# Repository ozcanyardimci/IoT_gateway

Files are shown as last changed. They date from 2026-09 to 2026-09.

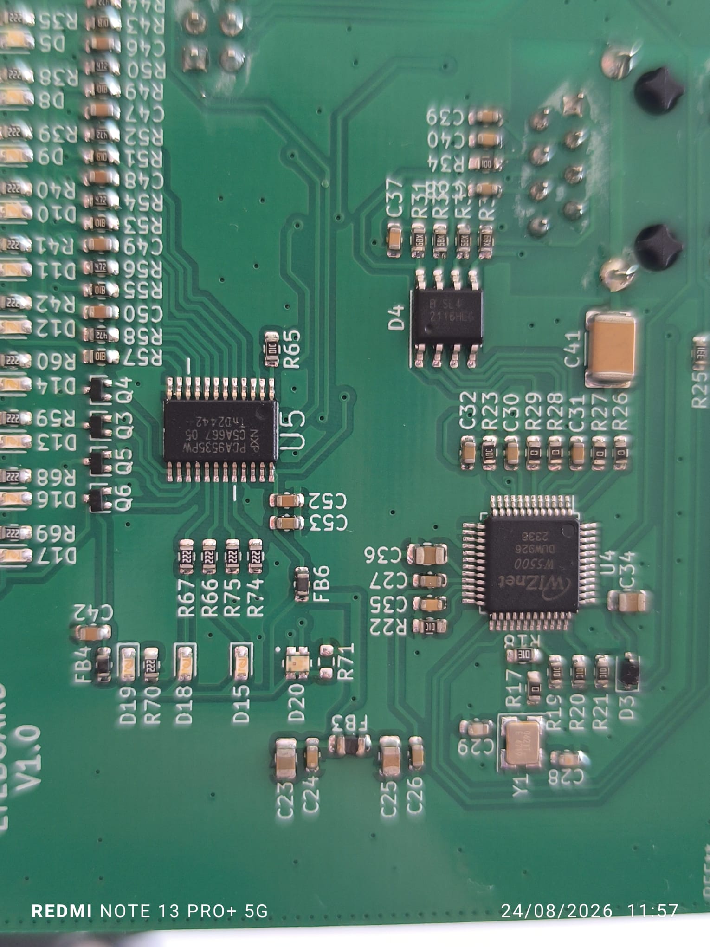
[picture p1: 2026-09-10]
reference-photos/2026-09-08-hardware-assembly-photos/photo_18_0372ed8b.jpg

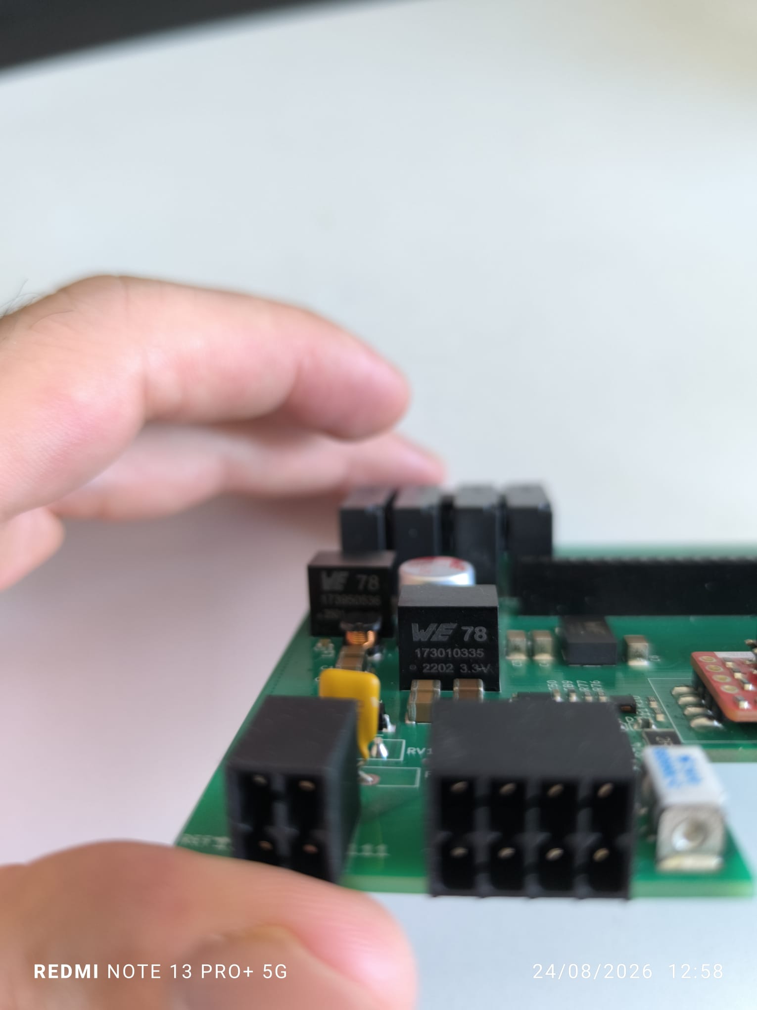
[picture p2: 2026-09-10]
reference-photos/2026-09-08-hardware-assembly-photos/photo_09_d7df375a.jpg

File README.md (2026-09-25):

# IoT_gateway

A 4G/LTE industrial IoT gateway, designed and built from the ground up as a hands-on
learning project spanning electronics, PCB design (KiCad), and embedded firmware
(ESP32-S3, PlatformIO/Arduino).

## What it does

- LTE Cat-1 cellular connectivity (with 2G fallback), WiFi, and 10/100 Ethernet
- 8x optically isolated digital inputs, 4x relay outputs
- Analog I/O (0-10V / 4-20mA input, 0-10V output)
- RS485 (galvanically isolated) and RS232 (not isolated — see `docs/subsystems/power.md`'s
  isolation table) serial interfaces
- 10-30 VDC field power input, DIN-rail enclosure target
- Firmware: web UI (commissioning portal), Modbus TCP/RTU master, MQTT (with TLS + resilience), OTA updates with rollback and signature verification, and a WireGuard VPN tunnel

## Architecture

Two physically separate PCBs connected by a board-to-board header, split for noise
isolation — RF/clock-sensitive circuitry stays off the same board as switching-noisy
circuitry:

- **Communications board** — ESP32-S3 (main MCU + WiFi), LTE modem, Ethernet controller,
  I2C GPIO expander for status indication.
- **I/O board** — power regulation, relay outputs, RS485/RS232 transceivers, analog
  input/output signal conditioning.

## Repository structure

```
hardware/
  kicad/              KiCad schematic + PCB projects (one per board)
  datasheets/          Component datasheets
  bom/                 Bill of materials
  reference-designs/   Vendor reference designs used during design
firmware/
  platformio.ini       PlatformIO project config (ESP32-S3, pioarduino platform)
  src/                 Firmware source
  include/, lib/       Headers / project-local libraries
docs/
  architecture.md       Block diagram and subsystem breakdown
  roadmap.md            Top-level 10-step plan and subsystem order/status
  build-log.md          Incremental build/bring-up log
  subsystems/           Per-subsystem build plans (requirements through sign-off)
```

## Build methodology

Built subsystem-first: each subsystem (power, core compute, WiFi, LTE, Ethernet, digital
I/O, relay outputs, analog I/O, RS485, RS232, status indication) is validated in isolation
before being consolidated into the final two-board design — simulation-first (KiCad/ngspice
for power and analog circuits), then a Rev-A prototype PCB as the first real hardware
checkpoint, ahead of committing to the full two-board fabrication run.

See `docs/architecture.md` and `docs/build-log.md` for details as the project progresses.

## Status

**Hardware:** all 11 subsystems complete on paper (power, core compute, digital inputs,
relay outputs, status indication, analog I/O, RS485, RS232, Ethernet, WiFi, LTE) —
protection, regulation, part selection, and schematic capture done for each, verified
pin-by-pin against manufacturer documentation. Both boards' schematics are merged into
one KiCad project (`hardware/kicad/ioboard+lteboard/`, see `docs/board-merge.md`),
fine-grained MCU pin assignment and the board-to-board connector are both wired, and a
full project-wide Electrical Rules Check passes clean (2026-09-23). Not yet built as
real hardware — Rev-A prototype PCB is the next physical milestone (`docs/roadmap.md`
step 8).

**Firmware:** the full protocol/driver/industrial/system-integration stack (Modbus,
MQTT+TLS, OTA with rollback and signature verification, WireGuard, rule engine, task
scheduler/watchdog, LTE-PPP backhaul, and more) is written and build-verified — a real
`pio run` links and flashes a complete image, and all 132 native unit tests pass
(2026-09-25). What's left needs the Rev-A hardware above: nothing in the firmware has
been exercised against real peripherals yet (`docs/roadmap.md`'s F5). See
`docs/build-log.md` and `docs/roadmap.md` for the full detail.

## License

TBD.

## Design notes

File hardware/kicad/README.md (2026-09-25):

# KiCad projects

Two physically separate PCBs (noise isolation between the communications board and the
I/O board), captured as one merged KiCad schematic project.

- **ioboard+lteboard/** — the active project. Both boards' subsystem sheets in one
  hierarchy:
  - IOBOARD side: `power`, `analog_io`, `digital_inputs`, `relay_outputs`, `rs232`,
    `rs485`
  - LTEBOARD side: `core-compute` (also carries WiFi — the ESP32-S3-WROOM-1U's radio is
    fixed at the module, WiFi only added an external antenna path here), `ethernet`,
    `lte`, `status_indication`

  The two boards are marked on the root sheet with a graphic border and label around each
  cluster of subsystem sheets — visual grouping only, no electrical meaning. This is
  where all schematic work happens going forward. Fine-grained pin assignment
  and the board-to-board interconnect wiring (the reason for the merge) are both done as
  of 2026-09-22/23, ERC-clean — see `docs/board-merge.md` for what the merge covered and
  what's verified connected, and a known open question about producing two separate
  physical-board PCB files from this one project at layout time.

- **ioboard/**, **lteboard/** — the original per-board projects, frozen as of the
  2026-09-19 merge. Kept as the historical record of each board's schematic capture up to
  that point; not edited further.

Each project uses hierarchical sub-sheets, one per subsystem (e.g. `power.kicad_sch`,
`relay_outputs.kicad_sch`).

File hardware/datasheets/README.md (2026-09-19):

# Datasheets, sources & application notes

Links only — no PDF binaries in this repo. Keeps repo size manageable, avoids stale local
copies of documents the manufacturer updates over time, and avoids redistributing
copyrighted PDFs. Updated as each subsystem is worked through.

## Power subsystem

| Part | Role | Datasheet / source |
|---|---|---|
| ESP32-S3-WROOM-1U | Main MCU module | [Espressif datasheet](https://documentation.espressif.com/api/resource/doc/file/3yD6w5Y5/FILE/esp32-s3-wroom-1_wroom-1u_datasheet_en.pdf) |
| Quectel EG915U-EU | LTE Cat-1 modem | [Quectel EG915U Series Hardware Design v1.1](https://quectel.com/content/uploads/2024/02/Quectel_EG915U_Series_Hardware_Design_V1.1.pdf) |
| WIZnet W5500 | SPI Ethernet controller | [WIZnet datasheet v1.1.0](https://docs.wiznet.io/img/products/w5500/W5500_ds_v110e.pdf) |
| NXP PCA9535PW | I2C GPIO expander | [NXP datasheet](https://www.nxp.com/docs/en/data-sheet/PCA9535_PCA9535C.pdf) · [TI second source](https://www.ti.com/lit/ds/symlink/pca9535.pdf) |
| MAX3232E | RS232 transceiver | [ADI/Maxim MAX3222E-MAX3246E family datasheet](https://www.analog.com/media/en/technical-documentation/data-sheets/max3222e-max3246e.pdf) |
| Mornsun TD321S485H-A | Isolated RS485 module | [Mornsun datasheet](https://www.mornsun-power.com/public/uploads/pdf/TD5(3)21S485H-A.pdf) |
| Panasonic ALDP105 | Relay (x4) | [Panasonic product page](https://na.industrial.panasonic.com/products/relays-contactors/mechanical-power-relays/lineup/general/series/1988/model/136824) · [Future Electronics PDF](https://www1.futureelectronics.com/doc/Panasonic/ALDP105.pdf) |
| Lite-On LTV-247 | Digital-input optocoupler | [Datasheet via LCSC](https://datasheet.lcsc.com/datasheet/pdf/6ec3b014c2c1b1e2589a5b88a431fe52.pdf?productCode=C115451) |
| AME8808 | Analog LDO | AME8808's own sheet isn't available in extractable form — using the AME8805/8813 same-family sheet as reference: [AME datasheet](https://www.ame.com.tw/datasheet/11-AME8805%208813_061313_R.13.pdf) |
| LM2904 | Analog stage op-amp | [Diodes Inc. LM2902/LM2904 datasheet](https://www.diodes.com/assets/Datasheets/LM2902-04.pdf) |

## Power modules & protection components

| Part | Role | Datasheet / source |
|---|---|---|
| Würth MagI3C-VDLM 171013801 | 3.3V-LOGIC and 5V rail buck module (two instances) | [Datasheet](https://www.we-online.com/en/components/products/datasheet/171013801.pdf) |
| Würth MagI3C-VDLM 171033801 | `VBAT_LTE` rail buck module (renamed from `3V3_LTE` 2026-09-13 — output retapped to ~3.82V, matching Quectel's typical VBAT, see `power.md` revision history), 3A | [Datasheet](https://www.we-online.com/components/products/datasheet/171033801.pdf) |
| Recom R1SX-3.33.3-R | Isolated supply, analog input field side, 3.3V-in/3.3V-out | [Recom datasheet](https://recom-power.com/pdf/Econoline/R1SX.pdf) · [DigiKey](https://www.digikey.com/en/products/detail/recom-power/R1SX-3.33.3-R/6708875) |
| Littelfuse RXEF135 | Input PTC resettable fuse | [Datasheet](https://www.littelfuse.com/assetdocs/resettable-ptc-rxef-datasheet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) |
| TI LM74610-Q1 | Ideal diode controller, reverse-polarity protection | [Datasheet](https://www.ti.com/lit/ds/symlink/lm74610-q1.pdf) |
| TI CSD18531Q5A | 60V N-channel MOSFET, driven by LM74610-Q1 | [Product page](https://www.ti.com/product/CSD18531Q5A) |
| TI TVS3300 | Input surge TVS, Flat-Clamp technology, 33V standoff, 40V max clamp at 35A | [Datasheet](https://www.ti.com/lit/ds/symlink/tvs3300.pdf) · [Product page](https://www.ti.com/product/TVS3300) |
| Würth WCAP-CSSA 8853522140011 | Input EMI/safety Y-cap | [Datasheet](https://www.we-online.com/components/products/datasheet/8853522140011.pdf) |
| Recom RK-0515S | Isolated 15V DC-DC module, analog output gain-stage supply (U7) | [Recom Econoline family PDF](https://recom-power.com/pdf/Econoline/RK_RH.pdf) — added 2026-09-08 for analog-io's "15V problem"; 3kVDC isolation stated directly, no re-verification gap |

Superseded parts (kept for traceability — see `docs/subsystems/power.md` revision history
for why): Toshiba SSM3J351R,LF (replaced by LM74610-Q1 + CSD18531Q5A), Littelfuse SMBJ36A
(replaced by TVS3300), Recom R1SX-3305 (replaced by R1SX-3.33.3-R — wrong output voltage
for the rail), Recom R05P215S (replaced by RK-0515S for the 15V-ANALOG-ISO rail —
unresolved isolation-rating gap on the R05P215S datasheet pull, see
`docs/subsystems/analog-io.md`'s revision history).

## Core compute subsystem

| Part | Role | Datasheet / source |
|---|---|---|
| Espressif ESP32-S3-WROOM-1U-N16R8 | Main MCU module | [Datasheet](https://documentation.espressif.com/api/resource/doc/file/3yD6w5Y5/FILE/esp32-s3-wroom-1_wroom-1u_datasheet_en.pdf) |
| Molex 216989-0001 | USB-C receptacle, USB2.0-only, 14-pin | [DigiKey product page](https://www.digikey.com/en/products/detail/molex/2169890001/13913746) |
| E-Switch TL1150AF070Q | Manual reset/boot push buttons (SW1, SW2) | [DigiKey product page](https://www.digikey.com/en/products/detail/e-switch/TL1150AF070Q/1556582) |

| Document | Covers | Source |
|---|---|---|
| Espressif ESP32-S3 Hardware Design Guidelines — Schematic Checklist | EN RC delay (10k+1uF), GPIO0 pull-up guidance, decoupling values/placement, USB D+/D- series resistor guidance | [Page](https://docs.espressif.com/projects/esp-hardware-design-guidelines/en/latest/esp32s3/schematic-checklist.html) |
| esptool documentation — Boot Mode Selection (ESP32-S3) | GPIO0's internal 45k pull-up and the need for an external 10k pull-down (not pull-up) to reliably enter download mode | [Page](https://docs.espressif.com/projects/esptool/en/latest/esp32s3/advanced-topics/boot-mode-selection.html) |

## Digital inputs subsystem

| Part | Role | Datasheet / source |
|---|---|---|
| Lite-On LTV-247 | 4-channel opto-isolator, digital inputs (x2 for 8ch) | [DigiKey product page](https://www.digikey.com/en/products/detail/liteon/LTV-247/4307982) - [LCSC product page](https://www.lcsc.com/product-detail/SMD-Optocouplers_LTV-247_C115451.html) - [Lite-On LTV-2X7 family datasheet](https://datasheet.lcsc.com/datasheet/pdf/6ec3b014c2c1b1e2589a5b88a431fe52.pdf?productCode=C115451) |
| Phoenix Contact MC 1,5/9-ST-3,5 | 8-channel + common field connector (J2) | [Newark product page](https://www.newark.com/phoenix-contact/mc-1-5-9-st-3-5/plug-free-3-5mm-9way/dp/14J3299) |

## Relay outputs subsystem

| Part | Role | Datasheet / source |
|---|---|---|
| Panasonic ALDP105 | SPST-NO relay (x4) | [Panasonic product page](https://na.industrial.panasonic.com/products/relays-contactors/mechanical-power-relays/lineup/general/series/1988/model/136824) · [Future Electronics PDF](https://www1.futureelectronics.com/doc/Panasonic/ALDP105.pdf) |
| Nexperia MMBT3904 | NPN driver transistor (one per relay channel) | [Nexperia datasheet](https://assets.nexperia.com/documents/data-sheet/MMBT3904.pdf) |
| Phoenix Contact MC 1,5/8-ST-3,5 | 8-position (4x COM+NO independent) field connector | [Newark product page](https://www.newark.com/phoenix-contact/mc-1-5-8-st-3-5/pluggable-terminal-block-8-position/dp/14J3298) · [Farnell product page](https://ie.farnell.com/phoenix-contact/mc-1-5-8-st-3-5/terminal-block-pluggable-8pos/dp/5089013) |

## Status indication subsystem

PCA9535PW (I2C GPIO expander) is already listed under "Power subsystem" above — no separate
entry needed, same reuse pattern as LM2904 under "Analog I/O subsystem" below. The 6 status
LEDs are generic 3mm THT parts (red/green/yellow/orange family, chosen for their ~1.8-2.2V
forward voltage — see `docs/subsystems/status-indication.md` Step 4 for why), no specific
manufacturer/part-number match — same "generic, no sourcing risk" treatment as this
project's standard passives.

## Analog I/O subsystem

| Part | Role | Datasheet / source |
|---|---|---|
| TI ADS1115 | 16-bit I2C ADC, isolated side (analog inputs) | [TI datasheet](https://www.ti.com/lit/ds/symlink/ads1115.pdf) |
| TI ISO1540 | I2C digital isolator, both channels bidirectional | [TI datasheet](https://www.ti.com/lit/ds/symlink/iso1541.pdf) (covers both ISO1540/ISO1541 in one document) |
| Microchip MCP4725 | 12-bit I2C DAC, isolated side (analog output) | [Microchip datasheet](https://ww1.microchip.com/downloads/en/devicedoc/22039d.pdf) |
| Littelfuse SMBJ15CA | Bidirectional TVS, analog input overvoltage protection (x2) | [Littelfuse datasheet](https://www.littelfuse.com/assetdocs/tvs-diodes-smbj-series-datasheet) |
| Phoenix Contact MC 1,5/4-ST-3,5 | 4-position field connector (AI1/AI2/AO + shared return) | [Newark product page](https://www.newark.com/phoenix-contact/mc-1-5-4-st-3-5/pluggable-terminal-block-4-position/dp/14J3294) |

The 15V-ANALOG-ISO supply module belongs to `power.kicad_sch`, not this sheet — see Recom
RK-0515S under "Power modules & protection components" above. An earlier candidate for that
rail, Recom R05P215S, is listed there under superseded parts (unresolved isolation-rating
gap, never actually implemented).

LM2904 (input buffers + output gain stage, 2 physical instances) reuses the part already
listed under "Power subsystem" above — no separate entry needed.

## RS485 subsystem

Protection network (GDT/TVS/choke/bias resistors) is Mornsun's own "Fig. 2: Port
protection circuit for harsh environments" from the transceiver's datasheet, not a
generic cascade — see `docs/subsystems/rs485.md` Step 2 for the full reasoning.

| Part | Role | Datasheet / source |
|---|---|---|
| Mornsun TD321S485H-A (TD5(3)21S485H-A series) | Isolated RS485 transceiver module | [Mornsun datasheet](https://www.mornsun-power.com/public/uploads/pdf/TD5(3)21S485H-A.pdf) — full PDF obtained 2026-09-08 (user-supplied): 3kVDC isolation, 500kbps max, built-in 47kΩ A/B pull-down, confirmed 10-pin pinout, and the harsh-environment reference circuit (Fig. 2) this section's other parts come from |
| Bencent B3D090L-C (GD1) | Gas discharge tube (GDT), 3-electrode: line pins wired A-B, third (common) electrode bonds to `EARTH` | [LCSC product page](https://www.lcsc.com/product-detail/Gas-Discharge-Tube-GDT_Bencent-B3D090L-C_C511253.html) — 90V DC spark-over, 5kA @ 8/20µs, 3-pole, 1.5pF. Doubly confirmed: flagged from the original teardown, and Mornsun's own datasheet names the base part "B3D090L" directly |
| Littelfuse SMBJ6.5CA (x3, D15/D18/D19; Mornsun Fig. 2 D1/D2/D3) | Bidirectional TVS diodes — D15 A-B differential clamp, D18/D19 line-to-EARTH clamp | [Littelfuse SMBJ series datasheet](https://www.littelfuse.com/assetdocs/tvs-diodes-smbj-series-datasheet) · [DigiKey](https://www.digikey.com/en/products/detail/littelfuse-inc/SMBJ6-5CA/285958) — 600W, DO-214AA. Mornsun-specified exact part. Same SMBJ family already used for analog-input protection (SMBJ15CA) |
| TDK ACM2520-301-2P (U14) | Common-mode choke (Mornsun Fig. 2 T1) | [TDK product page](https://product.tdk.com/en/search/emc/emc/cmf_cmc/info?part_no=ACM2520-301-2P-T002) · [LCSC](https://www.lcsc.com/product-detail/Common-Mode-Filters_TDK-ACM2520-301-2P-T002_C76577.html) — Mornsun-specified exact part |
| Generic 2.7Ω/2W (R34, R35; Mornsun Fig. 2 R1/R2) | Series current-limiting resistors | Mornsun-specified value/power rating |
| Generic 1MΩ (R36; Mornsun Fig. 2 R3) + 1nF/2kV (C23; Mornsun Fig. 2 C1) | RC snubber to EARTH | Mornsun-specified |
| Generic 4.7kΩ (R_pullup1, R_pulldown1) | External bias — Rpullup: VO (pin 7) to A; Rpulldown: RGND (pin 10) to B | Mornsun specifies only a current ceiling (<25mA) on VO/RGND, not a resistance — 4.7kΩ gives ≈1.1mA worst case, well inside that ceiling; picked and locked on the schematic 2026-09-10 |
| Phoenix Contact MC 1,5/3-ST-3,5 (J5) | 3-position field connector (A, B, EARTH) | [Newark product page](https://www.newark.com/phoenix-contact/mc-1-5-3-st-3-5/pluggable-terminal-block-3-position/dp/14J3293) — MPN 1840379 |

Superseded (2026-09-08, same day — kept here for traceability, not because they were
wrong parts, just replaced by Mornsun's own tested circuit once its datasheet was fully
readable): Bourns CDSOT23-SM712 (TVS), Würth WE-SL2 744227 (common-mode choke), generic
27Ω series resistors.

## RS232 subsystem

No dedicated protection component — decided against an added TVS network; see
`docs/subsystems/rs232.md` decision 3 for the full reasoning (datasheet's own application
circuit has none, receiver is separately rated safe to ±25V unpowered, and reference-design
photo evidence shows no dedicated protection stage for this port, unlike RS485).

| Part | Role | Datasheet / source |
|---|---|---|
| TI MAX3232EIPWR | RS232 transceiver, TSSOP-16, one channel used (DIN1/DOUT1/RIN1/ROUT1); channel 2 left unconnected | [TI MAX3232E datasheet](https://www.ti.com/lit/ds/slls664c/slls664c.pdf) — corrected 2026-09-10 from an earlier placeholder ("MAX3232EI" alone isn't a real SKU); picked over the ADI/Maxim equivalent (MAX3232EEUE+) for SnapEDA symbol/footprint availability |
| Phoenix Contact MC 1,5/3-ST-3,5 | 3-position field connector (TXD, RXD, GND) | [Newark product page](https://www.newark.com/phoenix-contact/mc-1-5-3-st-3-5/pluggable-terminal-block-3-position/dp/14J3293) — MPN 1840379, same part reused from RS485's connector (J5) |

## Ethernet subsystem

Schematic capture done 2026-09-13, cross-checked against WIZnet's own reference schematic
and, for the magjack, against both the reference-hardware's own LTEBOARD photos and the
part's own datasheet (read directly, not summarized) — see `docs/subsystems/ethernet.md`
for the full component list and decision history.

| Part | Role | Datasheet / source |
|---|---|---|
| WIZnet W5500 | SPI-to-MAC+PHY, 10/100 Ethernet | [W5500 datasheet v1.1.0](https://docs.wiznet.io/img/products/w5500/W5500_ds_v110e.pdf) — re-confirmed 2026-09-10 (pinout, crystal spec, SPI timing, LED pin behavior); chip visually matched on the reference LTEBOARD too; AVDD pin count corrected 2026-09-13 against the real KiCad symbol (6 pins: 4, 8, 11, 15, 17, 21 — not 4) |
| Würth Elektronik 7499010441 (WE-RJ45LAN) | RJ45 jack with integrated 1:1 transformer, 2 bi-color LEDs | [Datasheet](https://www.we-online.com/components/products/datasheet/7499010441.pdf) — full PDF read directly 2026-09-13 (user-supplied, not a summary): confirms isolation ≥1500V RMS, turns ratio, LED specs, AND the termination network — CTD/CRD terminated internally (75Ω/75Ω + 0.001µF/2kV + GDTs) into a combined "GND Shield" node (pin 8 + both shield pins are one net). Termination is now CONFIRMED integrated, no external Bob-Smith network needed — upgraded from the earlier "high confidence, not pin-level-guaranteed" call; see `docs/subsystems/ethernet.md` decision 4. Cross-checked against two related datasheets (Würth 7499011441A, Cetus J1B1211CCD) showing the same internal topology |
| Generic 0603 ferrite bead (FB1) | AVDD filtering, `3V3_LOGIC` → `3V3A` | WIZnet forum support guidance (named `HH-1M1608-121JT`, but any bead meeting spec works): 120Ω @ 100MHz (90Ω min), DCR 200mΩ max, 1A max rated current — confirmed via a real datasheet on inductor.com. Sourcing equivalents: Murata BLM18PG121SN1D, TDK MPZ1608S121A |

## WiFi subsystem

Radio itself is the ESP32-S3-WROOM-1U module, already covered under "Core compute
subsystem" above — nothing new to add there. This section is just the external antenna
path (J2), confirmed 2026-09-13 against the reference-hardware LTEBOARD photos (module
U.FL -> coax pigtail -> PCB-mount SMA jack, no PCB RF trace) and against the module's own
datasheet for the antenna gain ceiling.

| Part | Role | Datasheet / source |
|---|---|---|
| Amphenol RF 132163 | J2 - board-side SMA female jack, 2-hole flange, PCB/panel mount | [Product page](https://www.amphenolrf.com/en-us/part/132163/1014/) - representative real part matching the reference-hardware connector style; exact sourced part may differ, footprint deferred to layout |
| Generic U.FL-to-SMA pigtail | Coax jumper, module's onboard U.FL jack to J2, RG178, ~10-15cm | Reference-hardware photos (topology); no PCB trace involved, generic assembly |
| Waveshare "SMA 2.4G 2DB Antenna" | External antenna, SMA-male, 2dBi | [Product page](https://www.waveshare.com/sma-2.4g-2db-antenna.htm) - chosen to stay under the module's 2.33dBi certified-antenna gain ceiling (see below) |

**Antenna gain ceiling — from the module's own datasheet, not a general guideline:**
Espressif's ESP32-S3-WROOM-1U datasheet states the module's FCC/CE certification used a
2.33dBi reference antenna, and a higher-gain or different-type antenna "may require
additional testing, such as EMC." A generic 3dBi rubber-duck antenna would exceed that;
picked a 2dBi part instead to stay inside the certified envelope with margin.

## LTE subsystem

Quectel EG915U-EU Cat-1 modem (+2G fallback), on its own `VBAT_LTE` rail and one of the
project's 3 hardware UARTs. Own antenna path (same coax-pigtail/SMA-jack pattern as WiFi
above), own power-control (PWRKEY/RESET_N) circuit, and a level-shifted UART to a
micro-SIM interface. See `docs/subsystems/lte.md` for the full build plan, and
`hardware/bom/lte_bom.csv` for the complete part list. Schematic capture (Step 4) is
largely complete, including the UART level shifter (U5) — checked and confirmed correctly
wired 2026-09-19; see `lte.md` Step 4 for details.

| Part | Role | Datasheet / source |
|---|---|---|
| Quectel EG915UEUAC-N05-SNNSA | LTE Cat-1 modem, EU band variant | [Quectel EG915U Series Hardware Design v1.1](https://quectel.com/content/uploads/2024/02/Quectel_EG915U_Series_Hardware_Design_V1.1.pdf) (also listed under "Power subsystem" above) |
| TI TXB0102DCUR | 2-channel level shifter, 1.8V<->3.3V UART | [Datasheet](https://www.ti.com/lit/gpn/txb0102) |
| JAE SF53S006VCBR2000 | Micro-SIM push-push holder (J4), 6-contact | Matches reference-hardware LTEBOARD's SIM holder (`reference-photos/2026-09-08-hardware-assembly-photos/photo_23`, `photo_29`, `photo_30`) |
| STMicroelectronics ESDA6V1BC6 | SIM interface ESD protection, quad TVS array (SOT23-6L) | Confirmed on SnapEDA and in stock via Mouser's Turkey storefront (2026-09-15) |
| Littelfuse/Bourns SMAJ5.0A (representative) | VBAT reverse-standoff TVS protection | Closest standard part to Quectel's guidance (4.7V isn't a catalog value; 5.0V is the nearest step at or above it) |
| TE Connectivity/Linx ANT-LTE-MON-SMA-L | Off-board wideband antenna (~617MHz-3.8GHz), SMA, tilt/swivel | DigiKey/Mouser listings (2026-09-14) — band figure from distributor text only, not an independently-pulled Linx PDF |
| Quectel EG915U Series Reference Design v1.1 | ANT_MAIN matching network topology, SIM interface reference figures, PWRKEY/RESET_N driving circuits | [PDF](https://images.quectel.com/python/sites/2/2023/05/Quectel_EG915U_Series_Reference_Design_V1.1.pdf) |

**Still open / not yet a real sourced part:** J3 (board-side SMA jack — placed as a generic
`Conn_Coaxial` symbol, no MPN picked yet, same style as WiFi's J2 above); D4 (antenna ESD
diode — Quectel's own spec, <=0.05pF/<=5V, doesn't match any real catalog part found so far;
closest candidate is Littelfuse PGB1010603, but its 24V standoff exceeds the 5V ceiling —
see `lte.md` decision 7 addendum); Q4/Q5 (PWRKEY/RESET_N driver transistors — any generic
small-signal NPN works, e.g. MMBT3904/BC847; Rohm DTC043ZEBTL is a pre-biased single-part
alternative if BOM count matters later).

## Connectors & wiring standards

| Item | Role | Source |
|---|---|---|
| Phoenix Contact MC 1,5/2-ST-3,5 | Power input terminal block | [Datasheet](https://www.mouser.com/datasheet/3/507/5/phoenix_contact_1840366_en.pdf) |
| NFPA 70 (NEC) Table 310.15(B)(16) | Wire ampacity reference | Standard reference, consult a current NEC copy |
| Engineering ToolBox AWG current-rating table | Wire ampacity cross-check | https://www.engineeringtoolbox.com/wire-gauges-d_419.html |

## Application notes & reference designs

| Document | Covers | Source |
|---|---|---|
| TI TIDUBP3A — Reverse Battery Protection LM74610-Q1 | Reference design for the reverse-polarity stage: schematic, part selection, rated for 12/24V systems with load-dump survival past 30V | [PDF](https://www.ti.com/lit/ug/tidubp3a/tidubp3a.pdf) |
| TI SLYY127 — Flat-Clamp surge protection technology | Active-feedback clamping mechanism behind TVS3300 | [PDF](https://www.ti.com/lit/slyy127) |
| TVS3300 datasheet, Section 9 | TVS3300's own typical application circuit and layout guidance | [PDF](https://www.ti.com/lit/ds/symlink/tvs3300.pdf) |
| TI SLVA862 — Basics of eFuses | Background on inrush/reverse-polarity/overvoltage protection concepts | ti.com application report SLVA862 |
| WIZnet hardware design guide | Generic decoupling (0.1uF bypass, 10uF/4.7uF bulk, 3.3V regulator >=300mA) | [WIZnet Design Guide](https://docs.wiznet.io/Design-Guide/hardware_design_guide) |
| WIZnet W5500 reference schematic | Transformer/RJ45 config, isolation capacitors | [WIZnet W5500 ref-schematic](https://docs.wiznet.io/Product/Chip/Ethernet/W5500/ref-schematic) — full PDF variant (bare-transformer magjack, external Bob-Smith termination): [w5500-ref-rj45with20150406.pdf](https://docs.wiznet.io/img/products/w5500/w5500-ref-rj45with20150406.pdf), pulled 2026-09-10 for crystal/EXRES1/TOCAP/LED-resistor cross-check |
| Bourns RS-485 Port Protection Evaluation Board design note | GDT + series-limiting + TVS cascade topology reference for RS485 lines (uses a TBU current limiter instead of plain resistors — informed this project's cascade order, not its exact parts) | [PDF](https://www.bourns.com/docs/technical-documents/technical-library/circuit-protection/design-notes/bourns_rs485_evalboard4_design_note.pdf) |
| Würth ANP083 — RS-485 EMI filtering app note | Common-mode choke placement on an RS-485 interface (WE-SL2 family) | Referenced via Würth's WE-SL2 product page; direct PDF link 404'd 2026-09-08, retry before finalizing layout |

No single vendor app note covers this exact combination (wide 10-30V input protection with
multiple MagI3C modules) — the protection sequencing (fuse -> reverse-polarity ->
surge/TVS -> regulation) follows standard practice but isn't cross-checked against one
authoritative reference document.

## Reference open-hardware projects (patterns only, not copied)

| Project | Use |
|---|---|
| [espressif/kicad-libraries](https://github.com/espressif/kicad-libraries) | Official KiCad symbols/footprints |
| [OLIMEX/ESP32-GATEWAY](https://github.com/OLIMEX/ESP32-GATEWAY) | General ESP32 + Ethernet KiCad project structure reference only — its power stage isn't reusable (USB-powered, no field-voltage input) and its license status is unresolved (LICENSE says Apache-2.0, manual says CERN-OHL) |
| [Walter (QuickSpot/DPTechnics)](https://github.com/QuickSpot/walter-documentation) / [walter-arduino](https://github.com/QuickSpot/walter-arduino) | ESP32-S3 <-> cellular modem UART/power-sequencing/antenna pattern, for the LTE subsystem |
| [ElectroSoul-Technologies/ESP32-RS485_Gateway](https://github.com/ElectroSoul-Technologies) | RS485 direction-control + TVS protection reference |

## Not yet re-verified this session

Identified during the original teardown; re-pull the current datasheet from the
manufacturer/distributor before relying on exact figures.

- Toshiba SSM3J307T family — P-channel MOSFET behind the "PJ307U" board marking

(Bencent B3D090L-C — moved to "RS485 subsystem" above, re-verified 2026-09-08. Würth
7499010441 — moved to "Ethernet subsystem" above, re-verified 2026-09-10 including a
direct visual match against the reference hardware's own jack marking, then fully read
directly from the datasheet PDF 2026-09-13 confirming the termination network.)

## Not added yet

- DC-DC module and protection component datasheets for subsystems other than power — added
  as each subsystem's own module selection / protection design step is reached.

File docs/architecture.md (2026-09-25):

# Architecture

## Status

One-page block diagram drafted below (bus *kind*, not exact pin). Fine-grained pin
assignment is now done — see "Core-compute pin assignment" below for the exact GPIO
table, verified 2026-09-23 against the live schematic. One open item remains: adding
`platformio.ini`'s N16R8 flash/PSRAM override. The digital-input pin assignment (5 of 8
signals on GPIO3/39/42/46/47) was reviewed 2026-09-23 against Espressif's official
ESP32-S3 datasheet — accepted as-is, safe for this use; see "Fixed MCU constraints" and
the pin table below for the per-pin reasoning.

## Block diagram

```mermaid
graph TB
    subgraph LTEBOARD["Communications board (LTEBOARD)"]
        MCU["ESP32-S3\ncore compute + WiFi"]
        LTE["LTE modem\nQuectel EG915U-EU"]
        ETH["Ethernet controller\nWIZnet W5500"]
        IOEXP["I2C GPIO expander\nstatus LEDs"]
        MCU -- "UART" --> LTE
        MCU -- "SPI" --> ETH
        MCU -- "I2C" --> IOEXP
    end

    subgraph IOBOARD["I/O board (IOBOARD)"]
        PWR["Power input + protection\n+ 3.3V / 5V regulation"]
        RELAY["4x relay outputs"]
        DIN["8x digital inputs\nopto-isolated"]
        AIN["Analog input\n0-10V / 4-20mA"]
        AOUT["Analog output\n0-10V"]
        RS485["RS485\nisolated"]
        RS232["RS232"]
    end

    PWR -- "3.3V / 5V / GND\n(board-to-board header)" --> MCU
    MCU -- "GPIO x4 (header)" --> RELAY
    DIN -- "GPIO x8 (header)" --> MCU
    AIN -- "ADC (header)" --> MCU
    MCU -- "I2C (shared bus)" --> AOUT
    MCU -- "UART (header)" --> RS485
    MCU -- "UART (header)" --> RS232

    WIFI_ANT["WiFi antenna"] --- MCU
    LTE_ANT["LTE antenna"] --- LTE
    ETH_PORT["RJ45 Ethernet port"] --- ETH
```

## Bus assignment (by kind, not exact pin yet)

| Subsystem | Bus/interface | Notes |
|---|---|---|
| LTE modem | UART | AT commands |
| RS485 | UART | Isolated module handles the transceiver side |
| RS232 | UART | TI MAX3232EIPWR |
| Ethernet (W5500) | SPI | + 1 interrupt/CS line |
| I2C GPIO expander | I2C | Shared bus, status LEDs only |
| WiFi | Native (no external pins) | Antenna only |
| Digital inputs (8x) | GPIO, input | After opto-isolation |
| Relay outputs (4x) | GPIO, output | Driver stage TBD — see relay-outputs subsystem |
| Analog input (0-10V / 4-20mA) | ADC | After LDO + op-amp signal conditioning |
| Analog output (0-10V) | I2C (MCP4725 DAC) | ESP32-S3 has no built-in DAC peripheral (removed vs. ESP32/S2) — decided against PWM+filter in favor of an external I2C DAC chip (MCP4725), riding the same shared I2C bus as the ADC/expander rather than a dedicated GPIO line |

This uses all 3 hardware UARTs (LTE, RS485, RS232) — debug/console uses native USB instead
of a 4th UART.

## Board-to-board header — DECIDED 2026-09-22, FINAL 2026-09-22

Four generic connector symbols on the root sheet (`ioboard+lteboard.kicad_sch`) — two
physical parts per header (one on each board), same pin-numbering and net names on both
halves so they mate correctly. Footprints assigned at PCB layout (step 8/9): Samtec TSW
(male, THT) on the IOBOARD-side symbols, Samtec SSW (female, stacking socket) on the
LTEBOARD-side symbols, 2.54mm pitch throughout.

| Symbol | KiCad symbol | Gender | Board |
|---|---|---|---|
| J_PWR_IO | `Connector_Generic:Conn_02x05_Odd_Even` | Male (TSW) | IOBOARD |
| J_PWR_LTE | `Connector_Generic:Conn_02x05_Odd_Even` | Female (SSW) | LTEBOARD |
| J_SIG_IO | `Connector_Generic:Conn_02x12_Odd_Even` | Male (TSW) | IOBOARD |
| J_SIG_LTE | `Connector_Generic:Conn_02x12_Odd_Even` | Female (SSW) | LTEBOARD |

Pin map applies identically to both halves of each header (IO and LTE symbol get the
same net on the same pin number):

**J_PWR — 2x5, 10 pins:**

| Pin | Net |
|---|---|
| 1 | 3V3_LOGIC |
| 2 | VBAT_LTE |
| 3 | VBAT_LTE |
| 4 | GND_LOGIC |
| 5 | GND_LOGIC |
| 6 | GND_LOGIC |
| 7 | EARTH |
| 8 | spare |
| 9 | spare |
| 10 | spare |

Net names corrected 2026-09-22: the project's actual ground net is `GND_LOGIC`, not
plain `GND` (verified against every subsystem sheet). `EARTH` exists today as a
`global_label` in `core-compute`/`ethernet`/`lte` (LTEBOARD-side) but only a local
`label` in `rs485` (IOBOARD-side) — inconsistent; `rs485.kicad_sch`'s `EARTH` label
should be promoted to `global_label` for consistency, and is carried on this connector
regardless so board-to-board earth continuity actually exists physically.

**Caution:** `GND_LOGIC` and `EARTH` are KiCad `global_label`s, which connect by name
across the *entire* project regardless of physical board — ERC will show them as
connected even if pins 4-7 are never actually wired to this connector. ERC cannot be
trusted to catch a missing ground/earth pin here; wire it manually and double check.

**J_SIG — 2x12, 24 pins:**

| Pin | Net | Notes |
|---|---|---|
| 1 | RELAY1_CTRL | LTEBOARD (core-compute) → IOBOARD (relay_outputs) |
| 2 | RELAY2_CTRL | |
| 3 | RELAY3_CTRL | |
| 4 | RELAY4_CTRL | |
| 5 | DI1_MCU | IOBOARD (digital_inputs) → LTEBOARD (core-compute) |
| 6 | DI2_MCU | |
| 7 | DI3_MCU | |
| 8 | DI4_MCU | |
| 9 | DI5_MCU | |
| 10 | DI6_MCU | |
| 11 | DI7_MCU | |
| 12 | DI8_MCU | |
| 13 | RS485_TXD | rs485 (IOBOARD) <-> core-compute (LTEBOARD) |
| 14 | RS485_RXD | |
| 15 | RS232_TXD | rs232 (IOBOARD) <-> core-compute (LTEBOARD) |
| 16 | RS232_RXD | |
| 17 | I2C_SCL | shared bus: analog_io (IOBOARD) <-> core-compute/status_indication (LTEBOARD) |
| 18 | I2C_SDA | |
| 19 | spare | reserved — future differential analog upgrade |
| 20 | spare | reserved — future differential analog upgrade |
| 21 | spare | reserved — future differential analog upgrade |
| 22 | spare | reserved — general |
| 23 | spare | reserved — general |
| 24 | spare | reserved — general |

18 signals used, 6 spare. `ETH_*` (SPI) and `LTE_PWRKEY`/`LTE_RESET`/`LTE_TXD`/`LTE_RXD`
do NOT cross — `ethernet`, `lte`, and `core-compute` are all LTEBOARD-side already.
`analog_io` only exposes I2C pins today (no ADC/PWM GPIO lines drawn), so analog I/O
already rides the shared I2C bus above.

## Core-compute pin assignment (exact GPIO, verified 2026-09-23)

All 28 cross-subsystem signals now have a real GPIO on `core-compute.kicad_sch`,
confirmed by direct coordinate-level trace against the live schematic (each
hierarchical label's position matched to its nearest ESP32-S3-WROOM-1U symbol pin, not
assumed from the pin-planning notes). Board-to-board signals (crossing IOBOARD <->
LTEBOARD via `J_SIG`) marked accordingly; same-board signals (LTE/Ethernet, both
LTEBOARD-side) wire directly to `core-compute` without crossing the header.

| Signal | GPIO | Crosses header? | Notes |
|---|---|---|---|
| `I2C_SDA` | GPIO8 | No | Shared bus: analog_io DAC/ADC + status_indication expander |
| `I2C_SCL` | GPIO9 | No | |
| `ETH_SCSN` | GPIO10 | No | W5500 SPI chip-select |
| `ETH_MOSI` | GPIO11 | No | W5500 SPI |
| `ETH_SCLK` | GPIO12 | No | W5500 SPI |
| `ETH_MISO` | GPIO13 | No | W5500 SPI |
| `ETH_INTN` | GPIO14 | No | W5500 interrupt |
| `ETH_RESET` | (GPIO9/38?) | No | CONFLICT: architecture.md originally planned GPIO38, but firmware (ethernet_link.cpp) uses GPIO9. GPIO9 is the BOOT button on standard S3 modules. Requires hardware-revision confirmation before changing code. |
| `LTE_TXD` | GPIO17 | No | MCU -> modem |
| `LTE_RXD` | GPIO18 | No | modem -> MCU |
| `RELAY1_CTRL` | GPIO7 | Yes | |
| `RELAY2_CTRL` | GPIO38 | Yes | |
| `RELAY3_CTRL` | GPIO43 (TXD0) | Yes | Shares the module's default UART0 TX pin — fine since UART0/console isn't used for anything else here, but worth remembering if debug UART is ever needed |
| `RELAY4_CTRL` | GPIO44 (RXD0) | Yes | Same caveat as RELAY3_CTRL, RXD0 side |
| `RS232_TXD` | GPIO5 | Yes | |
| `RS232_RXD` | GPIO6 | Yes | |
| `RS485_TXD` | GPIO1 | Yes | |
| `RS485_RXD` | GPIO2 | Yes | |
| `LTE_PWRKEY` | GPIO15 | No | |
| `LTE_RESET` | GPIO16 | No | |
| `DI1_MCU` | GPIO40 | Yes | |
| `DI2_MCU` | GPIO41 | Yes | |
| `DI3_MCU` | GPIO48 | Yes | |
| `DI4_MCU` | GPIO3 | Yes | Strapping pin (JTAG source select), but only strapped if an eFuse this project never burns is set — verified safe 2026-09-23, see "Fixed MCU constraints." Optional weak pull-up removes the caveat entirely if wanted. |
| `DI5_MCU` | GPIO39 | Yes | Not a strapping pin (verified 2026-09-23, corrects an earlier note) — default JTAG (MTCK), safe as plain GPIO |
| `DI6_MCU` | GPIO42 | Yes | Not a strapping pin (verified 2026-09-23) — default JTAG (MTMS), safe as plain GPIO |
| `DI7_MCU` | GPIO46 | Yes | Strapping pin (boot-mode, paired with GPIO0), irrelevant unless GPIO0 is also forced low — safe for normal operation, see "Fixed MCU constraints" |
| `DI8_MCU` | GPIO47 | Yes | Not a strapping pin (verified 2026-09-23) — safe as plain GPIO |

Free/unassigned: GPIO0 (strapping, not yet given an explicit No-Connect or strapping
resistor treatment — separate open item), GPIO21/35/36/37/45 (No-Connect flagged,
matches the documented exclusions below).

## Known gaps — deferred to next generation (flagged 2026-09-22)

Reviewed against a comparable commercial reference design. Not blocking this build, but
should not be forgotten:

- **No surge/ESD/transient protection on field terminals** (DI, relay outputs, RS485,
  power input) — industrial field wiring needs TVS diodes or equivalent on every
  externally-exposed pin. Not designed yet.
- **No reverse-polarity / overcurrent protection on the power input.**
- **No confirmed galvanic isolation between field-side and logic-side power domains**
  beyond the DI opto-couplers and relay contacts already in place (e.g. an isolated
  DC-DC for the field rail).
- **Analog I/O is single-ended (1-2 ADC lines + PWM/RC output), not differential /
  4-20mA current-loop** like the reference design's AIN+/AIN-, AOUT+/AOUT-. This was
  already an intended subsystem (see subsystem list) — the gap is the signal topology,
  not the existence of the subsystem. 3 spare pins reserved on J_SIG (above) to allow
  adding differential inputs later without a new connector.
- **`core-compute.kicad_sch`'s DI/RELAY pin assignments verified 2026-09-23** (direct
  coordinate-level check against the live schematic — see the pin table below). Not a
  gap; kept here as the record of when it was last confirmed.

None of these are needed for a first prototype/bring-up run; they matter before calling
this an "industrial" product.

## Fixed MCU constraints (ESP32-S3)

- GPIO26-32: reserved, in-package SPI flash — never reuse
- GPIO33-37: reserved, in-package octal PSRAM — never reuse
- **Strapping pins (verified 2026-09-23 against Espressif's official ESP32-S3 datasheet +
  WROOM-1/1U module datasheet — only these four, nothing else, is a strapping pin):**
  - GPIO0 — boot-mode select (SPI boot vs download boot). Avoid driving externally during
    reset unless deliberately entering download mode.
  - GPIO3 — JTAG signal source select. Datasheet: "does not have any internal pull
    resistors and the strapping value must be controlled by the external circuit that
    cannot be in a high impedance state" — but this value is only read at all if the
    `EFUSE_STRAP_JTAG_SEL` eFuse has been burned (not the factory default, and not
    something this project's flow does). Effectively safe as-is; a cheap weak external
    pull-up costs nothing and removes the caveat entirely regardless of eFuse state.
  - GPIO45 — VDD_SPI voltage select. Not used by any subsystem on this project.
  - GPIO46 — paired with GPIO0 for chip boot-mode selection (SPI boot vs download boot).
    Irrelevant to normal runtime boot whenever GPIO0 reads high, which is GPIO0's own
    power-on default — only matters if GPIO0 is *also* forced low at the same moment
    (e.g. an in-field reflash procedure that drives GPIO0), in which case GPIO46's level
    picks the download sub-mode. Not a risk for a signal that's only ever read as a DI
    input under normal operation.
- **GPIO39/40/41/42, 47, 48 are NOT strapping pins** (correction 2026-09-23 — an earlier
  note here called 39/42/47 "nonstandard reset behavior," not substantiated against the
  official datasheet on recheck; superseded). GPIO39-42 are the chip's *default* JTAG
  pins (MTCK/MTDO/MTDI/MTMS) but only active as JTAG if that signal source is selected
  (see GPIO3 above) — otherwise ordinary GPIOs, safe to reuse, at the cost of losing
  on-pin JTAG debug if it's ever needed. GPIO47/48's only alternate function is an
  optional differential SPI clock pair, active only if firmware explicitly selects it.
  GPIO21 has no documented special function either — the toolchain sanity-check sketch
  used it for a throwaway simulated LED, which is why it was flagged as "already spoken
  for" here, not because of any reset-time risk; free to reuse for a real subsystem
  signal like any other plain GPIO.
- Verified via two official Espressif sources (chip datasheet + WROOM-1/1U module
  datasheet); the full Technical Reference Manual wasn't reachable to cross-check in this
  pass — treat the GPIO46 "boot log" behavior specifically as unconfirmed if it ever
  becomes load-bearing.
- 3 hardware UART controllers available (LTE + RS485 + RS232 fits with debug/console on
  native USB)

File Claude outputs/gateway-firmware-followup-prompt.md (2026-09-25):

# Follow-up on the Priority 4/5 fixes — please clarify before I sign off

Thanks for the P4/P5 pass. Before I mark these done, I need answers on a few specific points — some are just documentation accuracy, one might be a real bug you found but didn't fully flag.

## 1. P4.1 — Ethernet reset pin: is GPIO9 actually referenced in code, or is this a docs-only note?

Your summary says "the code (GPIO9) and docs (GPIO38) mismatch has been documented." GPIO9 is `PIN_I2C_SCL` in `pin_map.h` — the shared I2C bus clock line. If `ethernet_link.cpp` (or anywhere else) actually passes or references GPIO9 for the Ethernet reset pin, that is not a documentation mismatch — that's a live pin collision between Ethernet reset and the I2C bus, and it needs to be treated as a real, higher-priority hardware conflict, not a docs note awaiting a hardware revision.

Please tell me exactly:
- The file and line where GPIO9 shows up in connection with Ethernet reset (if it does at all).
- Whether this GPIO9 reference is in actual firmware code, or only in a comment/doc you were reconciling.

If it turns out to be a real code-level reference to GPIO9 for Ethernet reset, do not change anything yet — just report back with the exact location so we can figure out how that got there before deciding what to do about it.

## 2. P4.5 — does the OTA rollback checkpoint still work for a freshly-commissioned device?

You moved `g_ota.confirmValid()` to run after a successful network connection, which is correct for the main case (a broken OTA image that can't reach the network now correctly stays unconfirmed and rolls back). But the case I need confirmed: what happens on a boot where the device has no configuration yet and goes straight into the commissioning portal instead of attempting a normal network connect? Does `confirmValid()` ever get called on that path, or does a freshly-commissioned device now never confirm?

Please check this specific path and either confirm it's already handled correctly, or fix it so entering the commissioning portal (a legitimate operational state on its own) also reaches the confirm checkpoint.

## 3. P5.2 — event log escaping: does it actually neutralize the field delimiter?

The original bug was about a **comma-separated** log format where an unescaped comma in a logged value could inject extra fields. Your summary title calls this "Event Log JSON Escaping" and describes escaping quotes and control characters (`\n`, `\r`, `\t`) — it doesn't mention commas.

Please confirm:
- Is the actual on-disk log format CSV (comma-separated) or JSON? (The original finding assumed CSV — if that's changed, say so.)
- If it's still CSV: does the escaping you added specifically handle a comma appearing inside a logged field, or only quotes/control characters? If commas aren't handled, that's the original vulnerability still open — please fix it to escape (or otherwise safely neutralize) the actual field delimiter, not just quote/control characters.

## 4. P4.7 — did you check the board manifest, or apply the flag defensively without checking?

The instruction was to check the `esp32-s3-devkitc-1` board manifest's actual default for USB-CDC-on-boot before making a change, and report which case it was (manifest already defaulted to CDC → no real conflict existed; manifest defaulted to physical UART0 → a real conflict existed and RELAY3/RELAY4 were actually colliding with the console). The fix you applied (`-D ARDUINO_USB_CDC_ON_BOOT=1`) is fine either way, but I want the documentation to reflect what was actually true, not an assumption.

Please tell me which case it was, and where in the manifest you confirmed it (or say plainly if you applied the flag without checking, so I know to verify it myself).

## 5. P4.3 (OTA anti-downgrade) — here's how to proceed

First, check whether this codebase already has a firmware-version identifier somewhere — a `FIRMWARE_VERSION` define, a build-time-injected string/number, anything currently used for logging or telemetry that identifies which build is running. Search before assuming there's nothing.

- If something like that already exists: use it as the basis for comparison against the OTA trigger's `version` field.
- If nothing exists: implement the simplest safe scheme — a monotonic `uint32_t` build number, stored in NVS alongside the rest of `device_config` (add a new field following the existing `device_config` getter/setter pattern), compared against the trigger's declared version with plain integer greater-than. Any trigger payload whose `version` field doesn't parse as a valid non-negative integer should be rejected outright — fail closed, consistent with how the rest of `ota_trigger` already handles malformed fields. Don't implement semver parsing or anything more elaborate than that; it's not needed here.

Add a test covering: reject equal version, reject lower version, accept strictly higher version, reject unparseable version field.

## 6. T1/T3 (Modbus and OTA native tests) — please don't add ArduinoFake, use the existing stub pattern instead

This codebase already has an established, working pattern for exactly this problem — hand-written stub headers matching the real third-party API surface, paired with an instrumented fake implementation, compiled and run as a native behavior test (this is how the LTE/PPP work and the commissioning-portal/device_config work were verified earlier in the project — see any existing `stub/`-style headers already in the test tree for the shape to follow). Bringing in a third-party mocking framework now would introduce a second, inconsistent testing style alongside the one already in use for no real benefit.

Please write minimal hand-rolled fake headers for the specific pieces `modbus_master` and `ota_update` actually call (a fake `HardwareSerial` covering just the read/write/available surface `modbus_master` uses, and a fake `Update` covering just `begin`/`write`/`end`/rollback-related calls `ota_update` uses) — matching the same style already used elsewhere in this project's test tree, not a general-purpose mock of the whole Arduino API surface. Scope each fake to only what's actually called; don't build out unused API surface.

---

Reply with the answers to 1–4 first (these are quick confirmations, no code needed for most of them except wherever you find an actual gap), then proceed with 5 and 6 as new implementation work. As before: if anything turns out not to apply once you look, say so rather than forcing a change.

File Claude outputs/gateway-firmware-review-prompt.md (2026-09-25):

# Review request: DIY ESP32-S3 IoT gateway firmware (F1–F4)

## Who you are talking to and what this document is

You are being asked to perform an independent, detailed, **read-only** review of a firmware codebase. This document gives you the full context you need: what the project is, why it exists, how it's built, what's been verified so far, and a specific list of findings from a prior review pass that need independent verification.

**Do not modify, fix, refactor, or "clean up" any code or documentation in this repository.** Your job is to review, verify, and report — point out anything wrong, missing, inconsistent, or worth flagging, in as much detail as you can, but leave every file exactly as you found it. The person running this review will decide what to fix and do it themselves (or ask for that separately). If you believe something needs a code change, describe the change in your report; do not make it.

---

## 1. Project purpose

This is a from-scratch DIY IoT gateway project — both PCB hardware design (KiCad) and firmware (PlatformIO/ESP32-S3) — built by an electrical & electronics engineering (EEE) student as a hands-on learning project covering hardware and firmware development end to end. The student has prior hands-on experience with STM32/PIC microcontrollers, KiCad PCB design, industrial protocols (Modbus, MQTT-based IoT gateways), and completed a gateway-focused internship at an industrial-IoT company before starting this project.

The functional target is to replicate the capabilities of a real commercial industrial IoT gateway product (multi-backhaul connectivity — Ethernet/WiFi/cellular — with Modbus RTU polling, MQTT telemetry, remote configuration, and OTA updates). The specific commercial product being used as a functional reference is intentionally not named in this document or anywhere in the repository — treat the "reference device" mentions below as "a comparable commercial industrial gateway product," not a specific brand to look up or reproduce trademarked material from. Where a design decision below says "matches the reference device's pattern," that's describing an architecture pattern (e.g. "wired-primary with cellular failover"), not copying any proprietary implementation detail.

## 2. Hardware overview

Target MCU module: **ESP32-S3-WROOM-1U-N16R8** — 16MB Quad SPI flash, 8MB octal-mode PSRAM. Board profile in the build system is a generic "esp32-s3-devkitc-1" (N8) profile with flash/PSRAM explicitly overridden to match the real N16R8 module (see platformio.ini below).

Subsystems, with their real GPIO assignments (`firmware/include/pin_map.h`):

- **Shared I2C bus** (GPIO8 SDA / GPIO9 SCL) — carries three devices:
  - ADS1115 4-channel ADC (I2C addr 0x48) — analog input
  - MCP4725 12-bit DAC (I2C addr 0x60) — analog output
  - PCA9535PW 16-bit I2C GPIO expander (I2C addr 0x20) — drives the status LEDs
- **Ethernet**: WIZnet W5500 over SPI (CS=GPIO10, MOSI=GPIO11, SCLK=GPIO12, MISO=GPIO13, INT=GPIO14). No hardware reset pin currently wired to the MCU (flagged as a gap below — a subsystem doc says this was meant to have one).
- **LTE modem**: Quectel EG915U-EU, UART + control lines (TXD=GPIO17, RXD=GPIO18, PWRKEY=GPIO15, RESET=GPIO16, both power/reset lines via NPN low-side driver transistors, active-high at the MCU GPIO / active-low at the modem pin — this polarity was independently confirmed against the modem's hardware design doc, the real KiCad schematic, and circuit theory).
- **4x relay outputs** (GPIO7, GPIO38, GPIO43, GPIO44 — the last two share the module's default UART0 TX/RX pins, which is stated as safe because UART0 is otherwise unused; see gap list item about this).
- **RS232** (MAX3232EIPWR level shifter, TXD=GPIO5, RXD=GPIO6).
- **RS485** (isolated transceiver, TXD=GPIO1, RXD=GPIO2) — used for Modbus RTU master polling of downstream field devices.
- **8x digital inputs**, opto-isolated, active-low (GPIO40, 41, 48, 3, 39, 42, 46, 47 — two of these, GPIO3 and GPIO46, are ESP32-S3 strapping pins; this was reviewed and accepted as safe for this design, not overlooked).

Hardware development status: schematic-level design is done for the subsystems above (Rev-A). No PCB has been fabricated yet — there is no physical board to test firmware against. All firmware verification so far has been software-only (see Section 5).

## 3. Firmware architecture

- **Build system**: PlatformIO with the pioarduino fork of the ESP32 platform, `framework = arduino` (i.e. running on top of the arduino-esp32 3.x core, which itself wraps ESP-IDF — the exact ESP-IDF version this core pins is v5.3.1, confirmed by inspecting arduino-esp32's own version-lock files during development).
- **Partition table**: custom `partitions_16mb_ota.csv` — dual OTA app slots (`app0`/`app1`, 4MB each) + otadata + nvs + spiffs + coredump, sized for the real 16MB flash (the stock 8MB-board default partition table was wrong for this module and was overridden).
- **Two build environments** in `platformio.ini`:
  - `[env:esp32-s3-devkitc-1]` — the real target build.
  - `[env:native]` — host-native g++ build (`-std=gnu++17 -Wall -Wextra`) for hardware-independent pure-logic modules, run via `pio test`.
- **Library dependencies** (`lib_deps`, pinned to GitHub URLs rather than the PlatformIO registry, because the development environment could not reach the PlatformIO registry but could reach github.com directly):
  - `knolleary/pubsubclient` (MQTT client)
  - `esphome-libs/wireguard` v0.4.6 (WireGuard tunnel — this is the modern name for the library formerly published as `droscy/esp_wireguard`)
  - `esphome-libs/libsodium` v1.10021.11 (WireGuard's own crypto dependency)
- **LTE/cellular backhaul** uses arduino-esp32's own **built-in `PPP` library** (`PPP.h`, wrapping ESP-IDF's `esp_modem` component) — no separate `lib_deps` entry needed, it ships inside the arduino-esp32 3.x core itself, gated behind the `CONFIG_LWIP_PPP_SUPPORT` ESP-IDF Kconfig option. Because this project's `framework = arduino` build uses a **precompiled** Arduino core (Kconfig options normally have no effect against a precompiled core), `platformio.ini` adds an explicit `custom_sdkconfig = CONFIG_LWIP_PPP_SUPPORT=y` override — pioarduino's fork is confirmed (via its own issue tracker) to support this override mechanism for precisely this situation.
- **No real `pio run` build has been performed yet.** This is explicitly called out below (Section 5) — it is the single biggest unverified assumption across the whole codebase.

### Project phase structure (as tracked in the repo's own `docs/roadmap.md`)

- **F1 — Protocol/logic layer**: pure, hardware-independent protocol code (Modbus PDU encoding/decoding, Modbus RTU/TCP framing, Modbus CRC16, MQTT JSON payload construction, shared I/O state struct). Unit-tested via the `[env:native]` build.
- **F2 — Drivers**: thin hardware wrapper classes for every subsystem in Section 2 (I2C devices, SPI Ethernet, UART LTE/RS485/RS232, digital I/O).
- **F3 — Industrial-grade layer**: NVS-backed device configuration storage, a WiFi-AP + web-form commissioning portal, MQTT-over-TLS client config, a simple condition→relay rule engine, a rotating diagnostic event log, NTP time sync, OTA firmware update with bootloader rollback support, a startup brownout/power-safety delay, boot reset-cause classification, and an outbound-host allowlist (a defense-in-depth boundary meant to stop firmware from connecting to arbitrary hosts).
- **F4 — System integration**: ties everything together in `main.cpp`. Adds a real-time task watchdog, a dedicated FreeRTOS task for Modbus RTU polling (separated from the main loop because Modbus's inter-byte frame-gap timing can't tolerate being stalled by a slow TLS handshake or flash write elsewhere), a WireGuard tunnel, an MQTT-triggered OTA update flow with cryptographic signature verification (ECDSA-P256 via mbedtls) on top of the OTA/rollback mechanism from F3, and cellular (LTE/PPP) backhaul as a third connectivity tier alongside Ethernet and WiFi.
- **F5 — Rev-A hardware bring-up**: not started. This is where F2–F4 get verified against real hardware for the first time, once a PCB exists.

### Networking / backhaul priority

`main.cpp`'s `connectNetwork()` tries, in order: **Ethernet → LTE → WiFi**, each with a bounded wait (not indefinite). This ordering — LTE ahead of WiFi — was a deliberate choice: it mirrors the "wired-primary with cellular failover" pattern of the commercial reference device, while keeping WiFi as a last-resort tier (rather than removing it) because it's genuinely useful for bench/development testing without an Ethernet cable or an active SIM. **This is boot-time-only** — `connectNetwork()` runs once in `setup()`; there is no live "backhaul dropped mid-operation, switch automatically" monitoring in the main loop for any of the three tiers. This is a known, explicitly-scoped limitation, not an oversight — see the gap list.

## 4. Repository layout

```
firmware/
  platformio.ini              # build config (see Section 3)
  partitions_16mb_ota.csv     # custom OTA-capable partition table
  include/pin_map.h           # single source of truth for every GPIO assignment
  src/main.cpp                # F4 integration — the ~650-line file wiring everything together
  lib/                        # one directory per module (see inventory below)
  test/                       # Unity test directories, one per pure-logic module that has tests
docs/
  roadmap.md                  # dated, detailed project log — what was built, decided, and why
  architecture.md             # hardware pin-assignment table and cross-subsystem wiring decisions
  subsystems/*.md             # per-subsystem hardware design notes
CLAUDE.md                     # a parallel, more decision-log-flavored project history file
```

`docs/roadmap.md` and `CLAUDE.md` between them contain a detailed, dated history of what was built, what was researched (with sources), what was decided and why, and what's still open. They are useful background but **were themselves found to contain some now-stale claims** during the review that produced the gap list below — see the "Documentation debt" section of the gap list. Don't take either doc's claims about current code state at face value; verify against the actual files.

### Full module inventory (`firmware/lib/`)

**F1 — protocol/logic (pure, no hardware dependency):**
| Module | Purpose |
|---|---|
| `modbus_pdu` | Modbus PDU (function-code payload) encode/decode — read coils, read discrete inputs, read holding/input registers, write single/multiple registers |
| `modbus_crc` | Modbus RTU CRC16 checksum |
| `modbus_rtu` | RTU frame wrapping (address + PDU + CRC) |
| `modbus_tcp` | Modbus TCP / MBAP header framing |
| `mqtt_payload` | Builds the JSON telemetry payload published over MQTT |
| `io_state` | Shared struct holding current DI/AI/relay/AO state, with bounds-checked accessors |

**F2 — drivers (hardware wrappers):**
| Module | Purpose |
|---|---|
| `di_driver` | Reads the 8 digital inputs |
| `relay_driver` | Drives the 4 relay outputs |
| `ads1115_adc` | ADS1115 I2C ADC driver |
| `mcp4725_dac` | MCP4725 I2C DAC driver |
| `status_leds` | Status LED control via the PCA9535 I2C expander |
| `pca9535` | Generic PCA9535 16-bit I2C GPIO expander driver (used by `status_leds`) |
| `wifi_link` | WiFi station-mode connect/status wrapper |
| `ethernet_link` | W5500 Ethernet connect/status wrapper |
| `lte_modem` | LTE modem power-on/power-off/hard-reset GPIO sequencing (PWRKEY/RESET only — **no longer** owns the modem's UART, see F4's `lte_ppp`) |
| `rs485_serial` | RS485 UART wrapper |
| `rs232_serial` | RS232 UART wrapper |

**F3 — industrial-grade layer:**
| Module | Purpose |
|---|---|
| `device_config` | NVS (`Preferences`)-backed persistent config: WiFi creds, MQTT broker, TLS material, WireGuard config, OTA host/CA cert, LTE APN/SIM PIN |
| `commissioning_portal` | WiFi-AP + web form for first-time device setup, writes into `device_config` |
| `mqtt_tls_config` | TLS client setup for the MQTT connection (`NetworkClientSecure`) |
| `mqtt_client_wrapper` | Wraps `PubSubClient` — connect/reconnect, subscribe, publish, an outbox queue for offline buffering |
| `rule_engine` | Simple condition (DI/AI state) → action (relay output) rule evaluation, bounds-checked against `io_state`'s real channel counts |
| `event_log` | Rotating diagnostic log (timestamp, level, tag, message), persisted to flash |
| `ntp_time` | NTP time sync wrapper |
| `ota_update` | OTA firmware update writer + bootloader rollback confirmation (`Update` library + `esp_ota_ops.h`) |
| `power_safety` | Startup brownout-detection backoff delay |
| `reset_reason` | Classifies the boot reset cause |
| `net_allowlist` | Outbound-host allowlist — fails closed by design; every outbound connection (MQTT broker, NTP, WireGuard peer, OTA download host) is meant to be checked against it before dialing out |

**F4 — system integration:**
| Module | Purpose |
|---|---|
| `system_watchdog` | Wraps ESP-IDF's Task Watchdog Timer; both the main loop task and the Modbus task register and feed it |
| `modbus_master` | RS485 Modbus RTU master polling engine, runs on its own dedicated FreeRTOS task, mutex-protects the shared readings cache |
| `wireguard_link` | Wraps the `esphome-libs/wireguard` library for a WireGuard tunnel |
| `ota_trigger` | Hand-rolled parser for an MQTT-delivered OTA command payload (`url`/`sha256`/`sig`/`size`/`version` fields) — untrusted network input, meant to fail closed on anything malformed |
| `ota_session` | Orchestrates one OTA attempt end-to-end: allowlist-gates the download host, downloads over HTTPS, streams into both the OTA writer and a SHA-256 hasher, only finalizes if hash + signature both check out |
| `image_verify` | SHA-256 streaming hash + ECDSA-P256 signature verification via mbedtls — the actual cryptographic gate for OTA image authenticity |
| `url_host` | Extracts a hostname from a `https://`-prefixed URL string, for allowlist checking |
| `lte_ppp` | Wraps arduino-esp32's built-in `PPP`/`PPPClass` for cellular data backhaul — owns the LTE modem's UART (which `lte_modem` no longer does) |

`firmware/src/main.cpp` is the integration point: it constructs one global instance of nearly every module above, does the full boot sequence (local I/O init, commissioning-portal fallback if unconfigured, config load, allowlist population, network connect, NTP sync, WireGuard start, MQTT connect + OTA-topic subscribe, Modbus task start), and runs the cooperative main loop (`loop()`) that polls/services everything except Modbus (which runs on its own task).

## 5. Verification status — what has and hasn't been checked

**No physical hardware exists yet**, and **no real `pio run` build/link pass has been performed**. Given that, verification so far has consisted of:

1. Careful, source-checked research before writing anything non-trivial — API signatures, register maps, and protocol details were checked against real datasheets/library source/RFC text (via web fetches during development), not written from memory/assumption. Several of these citations are recorded in the header comments of the files themselves and in `docs/roadmap.md`/`CLAUDE.md`.
2. Compiling every individual module against **hand-written stub headers** that reproduce the real third-party API signatures (Arduino core functions, `Preferences`, `PubSubClient`, `Update`, mbedtls, `PPPClass`, etc.), using a real host `g++` with `-Wall -Wextra`, to at least confirm each module type-checks cleanly against the real API shape.
3. For some of the more logic-heavy or security-critical modules, **behavior tests** beyond pure compilation — fake/mock implementations of the external dependency functions, driving the module's real code through specific scenarios and asserting on the outcome (e.g., confirming a malformed input is rejected, confirming a specific GPIO/UART number is passed through correctly).
4. `firmware/test/` contains Unity test suites for most (not all) of the F1–F3 pure-logic modules, runnable via the `[env:native]` PlatformIO environment.

**What this does NOT cover, and should be treated as unverified:**
- Whether the whole integrated firmware actually compiles and links as one program (`main.cpp` alone pulls in nearly every module at once; no one has attempted to stub that entire dependency graph — it was judged not worth building a stub set that large when a real `pio run` will be done anyway).
- Any real-hardware behavior at all — timing, electrical characteristics, actual I2C/SPI/UART bus behavior, actual RF/cellular behavior.
- Some of the F4-era behavior tests (see the "Documentation debt" section of the gap list below) were run in a temporary scratch environment and their results are **not preserved as committed, reproducible test files** in `firmware/test/` — meaning their "N checks passing" claims in the docs cannot currently be re-run or independently confirmed by inspecting the repo alone.

## 6. What you're being asked to do

A prior review pass (by another AI reviewer, working directly against this same repository) already went through F1–F4 module by module and produced the finding list in Section 7 below. **Your job is to independently verify each of these findings against the actual current repository**, and additionally look for anything the prior pass may have missed. Concretely:

1. For each finding below, open the actual file(s) referenced and confirm (or refute) the claim. State clearly whether you agree it's a real issue, and if you disagree, explain exactly why with reference to the actual code.
2. Assess severity/impact in your own words — don't just repeat the label given below.
3. Actively look for anything NOT on this list: this list should not be treated as exhaustive. Pay particular attention to: thread-safety between the Modbus FreeRTOS task and the main loop, any other place besides the ones listed where untrusted network input (MQTT payloads, OTA trigger fields, HTTP responses) flows into a fixed-size buffer or a security decision, and any other place besides `readString()`/I2C-init where a failure return value is silently discarded.
4. Report back in detail, findings-first. **Do not edit, patch, or "helpfully fix" anything** — this is an analysis pass only; the person you're reporting to will decide what to do with your findings and asked specifically that you not make changes.

---

## 7. Findings from the prior review pass (to independently verify)

### Critical

**C1. I2C bus is never initialized — `Wire.begin()` does not appear anywhere in the firmware tree.**
`main.cpp` calls `g_leds.begin()`, `g_ai.begin()`, `g_ao.begin()` (the PCA9535-backed status LEDs, the ADS1115 ADC, and the MCP4725 DAC — all three ride the shared I2C bus on GPIO8/GPIO9). None of those three drivers' `.cpp` files, and nothing in `main.cpp`, ever calls `Wire.begin(PIN_I2C_SDA, PIN_I2C_SCL)` to actually attach the `TwoWire` driver to those pins and bring the I2C peripheral up. On ESP32 Arduino, `Wire.beginTransmission()` does not implicitly initialize the bus. As written, every I2C transaction on real hardware should fail: all 6 status LEDs, both analog channels, non-functional at boot. Compounding this: `main.cpp` never checks the return values of `g_leds.begin()`/`g_ai.begin()`/`g_ao.begin()` (unlike `g_modbus.begin()`, which is checked and logged), so this failure would be completely silent on a real device — no error, no log line, just non-functional LEDs and analog I/O.

### High

**H1. `url_host`'s hostname extraction can diverge from the host actually connected to (allowlist-bypass risk).**
`extractHttpsUrlHost()` scans left-to-right from just after `"https://"` and stops at the first of `/`, `:`, `?`, or end-of-string — it never special-cases `@` (URL userinfo delimiter). `HTTPClient`'s real URL parsing (used by `ota_session` to actually open the download connection) follows RFC 3986 order: split off the authority up to the first `/`, then split THAT on `@` (keeping only what's after the last `@` as host:port), then split on `:` for the port. For a URL like `https://trusted-host.example:@evil.com/malicious.bin`, `extractHttpsUrlHost()` returns `"trusted-host.example"` (stops at the `:` before ever considering `@`) — which would pass the allowlist check if that host is allowlisted — while `HTTPClient` actually connects to `evil.com`. This means the OTA download host allowlist (the layer specifically built to stop an attacker who can publish to the MQTT command topic from pointing the device at an arbitrary download server) can potentially be bypassed via a crafted trigger URL. Whether this is fully exploitable end-to-end also depends on the configured OTA CA certificate's trust scope.

**H2. `device_config.cpp`'s `readString()` silently reports success with an emptied value when a stored field doesn't fit the caller's buffer.**
It calls `Preferences::getString(key, out, out_size)` but discards the return value, then returns `true` (its "success" signal) based only on whether the key exists in NVS — not on whether the read actually fit. Arduino's real `Preferences::getString()` does not truncate on overflow; it returns 0 and leaves the destination buffer untouched, which here has already been pre-cleared to `""`. Net effect: if a stored value (WiFi password, WireGuard private/public/preshared key, LTE APN, etc.) is longer than the fixed-size stack buffer a caller reads it into, the caller gets back `true` with an empty string, with no way to distinguish "genuinely stored empty" from "silently truncated to nothing." Nothing on the write path (neither `device_config`'s setters, nor the commissioning-portal web form) enforces any length limit matching the various fixed-size read-side buffers scattered through `main.cpp`, so an over-length value is trivially reachable through normal commissioning.

**H3. `OtaUpdate::end()` calls `Update.end(true)`, which skips the underlying library's own completeness check.**
Arduino's real `UpdateClass::end(bool evenIfRemaining)`: when `evenIfRemaining` is true, it skips the "was the declared size actually fully written" rejection and instead silently redefines the expected size to whatever was actually written so far, then proceeds to verify and commit that as if it were the whole image. This contradicts `ota_update.h`'s own documented contract ("Returns false if the image was incomplete... nothing gets scheduled to boot differently in that case"). Currently masked in practice because the one real caller (`ota_session`) independently tracks total bytes read and aborts (without calling `end()`) on a mismatch — but this is a latent defect in the reusable `OtaUpdate` class itself: any future or alternate caller relying on the class's own documented behavior, rather than re-implementing the same completeness check itself, would silently accept a truncated image.

**H4. `modbus_pdu_parse_write_response()` doesn't validate response length, only the function code.**
Real Modbus write-acknowledgment responses (write single coil / write single register / write multiple registers) are always 5 bytes (function code + 2-byte address + 2-byte value-or-quantity). This function only requires `pdu_len >= 2`. A truncated or corrupted 2–3 byte response whose first byte happens to match the expected function code is accepted as a successful write confirmation, with nothing about the echoed address/value actually checked. This code path has zero test coverage.

### Medium

**M1. W5500 Ethernet has no hardware reset GPIO wired, apparently contradicting the subsystem's own documented design intent.**
`ethernet_link.cpp` passes `-1` (unused) for the W5500's reset pin. A subsystem design doc states, as an explicit, deliberate, dated design decision, that the reset line was wired to a dedicated MCU GPIO specifically so firmware could recover a hung W5500 without a full power cycle. But `docs/architecture.md`'s actual pin-assignment table only lists 5 Ethernet signals (CS/MOSI/SCLK/MISO/INT) with no reset pin, and `pin_map.h` has no corresponding `#define`. There's also a total/count inconsistency: `architecture.md`'s own changelog claims "28 cross-subsystem signals" assigned, but the actual table sums to 27. This is either a hardware pin-planning gap that needs a real GPIO assigned, or a stale design-intent doc that needs to be walked back — worth resolving one way or the other before board fabrication.

**M2. `pca9535`'s internal output-state shadow isn't synced from the chip's real power-on-reset state before the first `writePin()` call.**
The driver's `output_shadow_` defaults to `0x0000`, but the PCA9535's real power-on-reset Output Port register value is `0xFF`/`0xFF` (all bits high). `begin()` only does an I2C address ACK probe — it never reads the chip's actual current output register state. `writePin()` does a read-modify-write against `output_shadow_`, so calling it before any `writeOutputs()` call would silently drive all other output-configured pins low, clobbering whatever the chip's actual state was. Currently only avoided by accident — the one real call site (`status_leds`) happens to call `writeOutputs(0xFFFF)` before ever calling `writePin()` — not something the driver itself guarantees, and the driver's own header explicitly advertises itself as a generic, reusable component.

**M3. No anti-rollback/downgrade protection on OTA updates.**
The OTA trigger payload's `version` field is explicitly documented and implemented as informational-only, never used in any security or control-flow decision. A validly-signed OLD firmware image (a legitimate hash+signature pair from a previous release, including one with a since-fixed vulnerability) can be replayed indefinitely — the hash/signature checks only prove "an image that was once signed," not "the newest image that was signed." Worth at minimum recording as an accepted risk, or adding a monotonic minimum-version check.

**M4. `modbus_master` has some shared state outside its mutex protection, and no defensive null-check on the mutex in the read path.**
The mutex is correctly applied to the shared readings cache on both the write path (inside the polling task) and the read path (`getReading()`). However, `targets_[]`, `target_count_`, and `last_polled_millis_[]` are read by the polling task with no locking at all, while being written by `addTarget()` (presumably called from the main/setup context) — if a target is ever added after the task has started (not the documented intended usage today, but nothing prevents it), this is an unprotected data race. Separately, `getReading()` calls `xSemaphoreTake()` on the mutex handle with no null-check; if it's ever called before `begin()` has run, the mutex handle is still null, which is undefined behavior on real FreeRTOS.

**M5. Boot-time OTA rollback confirmation happens unconditionally and very early, undercutting its practical value.**
`confirmValid()` (cancelling the bootloader's pending-rollback state) is called unconditionally near the very start of `setup()`, based only on "the firmware got this far without crashing." The underlying rollback *primitive* is correctly implemented — but this means the safety net only protects against a crash/hang before `setup()` even runs, not against a new firmware image that boots cleanly but then fails to actually connect to WiFi/MQTT, or has some other functional regression — arguably the more common real-world class of bad OTA update.

**M6. `mqtt_client_wrapper`'s offline outbox can deliver messages out of chronological order under a specific failure pattern.**
The outbox always places a newly-queued message into the first free slot, and flushes slots in order, stopping at the first failure to preserve order. If an interior (non-tail) queued message repeatedly fails to publish (e.g., a payload that's permanently too large) while slots ahead of it have already drained and been freed, subsequently-queued newer messages backfill those freed earlier slots and get sent before the still-stuck older message on the next flush — breaking the documented FIFO/ordering guarantee.

**M7. `Serial.begin()` / UART0-vs-USB-CDC console routing is unconfirmed, with a potential pin conflict.**
`pin_map.h` puts RELAY3/RELAY4 on GPIO43/44 (the module's default UART0 TX/RX), justified by the comment "UART0 unused" (i.e., the intent is that the Arduino `Serial` console goes over the ESP32-S3's native USB-CDC instead of physical UART0). But `platformio.ini` sets no explicit `ARDUINO_USB_CDC_ON_BOOT`/`ARDUINO_USB_MODE` build flag, so which one `Serial` actually resolves to depends on the board manifest's own default — unconfirmed. If it resolves to physical UART0, it would conflict with RELAY3/4.

### Low

**L1. `power_safety` defaults to "no extra startup delay" specifically when NVS fails to open**, which is arguably the wrong direction for a module whose purpose is protecting against marginal/brownout power conditions — a failing NVS open is itself a plausible symptom of exactly that condition.

**L2. `event_log` writes tag/message fields unescaped into a comma-separated log line.** A value containing a comma or embedded newline would inject extra fields or fabricate what looks like a separate log entry. Not currently reachable (all current call sites pass fixed string literals), but a latent risk if any future call site logs attacker-influenced content verbatim.

**L3. `mqtt_client_wrapper`'s `publish()`/`enqueue()` don't null-check `topic`/`payload`** (unlike `subscribe()`, which does check). No current call site passes null, so this is a defensive-coding gap rather than a live bug today.

**L4. `ota_trigger`'s numeric-field parser has an unstated dependency on `unsigned long` being 32 bits.** Safe on the real ESP32-S3 target (where `unsigned long` is 32-bit, so out-of-range values saturate and get caught by the subsequent bounds check), but on a 64-bit host build of the same parser, a sufficiently large crafted value could avoid saturation and then get silently truncated by the later narrowing cast to `uint32_t`, potentially slipping past the intended size bound. The existing test for "oversized size field" doesn't test anywhere near the actual 32-bit boundary.

**L5. `ota_session`'s download loop doesn't independently cap a single read to the remaining declared image size** (it's bounded by a fixed local buffer, just not by "how many bytes are left to reach the declared total"). Not currently exploitable — the underlying `Update` write function and a final total-bytes check both catch the mismatch — but a compliant server sending exactly the declared size immediately followed by more data (coalesced into one TCP read) would trigger an avoidable abort rather than a clean stop.

**L6. `image_verify`'s SHA-256 streaming calls (`mbedtls_sha256_starts`/`mbedtls_sha256_update`) don't check their return codes.** These can theoretically report a hardware-acceleration failure. In practice this just produces a wrong hash, which is then caught by the (checked) hash-comparison step afterward — fails safe, not a security issue, just a robustness gap.

**L7. Minor buffer-size mismatch between `ota_trigger`'s maximum accepted signature length and `ota_session`'s actual decode buffer size** — a syntactically-valid-per-the-parser signature near the parser's own upper bound would be rejected later by the decode step instead of by the parser itself. Not reachable by a real ECDSA-P256 signature (which is far shorter than either limit), just an inconsistency between the two modules' stated bounds.

**L8. `StatusLed::HEARTBEAT` is defined in the status-LED enum but never actually driven anywhere in `main.cpp`.**

**L9. `McpAnalogOutput` (the DAC driver) is initialized in `setup()` but has no consumer anywhere** — nothing in `loop()`, and no rule-engine action type targets it. Currently dead code (not itself harmful, since the DAC's own power-on state is a safe 0V, but worth knowing).

### Test coverage gaps

**T1.** `modbus_pdu`: several of the read-request builder functions, and both response-parsing functions (bit-response and write-response), have zero test coverage.
**T2.** `modbus_rtu`/`modbus_tcp`/`io_state`: a handful of edge cases (too-short frame, buffer-too-small, out-of-range channel index, null-pointer args) are implemented correctly but have no test exercising them.
**T3.** `ota_update.cpp`'s actual logic (rollback state query/confirm/reject, `begin`/`write`/`end`) has zero test coverage — only a pure, hardware-independent progress-percentage helper function is tested.
**T4.** `power_safety::begin()`, including its NVS-failure fallback path (see L1), has zero test coverage.
**T5.** `url_host` has no test covering the `@`-userinfo URL shape that exposes H1.
**T6.** No test exercises `ota_trigger`'s numeric-field parser anywhere near the actual 32-bit boundary described in L4.

### Documentation debt (docs vs. actual repo state — not code bugs)

**D1.** `docs/roadmap.md` and `CLAUDE.md` both still describe the `platformio.ini` flash-size/PSRAM board override as "still open" / not yet done. It's already present in the file (`board_build.flash_size = 16MB`, `board_build.arduino.memory_type = qio_opi`) — the docs were never updated after the fix landed.
**D2.** Both docs have sections (from an earlier project phase) still describing an older, since-superseded version of `lte_modem` that included AT-command/UART logic and a separate `lte_at_parse` parsing module with its own tests — that code was later deleted and `lte_modem` trimmed to power/reset-only, which a *later* section of the same two docs correctly describes. The two sections of each doc now contradict each other.
**D3.** Several "N checks, all passing" test-count claims in the docs don't match the actual number of test cases in the corresponding `firmware/test/` file (specific modules affected: `ota_trigger`, `url_host`, `net_allowlist`, `rule_engine` — each off by a few from what's actually in the file).
**D4.** Three specific verification claims in the docs (for `image_verify`, for the LTE/PPP module pairing, and for the network-priority fallback logic in `main.cpp`) describe passing behavior tests with a specific check count, but there is no corresponding test file anywhere in the repository for any of the three — meaning those verification passes, even if they genuinely happened, are not currently reproducible from the repo alone.
**D5.** `docs/roadmap.md` still lists a digital-input strapping-pin question (GPIO3/GPIO46 usage) as an open decision in one section, while `CLAUDE.md` records it as already resolved (reviewed and accepted) in another — the two docs disagree with each other on the current status of the same decision.

---

*End of review request. Reminder: report findings only — do not modify any file in this repository.*

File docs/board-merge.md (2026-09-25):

# Board merge — `ioboard+lteboard`

## Status

Merge itself DONE (2026-09-19). `hardware/kicad/ioboard+lteboard/` is the single active
KiCad project for all schematic work. `ioboard/` and `lteboard/` are frozen as of that
date — not edited further, kept only as the historical record of each board's schematic
capture up to the point of merge. The board-to-board wiring and fine-grained pin
assignment this merge was done *for* (roadmap steps 6 and 7) are also now DONE, as of
2026-09-22/23 — see "Verified" below, updated to match; this doc's original
"Not yet connected" section is now historical, kept for the reasoning trail.

## Why

Steps 6 (fine-grained pin/resource planning) and 7 (board-to-board wiring) both require
working across both boards at once — assigning MCU pins that serve subsystems living on
the other physical board, and wiring the rails/signals that cross the board-to-board
connector. Doing that from two separate, closed KiCad projects meant reasoning about
cross-board connectivity from memory/documentation rather than seeing it directly. One
merged schematic project makes the cross-board picture direct and checkable.

## What was done

All 10 real subsystem sheets were imported as hierarchical sheet symbols into a new root
sheet, `ioboard+lteboard.kicad_sch` (WiFi has no sheet of its own — it lives inside
`core-compute.kicad_sch`, unchanged by the merge):

- IOBOARD side: `power`, `analog_io`, `digital_inputs`, `relay_outputs`, `rs232`, `rs485`
- LTEBOARD side: `core-compute`, `ethernet`, `lte`, `status_indication`

Each subsystem's sheet-symbol pins were wired directly on the root canvas wherever the
corresponding original board's own root sheet already tied them together (see "Verified"
below). Two graphic borders + text labels ("IOBOARD" / "LTEBOARD") mark which sheet
symbols belong to which physical board — visual grouping only, no electrical meaning.

KiCad physically copied each subsystem `.kicad_sch` file into the new project folder
rather than referencing the originals in place. Content was verified identical to the
originals at merge time — component count, wire count, hierarchical/global label count,
junction count, and no-connect count all match exactly between each original file and its
copy. The only difference is reference designators, which KiCad auto-renumbered on import
to avoid collisions across the new shared hierarchy; this doesn't matter since a final
Annotate Schematic pass resets numbering anyway once wiring/placement is finished (see
"Reference designators" below). From 2026-09-19 onward, only the copies under
`ioboard+lteboard/` get edited — the ones under `ioboard/` and `lteboard/` will not
receive further changes and should not be treated as current.

## Verified (full netlist reconstruction, 2026-09-19)

Connected, confirmed correct:

- `power` ↔ `relay_outputs`: `5V_RELAY`
- `power` ↔ `analog_io`: `3V3_ANALOG_ISO`, `GND_ANALOG_ISO`, `15V_ANALOG_ISO`
- `core-compute` ↔ `status_indication`: `I2C_SCL`, `I2C_SDA`
- IOBOARD-side `3V3_LOGIC` common across `analog_io`/`digital_inputs`/`power`/`rs232`/
  `rs485`
- LTEBOARD-side `3V3_LOGIC` common across `core-compute`/`ethernet`/`lte`/
  `status_indication`
- `GND_LOGIC` and `EARTH` are Global Labels in the original files — these merge
  project-wide automatically regardless of sheet hierarchy, so no sheet-pin wiring was
  needed for them; confirmed present in every file that should have them

Not yet connected as of 2026-09-19 — expected at the time, waiting on later roadmap
steps, not new defects found by this merge. **Update 2026-09-23: both steps below are now
done, this section is historical.**

- IOBOARD-side `3V3_LOGIC` and LTEBOARD-side `3V3_LOGIC` were two separate islands —
  ~~needs the physical board-to-board connector (step 7, not started)~~ **DONE.** Tied via
  the `J_PWR_IO`/`J_PWR_LTE` connector pair, full pinout in `docs/architecture.md`'s
  "Board-to-board header" section.
- `VBAT_LTE`: was isolated on both `power`'s output pin and `lte`'s input pin —
  ~~same reason, step 7~~ **DONE**, same connector pair as above.
- `LTE_PWRKEY`/`LTE_RESET`/`LTE_RXD`/`LTE_TXD`, `RS485_TXD`/`RS485_RXD`,
  `RS232_TXD`/`RS232_RXD`, and all 6 `ETH_*` SPI pins — ~~isolated because
  `core-compute.kicad_sch` doesn't expose matching GPIO/UART/SPI pins yet (step 6, not
  started)~~ **DONE.** All 28 cross-subsystem signals now have real GPIOs on
  `core-compute.kicad_sch` — full table in `docs/architecture.md`'s "Core-compute pin
  assignment." (LTE/Ethernet's signals turned out not to need the board-to-board
  connector at all — `lte`, `ethernet`, and `core-compute` are all LTEBOARD-side, so
  those wire directly; only RS485/RS232/digital-inputs/relay-outputs/I2C actually cross
  `J_SIG`.)

Project-wide ERC confirmed clean 2026-09-23 (see `CLAUDE.md`'s open items for the
error-by-error history of what that took).

## Known open question for later — PCB layout (steps 8-9)

`ioboard+lteboard` being the sole active schematic project means both physical boards'
component data lives in one project's netlist. KiCad's "Update PCB from Schematic"
imports a project's entire hierarchy with no per-sheet filter, so producing two clean
physical-board PCB files from this one project will need a deliberate approach at that
stage — most likely two `.kicad_pcb` files that each import the full netlist and then
have the other board's footprints removed, repeated after every schematic sync. Not a
blocker now; flagged here so it isn't a surprise at step 8.

An alternative was considered and rejected: keep `ioboard`/`lteboard` as thin per-board
projects whose sheet symbols point at the same underlying subsystem files used by
`ioboard+lteboard` (rather than separate copies), so each board's PCB import would stay
clean automatically with no manual footprint filtering. Ozcan's explicit call
(2026-09-19) was to freeze `ioboard`/`lteboard` as they are and work only from the merged
project going forward — this doc exists so that decision and its known PCB-layout
consequence are both on record, not just the decision.

## Reference designators

Not yet reconciled — expected. Each subsystem was originally annotated independently
(`R1`, `U1`, etc. in each), so the merged hierarchy currently has many duplicate/
placeholder references. Resolved by running Tools → Annotate Schematic across the whole
merged sheet once wiring/placement is finalized — deliberately not run before that, to
avoid re-running it repeatedly mid-work.

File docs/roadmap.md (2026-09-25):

# Build roadmap

10-step plan, in order. Status updated as we go.

## 1. Repo + tooling setup — DONE

GitHub repo created and pushed (`IoT_gateway`). VS Code + PlatformIO + pioarduino + KiCad +
Wokwi extension installed. PlatformIO build confirmed working end to end.

## 2. Fixed chip-level constraints check — DONE

Locked in before any design work — these can't change later without a different MCU module:

- Module: ESP32-S3-WROOM-1U-N16R8 — 16MB Quad SPI flash, 8MB octal-mode PSRAM.
- GPIO26-32 permanently reserved (flash). GPIO33-37 permanently reserved (octal PSRAM).
- GPIO0/45/46/3 are strapping pins. GPIO39/42/47/21 have nonstandard reset behavior.
- Exactly 3 hardware UART controllers available.
- No built-in DAC peripheral — analog output needs PWM+filter or an external DAC chip,
  decided at step 6.

Full detail in `architecture.md` under "Fixed MCU constraints."

## 3. One-page block diagram — DONE

Mermaid diagram + bus assignment table + board-to-board header signal count, in
`architecture.md`.

## 4. Isolated subsystem prototyping — DONE

Simulation only (KiCad/ngspice for power and analog circuits). Wokwi isn't used going
forward — most real subsystems here (LTE, Ethernet, RS485, RS232) can't be simulated in it;
that firmware is written against datasheets and validated at Rev-A instead.

Each subsystem gets its own build plan under `docs/subsystems/` before work starts on it.
Order:

1. Power — `docs/subsystems/power.md` — **DONE**
2. Core compute (ESP32-S3 bring-up) — `docs/subsystems/core-compute.md` — **DONE**
3. Digital inputs (8x, opto-isolated) — `docs/subsystems/digital-inputs.md` — **DONE**
4. Relay outputs (4x) — `docs/subsystems/relay-outputs.md` — **DONE**
5. Status indication (I2C GPIO expander + LEDs) — `docs/subsystems/status-indication.md` —
   **DONE**
6. Analog I/O (input + output) — `docs/subsystems/analog-io.md` — **DONE**
7. RS485 (isolated) — `docs/subsystems/rs485.md` — **DONE**
8. RS232 — `docs/subsystems/rs232.md` — **DONE**
9. Ethernet (W5500) — `docs/subsystems/ethernet.md` — **DONE** through schematic capture
   (2026-09-13); ERC and BOM still pending, same as every other subsystem's open items
10. WiFi — `docs/subsystems/wifi.md` — **DONE** 2026-09-13. Small scope: the
    ESP32-S3-WROOM-1U's radio is already fixed (core-compute); this was just the external
    antenna path (J2 SMA jack -> EARTH, coax pigtail, gain-limited antenna) added to
    `core-compute.kicad_sch`. ERC and BOM's off-board items pending, same as everywhere.
11. LTE (Quectel EG915U-EU) — `docs/subsystems/lte.md` — **DONE** through schematic capture
    and BOM (2026-09-19). Most complex subsystem: own rail, own UART (via a level shifter),
    SIM interface, power-control circuit, own antenna path. Two findings from drafting it
    were resolved early: the rail (renamed `VBAT_LTE`) was retapped from ~3.3V to ~3.82V for
    real margin against Quectel's 3.3-4.3V spec (see `power.md`'s revision history), and
    `architecture.md`'s header line now lists `VBAT_LTE` separately from `3V3_LOGIC` — see
    `lte.md` decisions 2 and 8. The sheet symbol + 6 hierarchical pins were added to the
    `lteboard.kicad_sch` master sheet 2026-09-19 and checked pin-by-pin against
    `lte.kicad_sch`'s own labels (full netlist reconstruction, not hand-traced coordinates)
    — exact match, no defect. Two real ERC-style gaps found in that same pass (D1's 4th ESD
    channel unwired, two U4 no-connect flags missing) have since been fixed and re-verified.
    ERC and BOM's off-board items pending, same as every other subsystem's open items. The
    master sheet's 6 new pins aren't wired to anything yet: `3V3_LOGIC`/`VBAT_LTE` need the
    board-to-board connector (step 7, not started — every subsystem's cross-board rails are
    in the same state, not LTE-specific), and `LTE_PWRKEY`/`LTE_RESET`/`LTE_TXD`/`LTE_RXD`
    need real MCU GPIO/UART pins that don't exist yet on `core-compute.kicad_sch` (step 6,
    not started).

ERC is deferred to a single end-of-project pass across all subsystems, not a per-subsystem
pre-merge gate (Ozcan's explicit decision, confirmed 2026-09-10 — status-indication had
already opted into the same project-wide-pass approach independently); tracked per-subsystem
in `CLAUDE.md`'s open items, not blocking this roadmap's forward progress.

All 11 subsystems above are now schematic-complete, which closes this step. Immediately
after, both boards were brought into a single schematic project (`ioboard+lteboard`) to
make cross-board wiring for steps 6 and 7 directly checkable instead of reasoned about
from two closed projects — full detail in `docs/board-merge.md`. That project is now the
sole active one; `ioboard/` and `lteboard/` are frozen as of 2026-09-19.

## 5. Per-subsystem acceptance criteria — DONE FOR POWER, PER-SUBSYSTEM GOING FORWARD

Each subsystem's own plan now defines its pass/fail acceptance criteria as part of that
subsystem's build (see `docs/subsystems/power.md`, step 11).

## 6. Fine-grained resource planning — SUBSTANTIALLY DONE, 2 ITEMS OPEN

Exact pin/bus assignment across the full design, done in `ioboard+lteboard` (see step 4
and `docs/board-merge.md`), since the pins being assigned on `core-compute.kicad_sch`
serve subsystems on both physical boards. All 28 cross-subsystem signals (LTE x4, RS485
x2, RS232 x2, Ethernet x6, I2C x2, digital inputs x8, relay outputs x4) now have real
GPIOs assigned and wired on `core-compute.kicad_sch` — full table in
`docs/architecture.md`. The analog-output DAC-vs-PWM question is also decided: an
MCP4725 I2C DAC (see `docs/subsystems/analog-io.md`), riding the existing shared I2C bus
— no separate PWM/GPIO line needed, `architecture.md` updated to match.

Two items still open before this step is fully closed:

1. `firmware/platformio.ini` still declares `board = esp32-s3-devkitc-1` with no
   flash/PSRAM override — a generic N8 profile, not the real N16R8 module (16MB flash /
   8MB octal PSRAM). Needs a `board_build.flash_size`/`board_build.psram_type` override
   (or an N16R8-specific board definition).
2. Five of the eight digital-input pin assignments landed on pins this project's own
   `architecture.md` flags under "Fixed MCU constraints" as sensitive: `DI4_MCU` →
   GPIO3 and `DI7_MCU` → GPIO46 (both strapping pins), `DI5_MCU`/`DI6_MCU`/`DI8_MCU` →
   GPIO39/42/47 (nonstandard reset behavior). This wasn't re-checked against that
   constraints list when the assignment was made — worth a deliberate accept-or-reroute
   decision before calling pin planning final, not a silent pass.

## 7. Incremental consolidation — DONE

Firmware: git branches per subsystem, merged incrementally. Hardware: KiCad hierarchical
sub-schematics per subsystem — done per-board already, and both boards' hierarchies were
brought into one schematic project 2026-09-19 (`docs/board-merge.md`).

Board-to-board connector decision made 2026-09-22 — see `docs/architecture.md`'s
"Board-to-board header" section for the full two-connector pinout (J_PWR 2x5, J_SIG
2x12, Samtec TSW/SSW 2.54mm). Reference-design photos were reviewed first to check for a
precedent part; the reference doesn't stack its two boards the same way (likely
cable/harness-linked), so its headers didn't dictate a specific part, only confirmed
2.54mm THT pin headers are a reasonable, unexotic choice.

Connector symbols placed and wired per that pinout (4 symbols: J_PWR_IO/J_PWR_LTE,
J_SIG_IO/J_SIG_LTE), no-connect flags added to spare pins, `rs485.kicad_sch`'s `EARTH`
label promoted to `global_label` for consistency with the other three sheets that use
it, and a defect on `PS1`/`U13` (RK-0515S / R1SX-3.33.3-R isolated DC-DC modules) caught
and fixed during the ERC pass — not a label swap: both SnapEDA-imported symbols had
their return-side output pin (`-VOUT`) generically typed as plain `Output` instead of
the electrically-correct `Power output`/`Passive` split, which reads as two driven
outputs shorted together ("pins of type output and output are connected"). Fixed by
retyping each symbol's `+VOUT` to `Power output` (the genuinely driven pin) and `-VOUT`
to `Passive` (the return/reference side, not a second driven output).

ERC confirmed clean 2026-09-23 (Ozcan, full project pass). This closes step 7.

## 8. Rev-A prototype PCB spin — NOT STARTED

First point real physical hardware is needed. Since schematic capture now lives in one
merged project (`ioboard+lteboard`) instead of two, producing the two separate physical
boards' PCB files needs a deliberate approach at this step — see the open question at the
end of `docs/board-merge.md`.

## 9. Integration schematic + PCB layout — NOT STARTED

Schematic integration is effectively already done ahead of this step — see step 4 and
`docs/board-merge.md`. What remains here is the PCB layout half, and settling the
two-PCBs-from-one-project question noted at step 8.

## 10. Fabrication, bring-up, enclosure, iterate — NOT STARTED

## Firmware roadmap

Tracked separately from the 10 hardware steps above since much of it can be written and
unit-tested before Rev-A hardware exists. Scope modeled on a comparable commercial 4G IoT
gateway in this device class (MCU-based, not a Linux-SBC gateway).

### F1. Protocol/logic layer — DONE, 2026-09-23

Hardware-independent, real unit tests (host-native compile via `gcc`/`g++` directly, not
`pio test` - see `CLAUDE.md`'s Firmware F1 section for why). All 6 modules in
`firmware/lib/`: modbus_crc, modbus_pdu, modbus_rtu, modbus_tcp, mqtt_payload, io_state.

- Modbus RTU CRC16 — **DONE**, tested against independently-computed reference vectors.
- Modbus RTU frame builder/parser — **DONE**. Role: master (this gateway polls
  downstream field devices, it does not expose itself as a slave).
- Modbus TCP — **DONE** (needed alongside RTU; this gateway has Ethernet).
- MQTT payload construction — **DONE**.
- DI/AI/relay ↔ register mapping table — **DONE** (`io_state`).

### F2. Drivers — DONE, 2026-09-23

Write + compile-verify only — no physical hardware exists yet, so nothing here can be
functionally tested before Rev-A. All 10 compile-checked with `g++` (8 against a
hand-written Arduino/Wire/HardwareSerial stub; `ethernet_link`/`wifi_link` reasoned
against the real ESP32 core headers instead - see `CLAUDE.md`'s Firmware F2 section for
why those two weren't stubbed).

DI, relay outputs, analog input, analog output (DAC), I2C GPIO expander + status LEDs,
RS485 UART, RS232 UART, Ethernet (W5500), WiFi, LTE (Quectel AT commands).
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

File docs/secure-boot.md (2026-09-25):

# Secure boot / flash encryption

Guidance only - **nothing in this project's firmware enables either of these**, and
this doc isn't a plan to do so soon. Written up now (2026-09-23) because it's an F3
checklist item and the underlying facts (irreversible eFuse burns) matter enough that
"we'll figure it out later" isn't good enough once someone actually reaches for the
`idf.py` command that turns them on. Confirmed directly against Espressif's own
ESP32-S3 security docs (Secure Boot V2, Flash Encryption) - not from general ESP32
knowledge, since the exact mechanism differs across chip generations and getting it
wrong here isn't recoverable.

## What these two features actually are

They're related but separate, and get enabled independently:

- **Secure Boot V2** - the bootloader and app image are signed (RSA-3072 with PSS
  padding, SHA-256) and the ROM bootloader + second-stage bootloader refuse to run
  anything not signed by a key matching the digest burned into eFuse. Stops someone
  from replacing this device's firmware with their own.
- **Flash encryption** - the flash contents themselves are encrypted at rest (AES-XTS,
  256 or 512-bit key), with the key generated on-device by the hardware RNG and burned
  into an eFuse block that's read/write-protected from software. Stops someone from
  reading firmware/secrets off the flash chip directly (relevant here: `device_config`
  stores WiFi credentials and, if TLS is used, certificate/private-key PEM material in
  plain NVS - see that module's own header for the same caveat stated where it
  actually matters day to day).

Either can be enabled without the other, but for what this project would actually want
(stop both firmware tampering and secret extraction), both matter.

## Why irreversibility is the whole story here

Both features work by burning eFuses - one-time, physically permanent bits on the
chip. Specifically:

- Secure Boot: `SECURE_BOOT_EN`, the key-digest eFuses (`KEY_PURPOSE_X`/`BLOCK_KEYX`),
  and optionally `KEY_REVOKEX` to permanently disable unused key slots. Once burned,
  every future bootloader/app image needs a valid signature from a key matching what's
  in eFuse - no exceptions, no override.
- Flash encryption: there are two modes.
  - **Development Mode** - the device will transparently encrypt plaintext firmware
    you flash over UART, and (only in this mode) the `SPI_BOOT_CRYPT_CNT` eFuse bits
    stay unprotected, so encryption can in principle still be turned back off by
    burning that same eFuse counter to a disabling value. Meant for iterating during
    bring-up, not a real "reversible" mode.
  - **Release Mode** - burns `DIS_DOWNLOAD_MANUAL_ENCRYPT` and write-protects
    `SPI_BOOT_CRYPT_CNT`. From that point on, **plaintext UART reflashing is
    permanently impossible** - the only way to update firmware is a signed/encrypted
    OTA update. If OTA is ever broken, misconfigured, or the signing key is lost, the
    device cannot be recovered over USB/UART at all. This is the actual sharp edge:
    not "flash encryption" in the abstract, but "Release Mode with no working OTA
    path" - that combination can genuinely brick a device for good.
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

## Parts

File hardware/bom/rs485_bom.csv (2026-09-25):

Ref | Part | Role | MPN | Manufacturer | Distributor link
U15 | Mornsun TD321S485H-A | Isolated RS485 transceiver module | TD321S485H-A | Mornsun | https://www.mornsun-power.com/public/uploads/pdf/TD5(3)21S485H-A.pdf
GD1 | Bencent B3D090L-C | Gas discharge tube — line surge diversion to EARTH | B3D090L-C | Bencent | https://www.lcsc.com/product-detail/Gas-Discharge-Tube-GDT_Bencent-B3D090L-C_C511253.html
U14 | TDK ACM2520-301-2P | Common-mode choke | ACM2520-301-2P-T002 | TDK | https://www.lcsc.com/product-detail/Common-Mode-Filters_TDK-ACM2520-301-2P-T002_C76577.html
D15 | Littelfuse SMBJ6.5CA | Bidirectional TVS diode — A-B differential clamp | SMBJ6.5CA | Littelfuse | https://www.digikey.com/en/products/detail/littelfuse-inc/SMBJ6-5CA/285958
D18 | Littelfuse SMBJ6.5CA | Bidirectional TVS diode — line-to-EARTH clamp | SMBJ6.5CA | Littelfuse | https://www.digikey.com/en/products/detail/littelfuse-inc/SMBJ6-5CA/285958
D19 | Littelfuse SMBJ6.5CA | Bidirectional TVS diode — line-to-EARTH clamp | SMBJ6.5CA | Littelfuse | https://www.digikey.com/en/products/detail/littelfuse-inc/SMBJ6-5CA/285958
R35 | Generic 2.7 ohm 2W | Series current-limiting resistor (line side) | 2.7 | generic
R34 | Generic 2.7 ohm 2W | Series current-limiting resistor (line side) | 2.7 | generic
R36 | Generic 1M | Bleed resistor — RC snubber to EARTH (with C23) | 1M | generic
C23 | Generic ceramic, 1nF, 2kV | RC snubber capacitor to EARTH (with R36) | 1nF | generic
R_pullup1 | Generic 4.7k | External bias pull-up — VO (pin 7) to A | 4.7k | generic
R_pulldown1 | Generic 4.7k | External bias pull-down — RGND (pin 10) to B | 4.7k | generic
J5 | Phoenix Contact MC 1,5/3-ST-3,5 | 3-position field connector (A/B/EARTH) | 1840379 | Phoenix Contact | https://www.newark.com/phoenix-contact/mc-1-5-3-st-3-5/pluggable-terminal-block-3-position/dp/14J3293

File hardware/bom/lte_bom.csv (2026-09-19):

Ref | Part | Role | MPN | Manufacturer | Distributor link
U4 | Quectel EG915UEUAC-N05-SNNSA | LTE Cat-1 modem (+2G fallback), EU band variant | EG915UEUAC-N05-SNNSA | Quectel | https://quectel.com/content/uploads/2024/02/Quectel_EG915U_Series_Hardware_Design_V1.1.pdf
U5 | TI TXB0102DCUR | 2-channel level shifter, 1.8V (MAIN_TXD/MAIN_RXD) <-> 3.3V (LTE_TXD/LTE_RXD) - checked and confirmed correctly wired 2026-09-19, see lte.md Step 4 | TXB0102DCUR | Texas Instruments | https://www.ti.com/lit/gpn/txb0102
J3 | SMA jack, board/panel mount (Conn_Coaxial symbol placed - real MPN not yet selected) | ANT_MAIN board connector; shield to EARTH, RF pin No Connect (fed by coax pigtail, not a PCB net) - same pattern as wifi.md's J2 | TBD | TBD
J4 | JAE SF53S006VCBR2000 | Micro-SIM push-push holder, 6-contact (C1/C2/C3/C5/C6/C7; C4/C8 not present); C6 (VPP) No-Connect | SF53S006VCBR2000 | JAE
D1 | STMicroelectronics ESDA6V1BC6 | SIM interface ESD protection, quad TVS array (SOT23-6L), 3 of 4 channels used (RST/CLK/DATA) | ESDA6V1BC6 | STMicroelectronics | https://www.mouser.com.tr/
D3 | Littelfuse/Bourns SMAJ5.0A (representative) | VBAT reverse-standoff TVS protection | SMAJ5.0A | Littelfuse / Bourns
D4 | Generic bidirectional TVS placed (D_TVS symbol) - real part not finalized | ANT_MAIN ESD protection at J3; spec is <=0.05pF / <=5V per Quectel's reference note - no real part found that meets both; closest candidate Littelfuse PGB1010603 (0.06pF, but 24V standoff - exceeds the 5V spec) | TBD | TBD | https://www.littelfuse.com/assetdocs/pulseguard-esd-suppressors-pgb1-datasheet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
Q4 | Generic small-signal NPN (Q_NPN symbol placed) | RESET_N driver transistor, pre-biased-transistor topology (base 4.7k + base-emitter 47k) | MMBT3904 or BC847 (suggested - not finalized) | generic
Q5 | Generic small-signal NPN (Q_NPN symbol placed) | PWRKEY driver transistor, same topology as Q4 | MMBT3904 or BC847 (suggested - not finalized) | generic
R22 | Generic E24 10k | Level shifter OE divider, high side: VDD_EXT to OE (with R31 forming the divider to GND_LOGIC) | generic | generic
R28 | Generic E24 15k | SIM DATA pull-up, to USIM1_VDD | generic | generic
R33 | Generic E24 4.7k | RESET_N (Q4) base series resistor | generic | generic
R34 | Generic E24 47k | RESET_N (Q4) base-emitter resistor | generic | generic
R35 | Generic E24 4.7k | PWRKEY (Q5) base series resistor | generic | generic
R36 | Generic E24 47k | PWRKEY (Q5) base-emitter resistor | generic | generic
R25 | Generic E24 0R | SIM RST line link, between J4 and D1's ESD/filter node - role confirmed 2026-09-19 | generic | generic
R29 | Generic E24 0R | SIM DATA line link, between J4 and D1's ESD/filter node - role confirmed 2026-09-19 | generic | generic
R30 | Generic E24 0R | SIM CLK line link, between J4 and D1's ESD/filter node - role confirmed 2026-09-19 | generic | generic
R31 | Generic E24 120k | Level shifter OE divider, low side: OE to GND_LOGIC (with R22 forming the divider from VDD_EXT) - role confirmed 2026-09-19 | generic | generic
R32 | Generic E24 0R | ANT_MAIN matching network series link (populated position, per Quectel reference design) | generic | generic
C0603 | Ceramic, NM (not mounted - reserved footprint only) | ANT_MAIN matching network shunt cap position, left unpopulated per Quectel's own reference design - reference designator non-standard, recommend re-annotating | generic | generic
CO604 | Ceramic, NM (not mounted - reserved footprint only) | ANT_MAIN matching network shunt cap position, left unpopulated per Quectel's own reference design - reference designator has a typo (letter O, not digit 0) and is non-standard, recommend re-annotating | generic | generic
C11 | Generic ceramic, 100nF | Role not independently confirmed this pass | generic | generic
C13 | Generic ceramic, 100nF | SIM VDD (USIM1_VDD) bypass cap, to GND_LOGIC | generic | generic
C16 | Generic ceramic, 33pF | SIM RST line filter cap | generic | generic
C17 | Generic ceramic, 33pF | SIM CLK line filter cap | generic | generic
C18 | Generic ceramic, 33pF | SIM DATA line filter cap | generic | generic
C19 | Generic ceramic X7R, 100nF | VBAT_BB decoupling array (with C_bulk3/C20/C21) | generic | generic
C20 | Generic ceramic C0G/NP0, 33pF | VBAT_BB decoupling array | generic | generic
C21 | Generic ceramic C0G/NP0, 10pF | VBAT_BB decoupling array | generic | generic
C22 | Generic ceramic X7R, 100nF | VBAT_RF decoupling array (with C_bulk4/C23/C24) | generic | generic
C23 | Generic ceramic C0G/NP0, 33pF | VBAT_RF decoupling array | generic | generic
C24 | Generic ceramic C0G/NP0, 10pF | VBAT_RF decoupling array | generic | generic
C26 | Generic ceramic, 10nF | PWRKEY (Q5 branch) debounce cap - Figure 10 shows this on PWRKEY only, not RESET_N (no C25 by design) | generic | generic
C_BYPASS1 | Generic ceramic, 2.2uF | U5's VCCA bypass cap, VDD_EXT to GND_LOGIC - per decision 4, confirmed correctly wired 2026-09-19 | generic | generic
C_bulk3 | Generic ceramic/polymer, 100uF low-ESR (<=0.7 Ohm) | VBAT_BB bulk decoupling cap | generic | generic
C_bulk4 | Generic ceramic/polymer, 100uF low-ESR (<=0.7 Ohm) | VBAT_RF bulk decoupling cap | generic | generic
(off-board) | Wideband SMA antenna, ~617MHz-3.8GHz, tilt/swivel | Screws onto J3 | ANT-LTE-MON-SMA-L | TE Connectivity / Linx

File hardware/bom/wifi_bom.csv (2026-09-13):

Ref | Part | Role | MPN | Manufacturer | Distributor link
J2 | SMA female jack, 2-hole flange, PCB/panel mount | Board-side antenna connector; shield to EARTH, center pin No Connect (fed by pigtail, not a PCB net) | 132163 | Amphenol RF | https://www.amphenolrf.com/en-us/part/132163/1014/
(off-board) | U.FL-to-SMA female bulkhead pigtail cable, RG178, ~10-15cm | Carries the RF signal from U1's onboard U.FL jack to J2 - not a schematic net; connectorized assembly, no MPN required | generic | generic
(off-board) | 2.4-2.5GHz antenna, SMA-male, <=2.33dBi gain (certification limit - see wifi.md decision 3) | External antenna, screws onto J2 | SMA 2.4G 2DB Antenna (2dBi) | Waveshare | https://www.waveshare.com/sma-2.4g-2db-antenna.htm

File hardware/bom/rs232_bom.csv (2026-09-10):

Ref | Part | Role | MPN | Manufacturer | Distributor link
U16 | TI MAX3232EIPWR | RS232 transceiver (TSSOP-16) — one channel used (DIN1/DOUT1/RIN1/ROUT1); channel 2 left unconnected | MAX3232EIPWR | Texas Instruments | https://www.ti.com/product/MAX3232E/part-details/MAX3232EIPWR
C24 | Generic ceramic, 0.1uF | Charge-pump flying capacitor (C1+ to C1-) | 0.1uF | generic
C25 | Generic ceramic, 0.1uF | Charge-pump reservoir capacitor (C2+ to C2-) | 0.1uF | generic
C26 | Generic ceramic, 0.1uF | VCC bypass capacitor (VCC to GND_LOGIC) | 0.1uF | generic
C27 | Generic ceramic, 0.1uF | Charge-pump reservoir capacitor (V- to GND_LOGIC) | 0.1uF | generic
C29 | Generic ceramic, 0.1uF | Charge-pump reservoir capacitor (V+ to GND_LOGIC) | 0.1uF | generic
J6 | Phoenix Contact MC 1,5/3-ST-3,5 | 3-position field connector (TXD/RXD/GND) — reused from RS485's J5 | 1840379 | Phoenix Contact | https://www.newark.com/phoenix-contact/mc-1-5-3-st-3-5/pluggable-terminal-block-3-position/dp/14J3293

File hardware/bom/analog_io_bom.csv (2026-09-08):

Ref | Part | Role | MPN | Manufacturer | Distributor link
U9 | TI ADS1115 | 16-bit isolated-side ADC (2 of 4 channels used) | ADS1115IDGSR | Texas Instruments | https://www.ti.com/product/ADS1115
U10 | TI ISO1540 | Bidirectional I2C isolator (SDA+SCL) | ISO1540DR | Texas Instruments | https://www.ti.com/product/ISO1540
U11 | Microchip MCP4725 | 12-bit isolated-side DAC | MCP4725A0T-E/CH | Microchip | https://www.microchip.com/en-us/product/mcp4725
U12 | TI LM2904 | Dual op-amp — input-channel unity-gain buffers (both units used) | LM2904DR | Texas Instruments | https://www.ti.com/product/LM2904
U13 | TI LM2904 | Dual op-amp — output gain stage (1 of 2 units used; unit B spare headroom) | LM2904DR | Texas Instruments | https://www.ti.com/product/LM2904
D13 | Littelfuse SMBJ15CA | Bidirectional TVS — AI1 overvoltage protection | SMBJ15CA | Littelfuse | https://www.littelfuse.com/products/tvs-diodes/automotive-and-commercial-grade/smbj/smbj15ca
D14 | Littelfuse SMBJ15CA | Bidirectional TVS — AI2 overvoltage protection | SMBJ15CA | Littelfuse | https://www.littelfuse.com/products/tvs-diodes/automotive-and-commercial-grade/smbj/smbj15ca
R_top1 | Generic E96 resistor | AI1 0-10V divider top (0-10V stuffing option) | 100k | generic
R_bottom1 | Generic E96 resistor | AI1 0-10V divider bottom (0-10V stuffing option) | 11.0k | generic
R_top2 | Generic E96 resistor | AI2 0-10V divider top (0-10V stuffing option) | 100k | generic
R_bottom2 | Generic E96 resistor | AI2 0-10V divider bottom (0-10V stuffing option) | 11.0k | generic
R_in1 | Generic E96 resistor | Output gain-stage input resistor | 49.9k | generic
R_f1 | Generic E96 resistor | Output gain-stage feedback resistor | 100k | generic
J4 | Phoenix Contact MC 1,5/4-ST-3,5 | 4-position field connector (AI1/AI2/AO + shared GND_ANALOG_ISO return) | 1840382 | Phoenix Contact | https://www.mouser.com/datasheet/3/507/5/phoenix_contact_1840382_en.pdf

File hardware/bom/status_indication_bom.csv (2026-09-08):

Ref | Part | Role | MPN | Manufacturer | Distributor link
U2 | NXP PCA9535PW | 16-bit I2C GPIO expander (6 of 16 GPIO used; 10 spare/documented) | PCA9535PW | NXP | https://www.nxp.com/docs/en/data-sheet/PCA9535_PCA9535C.pdf
D_PWR | Generic 3mm THT LED (green) | PWR-OK indicator - 3.3V-LOGIC rail present | generic red/green/yellow/orange family | generic
D_HB | Generic 3mm THT LED (yellow) | HEARTBEAT indicator - MCU running | generic red/green/yellow/orange family | generic
D_LTE | Generic 3mm THT LED (yellow) | LTE modem status indicator | generic red/green/yellow/orange family | generic
D_WIFI | Generic 3mm THT LED (yellow) | WiFi status indicator | generic red/green/yellow/orange family | generic
D_ETH | Generic 3mm THT LED (yellow) | Ethernet link status indicator | generic red/green/yellow/orange family | generic
D_FLT | Generic 3mm THT LED (red) | FAULT indicator - any subsystem error | generic red/green/yellow/orange family | generic
R7 | Generic E24 resistor | LED current-limit (D_ETH channel) | 680 | generic
R8 | Generic E24 resistor | LED current-limit (D_FLT channel) | 680 | generic
R9 | Generic E24 resistor | LED current-limit (D_LTE channel) | 680 | generic
R10 | Generic E24 resistor | LED current-limit (D_WIFI channel) | 680 | generic
R11 | Generic E24 resistor | LED current-limit (D_HB channel) | 680 | generic
R13 | Generic E24 resistor | LED current-limit (D_PWR channel) | 680 | generic
R12 | Generic E24 resistor | I2C SCL pull-up to 3V3_LOGIC | 4.7k | generic
R14 | Generic E24 resistor | I2C SDA pull-up to 3V3_LOGIC | 4.7k | generic
R15 | Generic E24 resistor | INT pull-up to 3V3_LOGIC (documented spare - INT unused) | 10k | generic
C4 | Generic ceramic capacitor | U2 VDD-VSS decoupling | 100nF | generic

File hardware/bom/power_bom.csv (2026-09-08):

Ref | Part | Role | MPN | Manufacturer | Distributor link
J1 | Phoenix Contact MC 1,5/2-ST-3,5 | Field power input terminal block | 1840366 | Phoenix Contact | https://www.mouser.com/datasheet/3/507/5/phoenix_contact_1840366_en.pdf
F1 | Littelfuse RXEF135 | PTC resettable fuse | RXEF135 | Littelfuse | https://www.littelfuse.com/assetdocs/resettable-ptc-rxef-datasheet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
Q5 | TI CSD18531Q5A | N-MOSFET reverse-polarity switch | CSD18531Q5A | Texas Instruments | https://www.ti.com/product/CSD18531Q5A
U1 | TI LM74610-Q1 | Ideal diode controller | LM74610QDGKRQ1 | Texas Instruments | https://www.ti.com/lit/ds/symlink/lm74610-q1.pdf
U2 | TI TVS3300 | Flat-Clamp surge protection | TVS3300DRVR | Texas Instruments | https://www.ti.com/product/TVS3300
U3 | Wurth MagI3C-VDLM | 3.3V-LOGIC DC-DC module | 171013801 | Wurth Elektronik | https://www.we-online.com/en/components/products/datasheet/171013801.pdf
U4 | Wurth MagI3C-VDLM | 3.3V-LTE DC-DC module (3A) | 171033801 | Wurth Elektronik | https://www.we-online.com/components/products/datasheet/171033801.pdf
U5 | Wurth MagI3C-VDLM | 5V-RELAY DC-DC module | 171013801 | Wurth Elektronik | https://www.we-online.com/en/components/products/datasheet/171013801.pdf
U6 | Recom R1SX-3.33.3-R | Isolated 3.3V analog supply | R1SX-3.33.3-R | Recom Power | https://www.digikey.com/en/products/detail/recom-power/R1SX-3.33.3-R/6708875
U7 | Recom RK-0515S | Isolated 15V DC-DC module for analog output gain-stage supply | RK-0515S | Recom Power | https://recom-power.com/pdf/Econoline/RK_RH.pdf
CY1 | Wurth WCAP-CSSA | Input Y-cap EMI/safety | 8853522140011 | Wurth Elektronik | https://www.we-online.com/components/products/datasheet/8853522140011.pdf
C1 | Generic ceramic X7R 16V, 2.2uF | LM74610-Q1 charge-pump cap | generic | generic
R2/R5/R8 | Generic E96 402k | FB top resistor (3.3V rails) | generic | generic
R3/R6 | Generic E96 137k | FB bottom resistor (3.3V rails) | generic | generic
R9 | Generic E96 80.6k | FB bottom resistor (5V rail) | generic | generic
R1/R4/R7 | Generic 5.6k | FSW frequency-set resistor | generic | generic

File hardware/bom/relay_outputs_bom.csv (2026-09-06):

Ref | Part | Role | MPN | Manufacturer | Distributor link
K1 | Panasonic ALDP105 | Relay channel 1 | ALDP105 | Panasonic | https://na.industrial.panasonic.com/products/relays-contactors/mechanical-power-relays/lineup/general/series/1988/model/136824
K2 | Panasonic ALDP105 | Relay channel 2 | ALDP105 | Panasonic | https://na.industrial.panasonic.com/products/relays-contactors/mechanical-power-relays/lineup/general/series/1988/model/136824
K3 | Panasonic ALDP105 | Relay channel 3 | ALDP105 | Panasonic | https://na.industrial.panasonic.com/products/relays-contactors/mechanical-power-relays/lineup/general/series/1988/model/136824
K4 | Panasonic ALDP105 | Relay channel 4 | ALDP105 | Panasonic | https://na.industrial.panasonic.com/products/relays-contactors/mechanical-power-relays/lineup/general/series/1988/model/136824
Q1 | Nexperia MMBT3904 | NPN driver transistor channel 1 | MMBT3904 | Nexperia | https://assets.nexperia.com/documents/data-sheet/MMBT3904.pdf
Q2 | Nexperia MMBT3904 | NPN driver transistor channel 2 | MMBT3904 | Nexperia | https://assets.nexperia.com/documents/data-sheet/MMBT3904.pdf
Q3 | Nexperia MMBT3904 | NPN driver transistor channel 3 | MMBT3904 | Nexperia | https://assets.nexperia.com/documents/data-sheet/MMBT3904.pdf
Q4 | Nexperia MMBT3904 | NPN driver transistor channel 4 | MMBT3904 | Nexperia | https://assets.nexperia.com/documents/data-sheet/MMBT3904.pdf
R26 | Generic E24 resistor | Base resistor ch1 | 510 | generic
R27 | Generic E24 resistor | Base pull-down ch1 | 10k | generic
R28 | Generic E24 resistor | Base resistor ch2 | 510 | generic
R29 | Generic E24 resistor | Base pull-down ch2 | 10k | generic
R30 | Generic E24 resistor | Base resistor ch3 | 510 | generic
R31 | Generic E24 resistor | Base pull-down ch3 | 10k | generic
R32 | Generic E24 resistor | Base resistor ch4 | 510 | generic
R33 | Generic E24 resistor | Base pull-down ch4 | 10k | generic
D9 | Generic small-signal diode | Flyback diode ch1 | 1N4148 | generic
D10 | Generic small-signal diode | Flyback diode ch2 | 1N4148 | generic
D11 | Generic small-signal diode | Flyback diode ch3 | 1N4148 | generic
D12 | Generic small-signal diode | Flyback diode ch4 | 1N4148 | generic
J3 | Phoenix Contact MC 1,5/8-ST-3,5 | 8-position field connector (4x COM+NO independent) | 1840421 | Phoenix Contact | https://www.newark.com/phoenix-contact/mc-1-5-8-st-3-5/pluggable-terminal-block-8-position/dp/14J3298
C21 | Generic ceramic X7R, 10uF | Bulk cap at 5V_RELAY entry | generic | generic
C22 | Generic ceramic X7R, 100nF | Bypass cap at 5V_RELAY entry | generic | generic

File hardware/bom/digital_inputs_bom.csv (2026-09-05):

Ref | Part | Role | MPN | Manufacturer | Distributor link
U7 | Lite-On LTV-247 | 4-channel opto-isolator (channels 1-4) | LTV-247 | Lite-On | https://www.digikey.com/en/products/detail/liteon/LTV-247/4307982
U8 | Lite-On LTV-247 | 4-channel opto-isolator (channels 5-8) | LTV-247 | Lite-On | https://www.digikey.com/en/products/detail/liteon/LTV-247/4307982
J2 | Phoenix Contact MC 1,5/9-ST-3,5 | 8-channel + common field connector | 1840434 | Phoenix Contact | https://www.newark.com/phoenix-contact/mc-1-5-9-st-3-5/plug-free-3-5mm-9way/dp/14J3299
D1 | Generic small-signal diode | Reverse-protection ch1 | 1N4148 | generic
D2 | Generic small-signal diode | Reverse-protection ch2 | 1N4148 | generic
D3 | Generic small-signal diode | Reverse-protection ch3 | 1N4148 | generic
D4 | Generic small-signal diode | Reverse-protection ch4 | 1N4148 | generic
D5 | Generic small-signal diode | Reverse-protection ch5 | 1N4148 | generic
D6 | Generic small-signal diode | Reverse-protection ch6 | 1N4148 | generic
D7 | Generic small-signal diode | Reverse-protection ch7 | 1N4148 | generic
D8 | Generic small-signal diode | Reverse-protection ch8 | 1N4148 | generic
R10 | Generic E24 2.4k 1W | Current-limiting ch1 | generic | generic
R11 | Generic E24 10k | Pull-up ch1 | generic | generic
R12 | Generic E24 2.4k 1W | Current-limiting ch2 | generic | generic
R13 | Generic E24 10k | Pull-up ch2 | generic | generic
R15 | Generic E24 2.4k 1W | Current-limiting ch3 | generic | generic
R17 | Generic E24 10k | Pull-up ch3 | generic | generic
R14 | Generic E24 2.4k 1W | Current-limiting ch4 | generic | generic
R16 | Generic E24 10k | Pull-up ch4 | generic | generic
R19 | Generic E24 2.4k 1W | Current-limiting ch5 | generic | generic
R21 | Generic E24 10k | Pull-up ch5 | generic | generic
R18 | Generic E24 2.4k 1W | Current-limiting ch6 | generic | generic
R20 | Generic E24 10k | Pull-up ch6 | generic | generic
R23 | Generic E24 2.4k 1W | Current-limiting ch7 | generic | generic
R25 | Generic E24 10k | Pull-up ch7 | generic | generic
R22 | Generic E24 2.4k 1W | Current-limiting ch8 | generic | generic
R24 | Generic E24 10k | Pull-up ch8 | generic | generic
C13 | Generic ceramic X7R, 100nF | Filter cap ch1 | generic | generic
C14 | Generic ceramic X7R, 100nF | Filter cap ch2 | generic | generic
C16 | Generic ceramic X7R, 100nF | Filter cap ch3 | generic | generic
C15 | Generic ceramic X7R, 100nF | Filter cap ch4 | generic | generic
C18 | Generic ceramic X7R, 100nF | Filter cap ch5 | generic | generic
C17 | Generic ceramic X7R, 100nF | Filter cap ch6 | generic | generic
C20 | Generic ceramic X7R, 100nF | Filter cap ch7 | generic | generic
C19 | Generic ceramic X7R, 100nF | Filter cap ch8 | generic | generic

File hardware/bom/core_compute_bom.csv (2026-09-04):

Ref | Part | Role | MPN | Manufacturer | Distributor link
U1 | Espressif ESP32-S3-WROOM-1U-N16R8 | Main MCU module | ESP32-S3-WROOM-1U-N16R8 | Espressif Systems | https://documentation.espressif.com/api/resource/doc/file/3yD6w5Y5/FILE/esp32-s3-wroom-1_wroom-1u_datasheet_en.pdf
J1 | Molex 216989-0001 | USB-C receptacle, USB2.0-only, 14-pin | 216989-0001 | Molex | https://www.digikey.com/en/products/detail/molex/2169890001/13913746
C1 | Generic ceramic X7R, 10uF | 3V3 bulk reservoir cap | generic | generic
C2 | Generic ceramic X7R, 0.1uF | 3V3 bypass cap | generic | generic
C3 | Generic ceramic X7R, 1uF | EN RC delay cap | generic | generic
R1 | Generic E24 10k | EN pull-up | generic | generic
R2 | Generic E24 10k | GPIO0 pull-down | generic | generic
R3 | Generic E24 22 | USB D+ series resistor | generic | generic
R4 | Generic E24 22 | USB D- series resistor | generic | generic
R5 | Generic E24 5.1k | USB-C CC1 pull-down | generic | generic
R6 | Generic E24 5.1k | USB-C CC2 pull-down | generic | generic
SW1 | E-Switch TL1150AF070Q | Manual reset (EN) | TL1150AF070Q | E-Switch | https://www.digikey.com/en/products/detail/e-switch/TL1150AF070Q/1556582
SW2 | E-Switch TL1150AF070Q | Manual boot-mode entry (GPIO0) | TL1150AF070Q | E-Switch | https://www.digikey.com/en/products/detail/e-switch/TL1150AF070Q/1556582

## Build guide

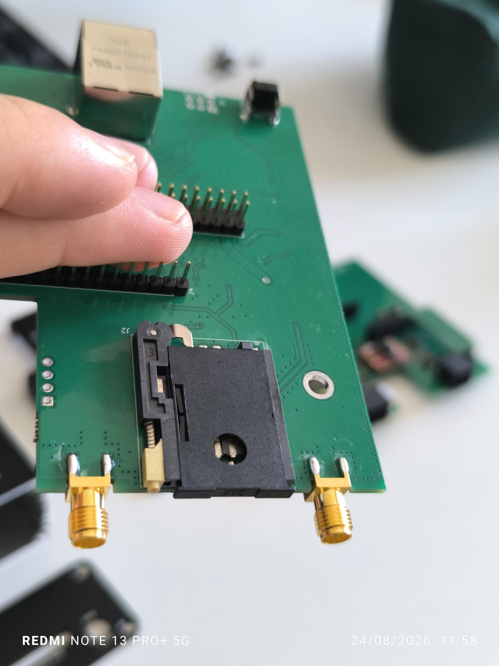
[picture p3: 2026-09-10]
reference-photos/2026-09-08-hardware-assembly-photos/photo_29_fba0c3c6.jpg

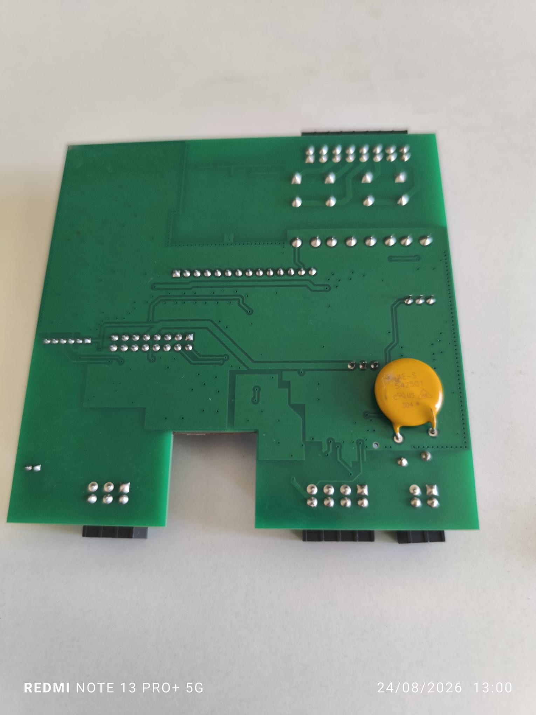
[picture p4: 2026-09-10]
reference-photos/2026-09-08-hardware-assembly-photos/photo_04_050dcd50.jpg

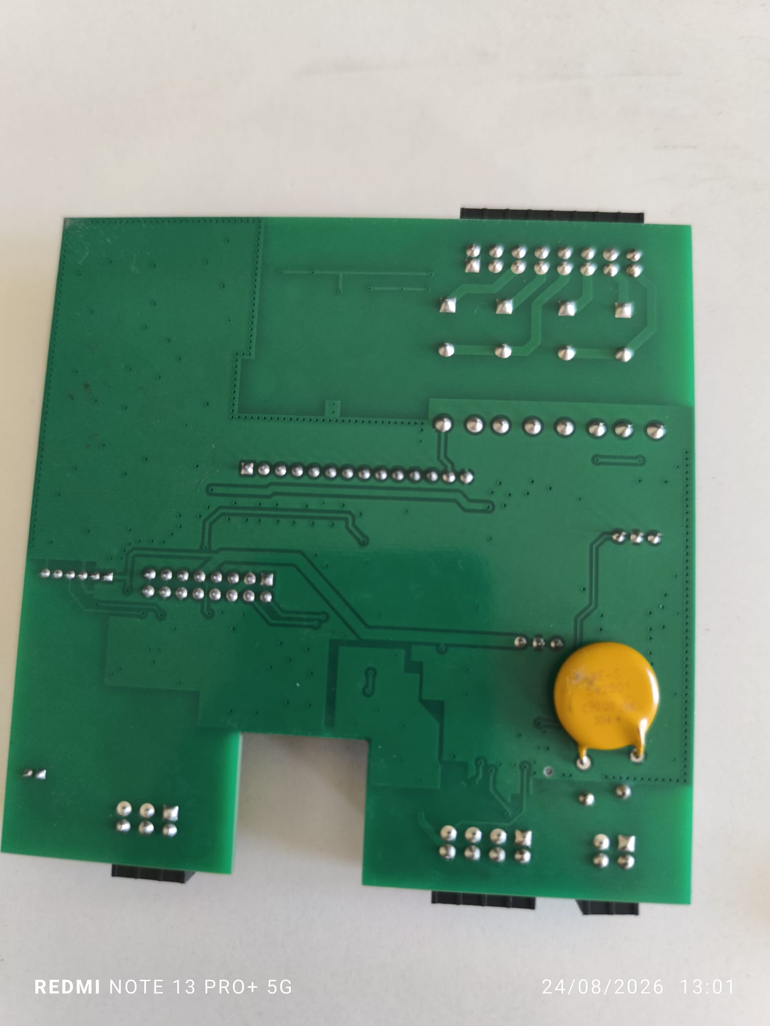
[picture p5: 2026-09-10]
reference-photos/2026-09-08-hardware-assembly-photos/photo_02_070ee02f.jpg

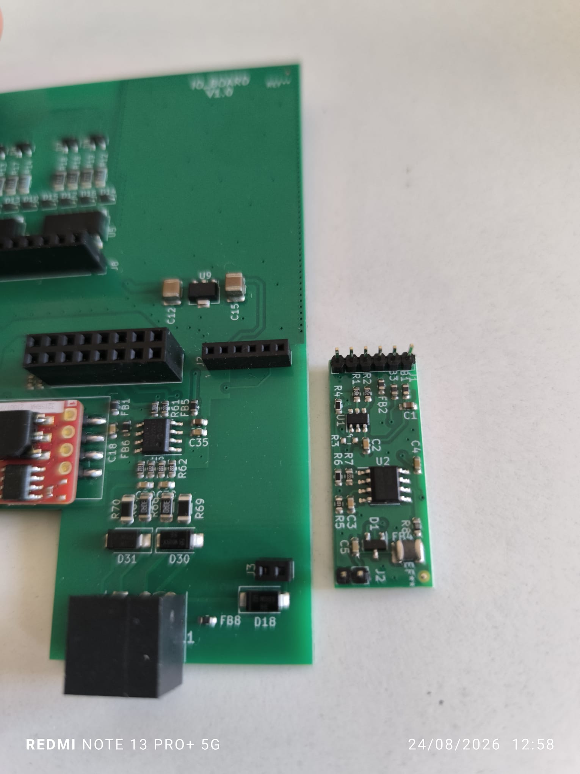
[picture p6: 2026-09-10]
reference-photos/2026-09-08-hardware-assembly-photos/photo_07_43a18074.jpg

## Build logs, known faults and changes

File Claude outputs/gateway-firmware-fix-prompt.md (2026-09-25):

# Fix request: DIY ESP32-S3 IoT gateway firmware — confirmed findings

## Context

This is a from-scratch DIY IoT gateway firmware project (ESP32-S3-WROOM-1U-N16R8, PlatformIO/pioarduino, `framework = arduino`), built by an EEE student as a hands-on learning project. It replicates the functional pattern of a commercial industrial IoT gateway (Ethernet/LTE/WiFi backhaul, Modbus RTU polling, MQTT telemetry, remote config, signed OTA updates). **Do not write the name of any specific commercial reference product into any git-tracked file (code, comments, docs, commit messages) — refer to it only as "the reference device" if you need to at all.** This is a standing project rule, not new.

Two independent review passes have now gone through the F1–F4 firmware (protocol/logic, drivers, industrial-grade layer, system integration) and produced a confirmed, deduplicated list of findings below. **Your job this time is to actually fix these**, following the codebase's existing conventions (it already has an established pattern for checked-and-logged init calls, bounds-checked accessors, and Unity tests under `firmware/test/` — match it, don't introduce a new style). Work through the list in priority order. For each fix:

- Make the minimal correct change — don't refactor unrelated code while you're in a file.
- If a fix naturally implies a test (most of these do), add or extend the Unity test in `firmware/test/`.
- If a finding turns out, on inspection, to not actually apply to the current code (something may have shifted since these were written), say so explicitly rather than silently skipping it or forcing an unnecessary change.
- After each priority group, give a short summary of exactly what changed (files + one line each) before moving to the next group.

One item (Priority 4, M7) needs you to actually check a fact before touching any code — see its note.

---

## Priority 1 — Boot-sequence integrity (do these together, same root cause)

**P1.1 — I2C bus is never initialized (Critical).**
Nothing in the firmware calls `Wire.begin(PIN_I2C_SDA, PIN_I2C_SCL)`. Three drivers ride the shared I2C bus and depend on it: `pca9535` (via `status_leds`), `ads1115_adc`, `mcp4725_dac`. Without `Wire.begin()`, every I2C transaction from these drivers will fail on real hardware (status LEDs and analog I/O non-functional). Add the `Wire.begin(PIN_I2C_SDA, PIN_I2C_SCL)` call in `main.cpp`'s `setup()`, before any of the three I2C-bus consumers' own `.begin()` calls.

**P1.2 — Almost no subsystem init return value is checked in `setup()` (Critical/systemic).**
`g_modbus.begin()` is checked and logged on failure — that's the existing correct pattern. Nearly everything else isn't: `g_di.begin()`, `g_relays.begin()`, `g_ai.begin()`, `g_ao.begin()`, `g_leds.begin()`, `g_log.begin()`, `g_lte.begin()`, `g_watchdog.begin()` all return a boolean signaling hardware health, and none of the return values are inspected. A real hardware fault at boot (bad solder joint, wrong I2C address, SPI wiring issue) currently fails completely silently. Fix: check every one of these the same way `g_modbus.begin()` already is — log a warning (or whatever the established severity convention is) on failure, and decide per-subsystem whether a failure should be fatal (e.g., watchdog failing to init is probably worth being loud about) or degraded-but-continue (e.g., DAC failing shouldn't stop the whole device from booting). Use your judgment per subsystem but be consistent with how `g_modbus.begin()`'s failure is currently handled.

**P1.3 — Modbus task-spawn failure is discarded.**
`g_modbus.start(&g_watchdog)` returns a boolean indicating whether the underlying `xTaskCreatePinnedToCore()` call succeeded, and the return value is silently discarded in `main.cpp`. If task creation fails, the whole Modbus polling engine silently never runs. Check and log this return value the same way as P1.2.

---

## Priority 2 — Security / data-integrity

**P2.1 — `url_host` hostname extraction can be bypassed via URL userinfo (High).**
`extractHttpsUrlHost()` in `firmware/lib/url_host` stops at the first `/`, `:`, or `?` after `https://`, but never special-cases `@` (the URL userinfo delimiter). Real HTTP client URL parsing (RFC 3986 order) splits the authority on `@` first, keeping only what follows the *last* `@` as host[:port]. A crafted URL like `https://trusted-host.example:@evil.com/malicious.bin` currently extracts `trusted-host.example` (passes the allowlist) while the actual HTTP client would connect to `evil.com`. Fix `extractHttpsUrlHost()` to find the authority segment (up to the first `/` or end-of-string), then within that segment find the *last* `@` and take everything after it as the host[:port] candidate before applying the existing `:`/`?` truncation logic. Add a test case covering exactly the `user:pass@host` and `host:@evil.com` shapes.

**P2.2 — `modbus_pdu_parse_write_response()` doesn't validate response length (High).**
Real write-acknowledgment responses (write single coil / write single register / write multiple registers) are always exactly 5 bytes (function code + 2-byte address + 2-byte value/quantity). The current check only requires `pdu_len >= 2` and doesn't verify the echoed address/value. Fix: require `pdu_len == 5` for the applicable function codes, and add a test asserting a truncated (2–4 byte) response with a matching function code is now correctly rejected.

**P2.3 — `device_config.cpp`'s `readString()` silently reports success with an emptied value on overflow (High).**
It calls `Preferences::getString(key, out, out_size)` and discards the return value, then returns `true` based only on `prefs.isKey(key)`. Real `Preferences::getString()` returns 0 (and leaves the pre-cleared buffer untouched, i.e. empty) if the stored value doesn't fit the buffer — so an over-length stored value currently comes back as "successfully read, value is empty string," indistinguishable from a genuinely-empty stored value. Fix: check `getString()`'s actual return value and have `readString()` return `false` (or otherwise signal truncation, matching whatever error-signaling convention the rest of `device_config.cpp` uses) when the read didn't fit. Also check whether any setter path (config setters, the commissioning-portal form handler) should enforce a max length matching the fixed-size buffers callers read into (`main.cpp`'s WiFi/WireGuard/LTE buffers etc.) — if there's an easy place to add that bound, do it; if it needs a broader buffer-size audit, just fix `readString()`'s truncation-detection and note the length-limit gap in your summary rather than guessing at the right limits.

---

## Priority 3 — Contract violations currently masked by a well-behaved caller

**P3.1 — `OtaUpdate::end()` calls `Update.end(true)`, skipping the real completeness check (High).**
`Update.end(true)` tells the underlying Arduino `Update` library to skip its own "was the declared size actually fully written" rejection, silently redefining the expected size to whatever was written so far. This contradicts `ota_update.h`'s own documented contract ("returns false if the image was incomplete"). It's currently masked because the one real caller (`ota_session`) independently tracks total bytes read and aborts before ever calling `end()` on a mismatch — but the `OtaUpdate` class itself doesn't honor its own contract. Fix: have `OtaUpdate` track the expected total size itself (it should already know this, since the caller presumably passes it to `begin()`) and call `Update.end(false)`, or explicitly compare bytes-written against the expected size before calling `end()` at all and return `false` without committing if they don't match. Don't just rely on the caller continuing to behave correctly.

---

## Priority 4 — Medium-severity items

**P4.1 — W5500 Ethernet has no hardware reset GPIO wired (Medium — likely a hardware/docs issue, not purely firmware).**
`ethernet_link.cpp` passes `-1` for the reset pin, and `pin_map.h` has no corresponding `#define`. `docs/architecture.md`'s design notes claim a reset line exists for this exact recovery purpose, but its own pin table only lists 5 Ethernet signals and its changelog's "28 signals total" doesn't match the table (27). This likely isn't fixable in firmware alone — flag it back to me rather than inventing a GPIO assignment. If you want to do something now: fix the doc inconsistency (27 vs. 28, and either remove the reset-line claim or mark it as a known Rev-A gap) so the docs stop contradicting themselves, and leave the actual GPIO decision for a hardware revision.

**P4.2 — `pca9535`'s output shadow isn't synced from the chip's real power-on-reset state (Medium).**
`output_shadow_` defaults to `0x0000`, but the PCA9535's real POR output register value is `0xFFFF`. `begin()` only does an address-ACK probe, never reads the chip's actual current output state. The one real caller (`status_leds`) happens to call `writeOutputs(0xFFFF)` before ever calling `writePin()`, masking this — but the driver is documented as generic/reusable and shouldn't rely on caller behavior. Fix: either have `begin()` read back the chip's actual output register into `output_shadow_` (if the PCA9535 supports reading its own output register state — check the datasheet register map), or make `writePin()` refuse to operate (return false / assert) until an initial `writeOutputs()` call has established a known shadow state. Pick whichever is cleaner given the actual chip's readable-register support.

**P4.3 — No anti-rollback/downgrade protection on OTA (Medium).**
The trigger payload's `version` field is informational-only; a validly-signed old image (including one with a since-fixed vulnerability) can be replayed indefinitely. Add a monotonic minimum-version check: store the currently-running firmware's version (however that's currently tracked — check if there's already a version constant/NVS field, don't invent a second one) and reject an OTA trigger whose declared version is not strictly greater, before even attempting the download. If there's genuinely no existing version-tracking mechanism to hook into, say so and propose the minimal one rather than half-implementing it.

**P4.4 — `modbus_master` has unprotected shared state and a missing mutex null-check (Medium).**
`targets_[]`, `target_count_`, `last_polled_millis_[]` are written by `addTarget()` with no locking, while read by the polling task (`runLoop()`) with no locking either — currently safe only because `addTarget()` isn't documented/expected to be called after `start()`. Add the same mutex protection already used for the readings cache around `addTarget()`'s writes (or explicitly assert/reject `addTarget()` calls after `start()` has run, whichever fits the intended usage better). Separately, `getReading()` calls `xSemaphoreTake()` without checking `mutex_` for null first — add a null-check that fails safe (return false / no data) if called before `begin()`.

**P4.5 — Boot-time OTA rollback confirmation happens too early (Medium).**
`g_ota.confirmValid()` (canceling the bootloader's pending-rollback state) runs unconditionally near the start of `setup()`, before networking/MQTT are ever tested — so the rollback safety net only catches a crash before `setup()`, not a new image that boots but fails to actually connect. Move the `confirmValid()` call to after a meaningful "this firmware actually works" checkpoint — e.g., after the first successful network connect and/or first successful MQTT connect — so a new image that boots but can never reach the network still rolls back on the next reset. Be careful not to move it so late that a device with no configured network (fresh out of commissioning) gets stuck never confirming — think through the commissioning-portal-active case specifically and handle it (confirm valid once the portal itself is up and serving, since that's a legitimate operational state too).

**P4.6 — MQTT offline outbox can deliver messages out of order (Medium).**
The outbox fills the first free slot on enqueue and flushes in slot order, stopping at the first failure. If an interior message permanently fails (e.g., oversized payload) while slots ahead of it drain and free up, newer messages backfill those freed slots and get sent before the still-stuck older one. Fix: flush should stop advancing past a genuinely failed (not just transiently unpublishable) message and not free/reuse a slot out of order — or, simpler, make the outbox a true ring buffer / linked list with strict FIFO semantics rather than free-slot reuse. Pick whichever fits the existing outbox's data structure with the least churn, and add a test that reproduces the interior-failure-then-backfill scenario and asserts ordering is preserved.

**P4.7 — `Serial`/UART0 vs. RELAY3/RELAY4 conflict — VERIFY BEFORE CHANGING ANYTHING.**
`pin_map.h` puts RELAY3/RELAY4 on GPIO43/44 (the module's default UART0 TX/RX), on the assumption that `Serial` resolves to native USB-CDC, not physical UART0, for this board. `platformio.ini` doesn't explicitly set `ARDUINO_USB_CDC_ON_BOOT` or `ARDUINO_USB_MODE`, so this depends entirely on the `esp32-s3-devkitc-1` board manifest's own default. **Before touching any code for this one: actually check the board manifest** (`boards/esp32-s3-devkitc-1.json` in the installed platform package, or the pioarduino/arduino-esp32 board definitions) for its default USB-CDC-on-boot setting. If the manifest already defaults to USB-CDC — this is a non-issue, just add an explicit `build_flags = -DARDUINO_USB_CDC_ON_BOOT=1` (or equivalent) to `platformio.ini` to make the assumption explicit and no longer dependent on an implicit board default, and note in your summary that no pin conflict exists. If it does NOT default to USB-CDC — this is a real conflict, and you'll need to either force USB-CDC mode explicitly via `platformio.ini` build flags, or move RELAY3/RELAY4 off GPIO43/44 in `pin_map.h` (flag this to me instead of silently reassigning hardware pins, since that's a hardware-layer decision). Report which case it was and what you found in the manifest — don't just assert one way or the other without having actually looked.

---

## Priority 5 — Low-severity, batch these whenever convenient

- **L1.** `power_safety`: when NVS fails to open, it currently defaults to *no* startup delay. Since a failing NVS open is itself a plausible brownout symptom, default to applying the delay (fail toward caution) instead.
- **L2.** `event_log`: tag/message fields are written unescaped into comma-separated log lines. Escape or otherwise neutralize embedded commas/newlines in logged fields (even though no current call site passes attacker-influenced content, make it safe for future ones).
- **L3.** `mqtt_client_wrapper`: `publish()`/`enqueue()` don't null-check `topic`/`payload` before use (unlike `subscribe()`, which does). Add the same null-checks for consistency.
- **L4.** `ota_trigger`'s numeric parser relies on `unsigned long` being 32 bits; on a 64-bit host build a crafted oversized value can avoid saturation and get silently truncated by a later narrowing cast, bypassing the intended bound. Parse into an explicit `uint32_t`-safe path (e.g. use `strtoul` then explicitly clamp/reject values `> UINT32_MAX` before the cast) so behavior doesn't depend on host `unsigned long` width. Add a test near the actual 32-bit boundary, not just an arbitrarily large value.
- **L5.** `ota_session`'s download loop doesn't cap a single read to the remaining declared image size, so a compliant server sending the exact declared size immediately followed by more coalesced data triggers an avoidable abort instead of a clean stop. Clamp each read to `min(buffer_size, remaining_expected_bytes)`.
- **L6.** `image_verify`: `mbedtls_sha256_starts`/`mbedtls_sha256_update` return codes aren't checked. Check them and fail closed (this is a robustness improvement — currently fails safe anyway via the later hash-mismatch check, but don't rely on that).
- **L7.** Buffer-size mismatch: `ota_trigger` accepts signatures up to 180 chars, but `ota_session` decodes into a 128-byte buffer. Align the two bounds (128 is almost certainly the correct one, given real ECDSA-P256 signatures are far shorter than either) so a syntactically-valid-per-the-parser value can't be rejected later by the decode step instead of the parser.
- **L8.** `StatusLed::HEARTBEAT` is defined but never driven. Either wire it up (e.g., blink it in `loop()` as a basic "firmware is alive" indicator) or remove the unused enum value — your call, note which you picked.
- **L9.** `McpAnalogOutput` (`g_ao`) is initialized but has no consumer anywhere (no `loop()` usage, no rule-engine action type targets it). If there's no near-term plan to use it, leave it initialized (harmless, DAC POR state is 0V) but add a one-line comment noting it's currently unused, so it doesn't look like an oversight later.

---

## Test coverage gaps (add these regardless of whether the related bug above gets fixed first)

- **T1.** `modbus_pdu`: several read-request builders and both response-parsing functions (bit-response, write-response) have zero test coverage. Add tests, especially covering P2.2's fix.
- **T2.** `modbus_rtu`/`modbus_tcp`/`io_state`: add tests for too-short frame, buffer-too-small, out-of-range channel index, and null-pointer argument cases.
- **T3.** `ota_update.cpp`'s actual logic (rollback query/confirm/reject, `begin`/`write`/`end`) has zero test coverage — only a pure progress-percentage helper is tested. Add tests, especially covering P3.1's fix.
- **T4.** `power_safety::begin()`, including its NVS-failure fallback path (L1), has zero test coverage.
- **T5.** `url_host` has no test for the `@`-userinfo URL shape — add as part of P2.1.
- **T6.** No test exercises `ota_trigger`'s numeric parser near the actual 32-bit boundary — add as part of L4.

## Documentation debt (fix after the code changes above, so the docs describe the post-fix state)

- **D1.** `docs/roadmap.md` / `CLAUDE.md` still describe the `platformio.ini` flash-size/PSRAM board override as "still open" — it's already present in the file. Update both.
- **D2.** Both docs have a stale section describing an older `lte_modem` (with AT-command/UART logic and a separate `lte_at_parse` module) that was later deleted — contradicts a later, correct section in the same docs. Remove or clearly mark the stale section as superseded.
- **D3.** Several "N checks, all passing" test-count claims (`ota_trigger`, `url_host`, `net_allowlist`, `rule_engine`) don't match the actual number of test cases in the corresponding `firmware/test/` file. Recount and correct after you've added the new tests above.
- **D4.** Three verification claims (`image_verify`, the LTE/PPP module pairing, and the network-priority fallback logic in `main.cpp`) describe passing behavior tests with specific check counts, but no corresponding test file exists in the repo — those tests were run in an ephemeral scratch environment and never committed. If you have time, recreate them as proper committed tests under `firmware/test/`; if not, at minimum correct the docs to stop claiming a reproducible test exists.
- **D5.** `docs/roadmap.md` and `CLAUDE.md` disagree on whether the digital-input strapping-pin question (GPIO3/GPIO46 usage) is still open or already resolved. Reconcile to one consistent status.

---

## When you're done

Give a final summary organized by priority group (P1–P5, tests, docs), one or two lines per item: what you changed, or why you determined a finding didn't apply. Flag anything from P1–P4 you couldn't fully resolve without a decision only I can make (P4.1's Ethernet reset GPIO and the "real GPIO conflict" branch of P4.7 are the two most likely candidates) rather than guessing.

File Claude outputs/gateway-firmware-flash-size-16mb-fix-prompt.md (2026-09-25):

# Fix: real ESP32-S3 build fails at partition table generation (flash size mismatch)

## Ground rules — read before touching anything

- Touch only the single line specified below in `firmware/platformio.ini`. Do not modify anything else in this file or any other file.
- Never write the device's real commercial name into any file, comment, or commit message. Refer to it only as "a commercial industrial IoT gateway reference device" if it needs mentioning at all.
- You cannot compile or run `pio`. Do not claim anything is "tested," "verified," "working," or "fixed." State exactly what you changed. A human will run `pio run -e esp32-s3-devkitc-1` afterward to confirm — this build takes roughly 15-20 minutes the first time, so don't expect instant feedback.
- If `[env:esp32-s3-devkitc-1]` doesn't look the way it's described below, stop and report the discrepancy instead of improvising.

## Background (context only, don't act on this part)

`pio run -e esp32-s3-devkitc-1` compiled every single source file successfully — all of FreeRTOS, WiFi, BLE, mbedtls, and every file under `lib/` and `src/` — with zero errors in the actual code. The build only failed at the very last step, generating the partition table:

```
Partitions tables occupies 15.6MB of flash (16384000 bytes) which does not fit in configured flash size 8MB. Change the flash size in menuconfig under the 'Serial Flasher Config' menu.
*** [.pio/build/esp32-s3-devkitc-1/partitions.bin] Error 2
```

This is a configuration mismatch, not a code defect. The real hardware is an ESP32-S3-WROOM-1U-N16R8 module (16MB flash), but `board = esp32-s3-devkitc-1` in `firmware/platformio.ini` is a generic PlatformIO board profile that defaults to an 8MB (N8) flash variant. The project's `[env:esp32-s3-devkitc-1]` section already has a `board_build.flash_size = 16MB` override with a header comment explaining exactly this mismatch — but the build log shows the framework's internal sdkconfig merge step (labeled `*** Compile Arduino IDF libs for esp32-s3-devkitc-1 ***` in the log) explicitly replacing the correct 16MB setting back down to 8MB:

```
Replace: CONFIG_ESPTOOLPY_FLASHSIZE="16MB" with: CONFIG_ESPTOOLPY_FLASHSIZE="8MB"
```

So `board_build.flash_size` is present and correctly written, but isn't fully honored at that specific internal build stage for this board/framework combination — a known category of rough edge where a generic board profile's own baked-in flash size wins over a project's override during one particular merge step.

## The fix

In `firmware/platformio.ini`, inside the existing `[env:esp32-s3-devkitc-1]` section, find this line:

```ini
board_build.flash_size = 16MB
```

Add a new line directly after it:

```ini
board_upload.flash_size = 16MB
```

`board_upload.flash_size` is a separate PlatformIO directive from `board_build.flash_size` (one affects the esptool/upload-side flash size declaration, the other affects the CMake/IDF build-side config) — some pioarduino build stages read from the upload-side setting rather than the build-side one, which is the likely reason the existing override isn't fully taking effect. Setting both together is the standard workaround for this situation.

Do not change, remove, or reorder any other line in this section (`board_build.arduino.memory_type`, `board_build.partitions`, `custom_sdkconfig`, etc. all stay exactly as they are).

## After the change

Confirm the one line you added and its exact position in the file (immediately after `board_build.flash_size = 16MB`). Don't attempt to run `pio` yourself — a human will run `pio run -e esp32-s3-devkitc-1` afterward, and if this single addition doesn't fully resolve it, the next step would likely be clearing the build cache (`pio run -t clean -e esp32-s3-devkitc-1`) since PlatformIO can sometimes cache a stale sdkconfig merge from a prior failed build — but that's a separate troubleshooting step, not part of this fix, and shouldn't be done pre-emptively.

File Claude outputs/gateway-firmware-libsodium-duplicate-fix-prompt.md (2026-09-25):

# Fix: `pio run -e esp32-s3-devkitc-1` fails with a `port` build-directory collision

## Ground rules — read before touching anything

- Touch only the two exact edits specified below, in the two files named. Do not modify anything else in either file, and do not touch any other file.
- Never write the device's real commercial name into any file, comment, or commit message. Refer to it only as "a commercial industrial IoT gateway reference device" if it needs mentioning at all.
- You cannot compile or run `pio`. Do not claim anything is "tested," "verified," "working," or "fixed." State exactly what you changed. A human will run `pio run -e esp32-s3-devkitc-1` afterward to confirm.
- If either file doesn't look the way it's described below, stop and report the discrepancy instead of improvising.

## Background (context only, don't act on this part)

`pio run -e esp32-s3-devkitc-1` fails during the Arduino-sketch build stage (after the ESP-IDF libs precompile stage now succeeds cleanly) with:

```
*** '.../firmware/.pio/build/esp32-s3-devkitc-1/port' already has a source directory:
'.../firmware/.pio/libdeps/esp32-s3-devkitc-1/libsodium/port'.
```

This was confirmed, via direct inspection of the checked-out library folders, to be caused by PlatformIO installing **two separate copies of the `libsodium` library**:

- `.pio/libdeps/esp32-s3-devkitc-1/libsodium/` — installed because `firmware/platformio.ini`'s `lib_deps` explicitly pins it: `https://github.com/esphome-libs/libsodium.git#1.10021.11`
- `.pio/libdeps/esp32-s3-devkitc-1/libsodium@src-<hash>/` — installed automatically because `wireguard`'s own `library.json` already declares `libsodium ^1.10018.1` as its own dependency, resolved via PlatformIO's package registry

A `diff -rq` between the two copies' `port/` folders came back with zero differences — they are byte-identical. Both copies define their `port/*.c` sources via a `srcFilter` that reaches outside their own `srcDir` (`+<../../../port/version.c>` etc.), and SCons maps that escaped path to the same unqualified `.pio/build/esp32-s3-devkitc-1/port` build directory for both copies, so the second one collides with the first.

The explicit `libsodium` pin in `lib_deps` was added deliberately when `wireguard` was integrated — `platformio.ini`'s own header comment explains that all `lib_deps` entries were pinned via direct git URL (rather than PlatformIO's registry package names) because the registry was network-blocked in the environment this project was originally developed in. That restriction does not apply in the environment this is actually being built in — a real `pio run` on the real build machine shows PlatformIO reaching the registry successfully (installing `Unity` via the registry, and auto-resolving `wireguard`'s own `libsodium` dependency via the registry too). So the explicit pin is no longer needed and is what's causing the duplicate-copy collision.

A repo-wide grep of `lib/`, `src/`, and `include/` confirmed nothing in this project's own code calls any libsodium API directly (`sodium_*`, `crypto_sign`, `crypto_box`, `crypto_secretbox`, `crypto_generichash`, `randombytes_buf`, etc. — zero matches). The only reference to `libsodium` anywhere in project code is a comment in `lib/wireguard_link/wireguard_link.h` noting it's pinned in `platformio.ini` "the same way" as wireguard — libsodium is purely an internal implementation detail of the `wireguard` library, never touched directly.

## Fix — two edits

### Edit 1: `firmware/platformio.ini`

In the `[env:esp32-s3-devkitc-1]` section, find this `lib_deps` block:

```ini
lib_deps =
    https://github.com/knolleary/pubsubclient.git
    https://github.com/esphome-libs/wireguard.git#v0.4.6
    https://github.com/esphome-libs/libsodium.git#1.10021.11
```

Remove the third line so it becomes:

```ini
lib_deps =
    https://github.com/knolleary/pubsubclient.git
    https://github.com/esphome-libs/wireguard.git#v0.4.6
```

Do not touch the header comment above `lib_deps` (the one explaining why entries are pinned via git URL) — it's still accurate for the two remaining entries. Do not touch anything else in this section (`board_build.flash_size`, `board_upload.flash_size`, `board_build.partitions`, `custom_sdkconfig`, etc. all stay exactly as they are).

### Edit 2: `firmware/lib/wireguard_link/wireguard_link.h`

Find this sentence, inside the larger comment block near the top of the file:

```
// i.e. `framework = espidf`). platformio.ini's lib_deps now pulls it
// (and its own libsodium dependency, pinned the same way - see that
// file's comment) directly; this is the real, confirmed integration
// shape, not an unverified guess. What's still genuinely unverified is
```

Replace just that sentence (keep everything else in the comment block, before and after, exactly as it is) with:

```
// i.e. `framework = espidf`). platformio.ini's lib_deps now pulls it
// directly. libsodium is deliberately NOT pinned separately there -
// wireguard's own library.json already declares a libsodium dependency,
// which PlatformIO resolves automatically; pinning it a second time via
// an explicit git URL caused PlatformIO to install two separate copies
// of it, which collided during the SCons build (both copies' port/
// source folder mapped to the same build directory). This is the real,
// confirmed integration shape, not an unverified guess. What's still
// genuinely unverified is
```

Only change this one sentence. Leave the rest of the comment block (before this point and after "What's still genuinely unverified is") exactly as it is.

## After both edits

List both files you edited with a one-line note of what changed in each. Don't run or claim to have run `pio`. A human will delete `.pio/libdeps/esp32-s3-devkitc-1/` (to force a clean re-resolution of dependencies against the new `lib_deps`) and then run `pio run -e esp32-s3-devkitc-1` to confirm.

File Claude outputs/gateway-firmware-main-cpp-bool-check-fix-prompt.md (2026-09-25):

# Fix: `pio run -e esp32-s3-devkitc-1` fails compiling `src/main.cpp` — 3 `void`-to-`bool` conversion errors

## Ground rules — read before touching anything

- Touch only `firmware/src/main.cpp`, and only the two exact blocks specified below. Do not touch `firmware/lib/di_driver/`, `firmware/lib/relay_driver/`, or `firmware/lib/lte_modem/` — those files were read and confirmed correct as-is; this is not a library bug.
- Never write the device's real commercial name into any file, comment, or commit message. Refer to it only as "a commercial industrial IoT gateway reference device" if it needs mentioning at all.
- You cannot compile or run `pio`. Do not claim anything is "tested," "verified," "working," or "fixed." State exactly what you changed. A human will run `pio run -e esp32-s3-devkitc-1` afterward to confirm.
- If either block below doesn't match `main.cpp`'s current content exactly, stop and report the discrepancy instead of improvising.

## Background (context only, don't act on this part)

`pio run -e esp32-s3-devkitc-1` now compiles every `lib/` module, `src/main.cpp`, and the entire Arduino framework core cleanly — this is the whole real codebase building for the first time. The only remaining failure is 3 compile errors in `main.cpp` itself:

```
src/main.cpp:389:20: error: could not convert 'g_di.DigitalInputs::begin()' from 'void' to 'bool'
src/main.cpp:390:24: error: could not convert 'g_relays.RelayOutputs::begin()' from 'void' to 'bool'
src/main.cpp:506:23: error: could not convert 'g_lte.LteModem::powerOn()' from 'void' to 'bool'
```

`main.cpp`'s boot sequence wraps a block of peripheral `begin()` calls in `if (!g_X.begin()) { g_log.error(...) }`, logging a boot error if init fails. That pattern is correct and intentional for peripherals where failure is real and detectable - `g_leds`, `g_ai` (ADS1115 ADC), `g_ao` (MCP4725 DAC), and `g_lte.begin()` are all I2C- or hardware-communication-based and genuinely can fail; those four compile fine and are NOT part of this fix.

The three that fail were checked directly against their implementations:

- `DigitalInputs::begin()` (`lib/di_driver/di_driver.cpp`) - a loop of `pinMode()` calls only. No I2C, no communication, nothing that can fail. Declared `void`, correctly.
- `RelayOutputs::begin()` (`lib/relay_driver/relay_driver.cpp`) - `pinMode()` + `digitalWrite()` to de-energize all relays at boot (the safe startup state). Also just GPIO writes, correctly `void`.
- `LteModem::powerOn()` (`lib/lte_modem/lte_modem.cpp`) - a fixed-duration GPIO pulse (`digitalWrite` HIGH, `delay(2200)`, `digitalWrite` LOW) with no feedback path. Correctly `void`.

None of these three functions has any way to detect or report failure - the underlying Arduino `pinMode()`/`digitalWrite()`/`delay()` calls they use don't return a status either. The `if (!g_X.begin())` wrapper was mistakenly copy-pasted onto these three from the genuinely-fallible peripherals above them in the same block. The fix is to stop checking a return value that doesn't exist and never can - not to invent a fake `bool` return on the library side that would always report success regardless of what actually happened (that would be worse: dead code masquerading as error handling).

## Fix — two edits, both in `firmware/src/main.cpp`

### Edit 1

Find (this is two consecutive lines inside a longer block of similar `if (!g_X.begin())` lines - only replace these two, leave the `g_leds.begin()` line above and the `g_ai.begin()` line below untouched):

```cpp
    if (!g_di.begin()) { g_log.error(0, "boot", "DigitalInputs::begin failed"); }
    if (!g_relays.begin()) { g_log.error(0, "boot", "RelayOutputs::begin failed"); } // de-energizes all relays - the safe startup state
```

Replace with:

```cpp
    g_di.begin(); // DigitalInputs::begin() only configures GPIO pinModes - nothing to fail, no bool to check
    g_relays.begin(); // de-energizes all relays - the safe startup state; RelayOutputs::begin() only configures GPIO - nothing to fail
```

### Edit 2

Find (leave the `g_lte.begin()` block above it untouched - that one correctly returns `bool` and compiles fine):

```cpp
    if (!g_lte.powerOn()) {
        g_log.error(0, "boot", "LteModem::powerOn failed");
    }
```

Replace with:

```cpp
    g_lte.powerOn(); // LteModem::powerOn() is a fixed-duration GPIO pulse with no feedback path - nothing to fail, no bool to check
```

Do not change anything else in `main.cpp` - not the surrounding lines, not the `g_lte.begin()` block, not any other peripheral init call.

## After both edits

Confirm exactly what you changed (both blocks, old text and new text). Don't run or claim to have run `pio`. A human will run `pio run -e esp32-s3-devkitc-1` afterward. This is the last known compile error in the project - if this clears, the build should proceed to linking `firmware.elf` and producing a final image, but that hasn't been confirmed by an actual run yet, so don't assume it's fully done until that comes back clean.

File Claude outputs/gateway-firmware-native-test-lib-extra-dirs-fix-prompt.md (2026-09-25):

# Fix: `lib_extra_dirs` not taking effect in `platformio.ini` (native test env)

## Ground rules — read before touching anything

- Do **not** rename, delete, or rewrite the *content* of any file except the exact moves listed in this prompt. Everything else in this repo — all library code under `firmware/lib/`, all test files under `firmware/test/`, `firmware/platformio.ini`'s existing content, `firmware/src/main.cpp` — is already correct and has been hand-verified by compiling it directly with `g++`. This is a narrow, mechanical fix for one specific PlatformIO configuration mistake. It is not an invitation to "clean up," refactor, reorganize, or improve anything else you notice along the way.
- Do not touch anything under `docs/`.
- If this device's real commercial name appears anywhere in the codebase or docs (it shouldn't, by standing project policy), do not write it into any file, comment, or commit message. Always refer to it only as "a commercial industrial IoT gateway reference device" if it needs to be referenced at all.
- You cannot compile or run `pio` in your own environment. Do not claim anything is "tested," "verified," "working," or "passing" in your summary — say exactly what files you moved and nothing more. A human will run the actual `pio test -e native` afterward to confirm.
- If, while doing this, you find that any of the files/paths named below don't exist or don't match what's described, **stop and report that discrepancy instead of improvising a fix**. Don't guess.

## Background (for context only — don't act on this section, it's already done)

`firmware/test/native_stubs/` is a directory of hand-written fake headers (`HardwareSerial.h`, `Preferences.h`, `LittleFS.h`, `Arduino.h`, `Update.h`, `esp_ota_ops.h`, `esp_system.h`, `system_watchdog.h`) plus one fake implementation file (`fake_system_watchdog.cpp`). These exist so that `pio test -e native` (a host-native build with no real ESP32/Arduino framework available) can compile library source files that would otherwise need real Arduino/ESP-IDF headers. `firmware/platformio.ini`'s `[env:native]` section already has:

```ini
lib_ignore = system_watchdog
lib_extra_dirs = test/native_stubs
```

`lib_ignore` is confirmed working (verified by a real `pio test -e native` run — the real `lib/system_watchdog/` folder is successfully excluded). `lib_extra_dirs` is confirmed **not** working — none of the fake headers in `test/native_stubs/` are being found by PlatformIO's Library Dependency Finder (LDF) at all, even though the directory and files genuinely exist at that path.

## The actual bug

PlatformIO's `lib_extra_dirs` directive expects each listed path to be a **parent directory that itself contains one or more library folders** — exactly the same structure as the project's own `lib/` folder, where `lib/modbus_master/`, `lib/power_safety/`, etc. are each one library. It does **not** treat the listed directory itself as a single library.

Right now, `test/native_stubs/` has all 9 files sitting **directly inside it** (flat), with no further subfolder:

```
test/native_stubs/
  HardwareSerial.h
  Preferences.h
  LittleFS.h
  Arduino.h
  Update.h
  esp_ota_ops.h
  esp_system.h
  system_watchdog.h
  fake_system_watchdog.cpp
```

Because `lib_extra_dirs = test/native_stubs` tells PlatformIO "look inside `test/native_stubs/` for library folders," and there are none (just loose files), LDF finds nothing usable there and silently contributes zero include paths — which exactly matches the observed symptom (every one of those fake headers now reports "No such file or directory," including `system_watchdog.h`, which had been working correctly before this flat layout was introduced).

## The fix — a single directory nesting change, nothing else

Move all 9 files from `test/native_stubs/` into a **new subfolder** `test/native_stubs/arduino_fakes/`, so the structure becomes:

```
test/native_stubs/
  arduino_fakes/
    HardwareSerial.h
    Preferences.h
    LittleFS.h
    Arduino.h
    Update.h
    esp_ota_ops.h
    esp_system.h
    system_watchdog.h
    fake_system_watchdog.cpp
```

Do this as a plain move (preserve every file's content byte-for-byte — do not re-type, reformat, or "fix" anything inside them). The folder name `arduino_fakes` is not sacred — if you have a strong structural reason to name it differently, that's fine, but it must be a **single new subfolder directly under `test/native_stubs/`** containing all 9 files together (they must stay together in ONE folder, not split into multiple — several of them reference each other, e.g. `fake_system_watchdog.cpp` implements the class declared in `system_watchdog.h`, both need to resolve as the same library).

**`platformio.ini` needs no change at all.** `lib_extra_dirs = test/native_stubs` already correctly points at the *parent* directory — it was correct all along; the files living directly inside it (instead of inside a subfolder) was the actual mistake. Do not add, remove, or modify any other line in `platformio.ini`.

## After the move

List the exact `mv`/file operations you performed (old path → new path, for all 9 files) in your summary, and confirm nothing else in the repository was touched. Do not attempt to run `pio` yourself — a human will run `pio test -e native` afterward (possibly after also clearing PlatformIO's build cache with `pio run -t clean -e native`, which is a separate, independent troubleshooting step not part of this fix) to confirm all four currently-failing tests (`test_modbus_master`, `test_ota_update`, `test_power_safety`, `test_ota_session`) now build.

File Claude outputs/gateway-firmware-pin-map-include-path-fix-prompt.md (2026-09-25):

# Fix: `pio run -e esp32-s3-devkitc-1` fails with `pin_map.h: No such file or directory`

## Ground rules — read before touching anything

- Touch only the single addition specified below, in `firmware/platformio.ini`. Do not modify anything else in this file or any other file.
- Never write the device's real commercial name into any file, comment, or commit message. Refer to it only as "a commercial industrial IoT gateway reference device" if it needs mentioning at all.
- You cannot compile or run `pio`. Do not claim anything is "tested," "verified," "working," or "fixed." State exactly what you changed. A human will run `pio run -e esp32-s3-devkitc-1` afterward to confirm.
- If `[env:esp32-s3-devkitc-1]`'s `build_flags` block doesn't look the way it's described below, stop and report the discrepancy instead of improvising.

## Background (context only, don't act on this part)

`pio run -e esp32-s3-devkitc-1` fails while compiling this project's own `lib/` modules with:

```
lib/ads1115_adc/ads1115_adc.cpp:4:10: fatal error: pin_map.h: No such file or directory
    4 | #include "pin_map.h"
```

`firmware/include/pin_map.h` exists and is real project code (real pin assignments) — it is not missing, it is simply not on the compiler's include search path for `lib/*` builds under this project's current `platformio.ini`. This is confirmed to be a single, project-wide gap, not a one-off: a repo-wide grep shows the following files all include `pin_map.h` the same way, and every one of them will hit this identical error once the build reaches them:

```
lib/ads1115_adc/ads1115_adc.cpp
lib/di_driver/di_driver.cpp
lib/ethernet_link/ethernet_link.cpp
lib/ethernet_link/ethernet_link.h
lib/lte_modem/lte_modem.cpp
lib/lte_ppp/lte_ppp.cpp
lib/lte_ppp/lte_ppp.h
lib/mcp4725_dac/mcp4725_dac.cpp
lib/relay_driver/relay_driver.cpp
lib/rs232_serial/rs232_serial.cpp
lib/rs232_serial/rs232_serial.h
lib/rs485_serial/rs485_serial.cpp
lib/rs485_serial/rs485_serial.h
lib/status_leds/status_leds.cpp
lib/status_leds/status_leds.h
src/main.cpp
```

Do not copy `pin_map.h` into any of these folders — that would create 11+ duplicate copies of real hardware pin-assignment code that could silently drift out of sync with each other. The correct fix is to add the project's `include/` directory to the compiler's search path once, at the environment level, so every one of these files (and any other file that references it) resolves it the same way `src/main.cpp` was always intended to.

## The fix

In `firmware/platformio.ini`, inside the `[env:esp32-s3-devkitc-1]` section, find this `build_flags` block:

```ini
build_flags =
    -D ARDUINO_USB_CDC_ON_BOOT=1
    -DBOARD_HAS_PSRAM
```

Add one new line to it:

```ini
build_flags =
    -I$PROJECT_INCLUDE_DIR
    -D ARDUINO_USB_CDC_ON_BOOT=1
    -DBOARD_HAS_PSRAM
```

`$PROJECT_INCLUDE_DIR` is PlatformIO's own built-in variable for the project's `include/` folder (resolves to `firmware/include` here) — using it instead of a hand-written relative path (`-Iinclude`) avoids any ambiguity about what directory the path is relative to. This makes `include/` visible to every compilation unit in this environment — `lib/*` and `src/*` alike — not just the files listed above.

Do not change, remove, or reorder the two existing `-D` flags, and do not touch anything else in this section (`board_build.flash_size`, `board_upload.flash_size`, `lib_deps`, `custom_sdkconfig`, etc. all stay exactly as they are).

## After the change

Confirm the one line you added and its position in `build_flags` (first line, before the two existing `-D` flags — order among `build_flags` entries doesn't functionally matter, but keep it first for readability since it's a search-path flag, not a preprocessor define). Don't attempt to run `pio` yourself — a human will run `pio run -e esp32-s3-devkitc-1` afterward. Since this fixes an include-path gap that affects 11+ files at once, expect the build to get substantially further than before, but don't assume it will complete cleanly — later files may still surface separate, unrelated issues, which is normal for a build this size and not a sign this particular fix was wrong.

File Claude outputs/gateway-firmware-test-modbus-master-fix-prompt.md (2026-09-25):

# Fix: `test_modbus_master` still fails under `pio test -e native`

## Ground rules — read before touching anything

- Same rules as the previous fix prompt: touch only the exact files listed below. Do not rename, delete, or rewrite the content of anything else. All other library code, all other tests, and `docs/` are already correct and hand-verified — leave them alone.
- Never write the device's real commercial name into any file, comment, or commit message. Refer to it only as "a commercial industrial IoT gateway reference device" if it needs mentioning at all.
- You cannot compile or run `pio`. Do not claim anything is "tested," "verified," "working," or "passing." State exactly what you changed. A human will run `pio test -e native` afterward to confirm.
- If any file/path below doesn't match what's described, stop and report the discrepancy instead of improvising.

## Background (context only, don't act on this part)

`test_modbus_master` still fails to build under `pio test -e native`, on two new errors that only appeared once an earlier, unrelated fix (moving fake headers into `test/native_stubs/arduino_fakes/`) cleared a different blocker in front of them:

```
lib/rs485_serial/rs485_serial.cpp:2:10: fatal error: pin_map.h: No such file or directory
lib/modbus_master/modbus_master.cpp:5:10: fatal error: freertos/FreeRTOS.h: No such file or directory
```

Both are the exact same underlying issue this project has hit repeatedly: a library `.cpp` file (compiled by PlatformIO as its own build step) needs a header that currently only exists somewhere NOT visible to it — either a real header that isn't on the native build's search path, or a fake stub that's only visible to one specific test's own private folder. The fix pattern is always the same: put a copy where `test/native_stubs/arduino_fakes/` (already wired into `[env:native]` via `lib_extra_dirs = test/native_stubs` in `platformio.ini` — do not touch that line, it's already correct) makes it visible to every native compilation unit, not just one test's own files.

## Step 1 — copy `pin_map.h` into the shared stub folder

`firmware/include/pin_map.h` already exists and is real project code (real pin assignments) — do not edit its content. Copy it (don't move/delete the original — it's needed for the real `esp32-s3-devkitc-1` build too) to:

```
firmware/test/native_stubs/arduino_fakes/pin_map.h
```

Exact same content, byte-for-byte.

## Step 2 — move the FreeRTOS stub folder into the shared location

`firmware/test/test_modbus_master/freertos/` currently contains three files: `FreeRTOS.h`, `task.h`, `semphr.h`. These are native-test fakes for FreeRTOS, not real code — move (not copy) the whole `freertos/` folder into the shared stub location, so it becomes:

```
firmware/test/native_stubs/arduino_fakes/freertos/FreeRTOS.h
firmware/test/native_stubs/arduino_fakes/freertos/task.h
firmware/test/native_stubs/arduino_fakes/freertos/semphr.h
```

Preserve their content exactly. After the move, `firmware/test/test_modbus_master/freertos/` should no longer exist.

`firmware/test/test_modbus_master/test_modbus_master.cpp` includes these via `#include <freertos/FreeRTOS.h>` etc. (angle brackets) — this will now resolve through the shared location instead of the old local one. No change needed to that file's include lines.

## Step 3 — consolidate the Arduino.h / Serial1 / millis / micros situation

This is the part that needs care, so read it fully before acting.

There are currently **two different `Arduino.h` files** that matter for this one test binary:

1. `firmware/test/native_stubs/arduino_fakes/Arduino.h` — the shared one (added for a different test's sake), currently contains only `millis()`.
2. `firmware/test/test_modbus_master/Arduino.h` — a test-local one containing `HardwareSerial Serial1(1);` (the actual global instance definition) plus `extern "C"` declarations for `millis()`, `micros()`, `delay()`.

`firmware/lib/modbus_master/modbus_master.cpp` (a library file) does `#include <Arduino.h>` (angle brackets) and calls both `millis()` **and** `micros()` — confirmed by grep, it uses both. Under real `pio test`, this angle-bracket include resolves through `lib_extra_dirs`, i.e. file 1 above — which is missing `micros()` entirely, so this would fail to compile even after steps 1–2.

Meanwhile `firmware/test/test_modbus_master/test_modbus_master.cpp` itself never includes `Arduino.h` directly at all — it just directly **defines** `unsigned long millis() { return 0; }` and `unsigned long micros() { return 0; }` as bare functions, and uses `Serial1.fake_reset()`, relying on `Serial1` being declared `extern` inside `HardwareSerial.h` (already shared, already fine) and defined somewhere else.

Do this, precisely:

**3a.** Edit `firmware/test/native_stubs/arduino_fakes/Arduino.h` to match this exact content (replace the whole file):

```cpp
#pragma once
#include <stdint.h>
#include "HardwareSerial.h"

// Shared native-test fake for Arduino.h. Declares (does not define) the
// three free functions modbus_master.cpp and other library sources call
// (millis/micros/delay), plus the global Serial1 instance every
// HardwareSerial consumer expects to exist - matching the real
// arduino-esp32 core's own globals. Bodies are defined per-test (in
// whichever test_*.cpp actually needs specific timing behavior), with
// matching extern "C" linkage, so this header can be shared across every
// native test without forcing one fixed implementation on all of them.

extern HardwareSerial Serial1;

#ifdef __cplusplus
extern "C" {
#endif
unsigned long millis();
unsigned long micros();
void delay(uint32_t ms);
#ifdef __cplusplus
}
#endif
```

**3b.** Edit `firmware/test/test_modbus_master/test_modbus_master.cpp`: add `#include <Arduino.h>` to its include block near the top (alongside its existing `#include "modbus_master.h"` / `#include "HardwareSerial.h"` / `freertos/*.h` includes), so this test's own translation unit sees the exact same `extern "C"` declarations that `modbus_master.cpp` sees. Do **not** remove or change its existing `unsigned long millis() { return 0; }` / `unsigned long micros() { return 0; }` definitions — those bodies stay exactly as they are; they now correctly satisfy the shared header's `extern "C"` declarations instead of floating undeclared. Also add a matching `void delay(uint32_t ms) {}` definition (a plain no-op body) right next to the existing `millis()`/`micros()` bodies, since the shared header now declares it and something must define it in this test binary.

**3c.** `test_modbus_master.cpp` still needs `Serial1` to actually be *defined* somewhere (not just declared `extern`), since it calls `Serial1.fake_reset()`. Add this one line to `test_modbus_master.cpp`, near its other global fake state (wherever makes sense given the file's existing structure — near the top, after the includes, is fine):

```cpp
HardwareSerial Serial1(1);
```

**3d.** Delete `firmware/test/test_modbus_master/Arduino.h` — its content is now fully absorbed into the shared header (declarations) plus `test_modbus_master.cpp` (definitions), so the old file is redundant. Leaving it in place risks two different `Serial1`/`millis` definitions existing at once.

## After all three steps

List every file you moved, copied, edited, or deleted, with old path → new path where relevant. Don't run or claim to have run `pio test` — say plainly that this needs a real `pio test -e native` run to confirm, same as before.

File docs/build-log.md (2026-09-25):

# Build log

## 2026-08-28 — Project initialized
- Repository structure created (hardware/, firmware/, docs/).
- ESP32-S3 fixed pin/peripheral constraints confirmed (see docs/architecture.md).
- PlatformIO project scaffolded in firmware/, configured to use the pioarduino
  platform (github.com/pioarduino/platform-espressif32) instead of the stock
  PlatformIO Espressif32 platform, to track current Arduino-ESP32 core releases.
- Toolchain sanity check (blink sketch) added at firmware/src/main.cpp — to be
  built and flashed before any real subsystem firmware work starts.

## 2026-09-03 — Power subsystem complete
- Reverse-polarity protection, surge/EMI protection, and four-rail regulation (3.3V-LOGIC,
  3.3V-LTE, 5V-RELAY, 3.3V-ANALOG-ISO) designed and simulated (ngspice inrush, margin
  verification against every part's worst-case rating).
- Schematic captured in `hardware/kicad/ioboard/` (J1 -> F1 -> Q5/U1 -> U2 -> four DC-DC
  modules; the reverse-polarity MOSFET was later renamed from Q1 to Q5 during the analog-io
  subsystem's ERC pass, to resolve a duplicate-reference collision — see `power.md`'s
  revision history). Full BOM sourced to real, in-stock part numbers.
- See `docs/subsystems/power.md` for the full writeup; items needing real hardware are
  tracked there as commissioning tests for Rev-A.

## 2026-09-04 — Core compute subsystem complete
- ESP32-S3-WROOM-1U-N16R8 bring-up: power/decoupling, EN reset circuit, GPIO0 boot circuit,
  USB-C interface (data-only, CC termination, no VBUS power path) wired pin-by-pin against
  Espressif's own hardware design guidelines and esptool's boot-mode documentation.
- Schematic captured in `hardware/kicad/lteboard/lteboard/core-compute.kicad_sch`. Caught
  and fixed a real gap here: the sheet had only been auto-saved, not explicitly saved, so
  the first commit of this file was accidentally empty — corrected once the file was
  properly saved and the real 3444-line schematic was verified against the documented
  values before committing.
- See `docs/subsystems/core-compute.md` for the full writeup.

## 2026-09-05 — Digital inputs subsystem complete
- 8 opto-isolated digital inputs across two LTV-247 ICs: field input -> current-limiting
  resistor (2.4k) -> LED -> reverse-protection diode (1N4148) -> GND_FIELD_DI, output side
  -> pull-up (10k) to 3V3_LOGIC + filter cap (100nF) to GND_LOGIC. Field connector (Phoenix
  Contact MC 1,5/9-ST-3,5) terminates all 8 channels plus the shared common return.
- Schematic captured in `hardware/kicad/ioboard/ioboard/digital_inputs.kicad_sch`. Every
  channel's pin numbers, label spelling, and diode orientation verified against the actual
  placed KiCad symbols (not assumed from a datasheet pinout diagram, which couldn't be
  reliably sourced for this part) before moving to the next channel.
- Established a clearer project-wide label-scoping convention: local labels for anything
  that never leaves one sheet, hierarchical labels plus an explicit wire on the parent sheet
  for anything shared between a specific set of subsystems, global labels reserved for
  GND_LOGIC only. Retroactively wired 3V3_LOGIC between power and digital_inputs through
  ioboard.kicad_sch's root sheet using this convention.
- See `docs/subsystems/digital-inputs.md` for the full writeup.

## 2026-09-06 — Relay outputs subsystem complete
- 4 relay channels: GPIO -> 510Ω base resistor + 10kΩ pull-down -> MMBT3904 NPN driver ->
  Panasonic ALDP105 relay coil (`5V_RELAY` rail), with a 1N4148 flyback diode across each
  coil. Local 10uF/100nF bulk+bypass caps at the `5V_RELAY` entry point, for EMI/noise
  containment rather than current capability.
- Field-side contacts terminate on an 8-position Phoenix Contact MC 1,5/8-ST-3,5 connector,
  giving every channel a fully independent COM+NO pair (no shared common return, unlike
  digital-inputs).
- Schematic captured in `hardware/kicad/ioboard/ioboard/relay_outputs.kicad_sch`. One real
  wiring bug caught and fixed before commit: the flyback diode was initially wired with
  reversed polarity, which would have put a forward-biased diode across the coil for the
  entire on-time of each transistor.
- Known limitation, documented rather than silently absorbed: the field connector is rated
  160V while the relay's own contacts are rated to 277VAC/30VDC — the connector, not the
  relay, is the practical ceiling on what this board can switch.
- See `docs/subsystems/relay-outputs.md` for the full writeup.

## 2026-09-07 — Status indication subsystem complete
- I2C GPIO expander (NXP PCA9535PW, already budgeted in `power.md`) driving 6 status LEDs
  (PWR-OK, HEARTBEAT, LTE, WIFI, ETH, FAULT), active-low sink drive. Address strapped to 0x20
  (A0/A1/A2 to `GND_LOGIC`); 4.7kΩ pull-ups on SDA/SCL; 10kΩ pull-up on the unused INT pin;
  10 spare GPIOs marked with No-Connect flags. LED colors deliberately limited to the
  red/green/yellow/orange family — blue/white were ruled out because their higher forward
  voltage leaves too little headroom on the 3.3V rail for reliable current control.
- New second hierarchical sheet on LTEBOARD (`status_indication.kicad_sch`), wired directly
  to the ESP32-S3 (GPIO8/GPIO9 for I2C, exposed as new sheet pins on `core-compute.kicad_sch`)
  — no board-to-board header involved, since both sheets live on the same physical board.
- Caught and fixed two real bugs before commit, both via full programmatic connectivity
  verification (every pin and net reconstructed from the actual file content, not just
  visual inspection): all 6 LEDs were initially wired with reversed polarity (would never
  have lit, since the cathode side had no path to a potential low enough for forward bias);
  and `core-compute.kicad_sch`'s existing `GND_LOGIC` labels were local instead of global —
  same class of bug found and fixed in `power.kicad_sch` during analog-io's ERC pass, which
  would have left this new sheet's ground electrically isolated from the MCU's.
- ERC deferred to a single project-wide pass once every subsystem is built, a project-wide
  decision replacing the per-subsystem ERC pass used for analog-io.
- See `docs/subsystems/status-indication.md` for the full writeup.

## 2026-09-07 — Analog I/O subsystem complete
- 2 analog inputs (0-10V / 4-20mA stuffing option) + 1 analog output (0-10V), isolated from
  GND_LOGIC: ADS1115 (ADC) + MCP4725 (DAC) share one I2C bus on the isolated side, crossing
  to GND_LOGIC through an ISO1540 bidirectional isolator. Output stage is a real DAC + LM2904
  gain stage (gain 3.004), not PWM+filter — the ESP32-S3 has no internal DAC. Surfaced a real
  gap in the existing rail budget: the 0-10V output needs a new isolated ~15V rail, sourced
  from 5V-RELAY. That gap was closed separately on `main` (see the 2026-09-08 entry below)
  before this branch was merged back in.
- Schematic captured in `hardware/kicad/ioboard/ioboard/analog_io.kicad_sch`. One real wiring
  bug (output-stage feedback network wired to break the loop) and one naming ambiguity
  (channel-1/channel-2 resistor designators swapped) caught and fixed during capture.
- Full KiCad ERC (Electrical Rules Check) run to a fully-explained clean state: 15 findings
  reviewed and excluded with a written, per-violation comment (cross-sheet power-driver false
  positives, documented spare/deferred headroom, deferred GPIO assignment, the deferred 15V
  rail) — nothing silently suppressed. This pass also surfaced and fixed two pre-existing
  bugs outside this sheet: a duplicate `Q1` reference collision in `power.kicad_sch` (renamed
  to `Q5`) and an inconsistent local/global `GND_LOGIC` labeling on the same sheet (both
  recorded in `power.md`'s revision history, not just here).
- See `docs/subsystems/analog-io.md` for the full writeup.

## 2026-09-08 — Power: isolated 15V rail for analog output stage
- Solved the 15V problem flagged during analog-io's design: added U7 (Recom RK-0515S,
  isolated DC-DC, 4.5-5.5V in / 15V out / 66mA, 3kVDC isolation) to `power.kicad_sch`,
  powered from `5V-RELAY`. Verified wiring programmatically (+VIN->5V_RELAY,
  -VIN->GND_LOGIC, +VOUT->15V_ANALOG_ISO, -VOUT->GND_ANALOG_ISO), confirming -VIN and
  -VOUT resolve to two distinct nets — isolation preserved.
- Completed the root-sheet routing in `ioboard.kicad_sch`: added a `15V_ANALOG_ISO` output
  pin to the power sheet symbol and wired it through to `analog_io`'s existing
  `15V_ANALOG_ISO` input pin (on U13's V+, already anticipated in that branch's design).
- Corrected the LM2904 load-budget entry in `power.md`: the old single row put both op-amp
  packages on 3.3V-LOGIC with an imprecise per-amp current figure. Split into U12
  (input-buffer stage, 3.3V-ANALOG-ISO) and U13 (output gain stage, new 15V-ANALOG-ISO
  rail), both at the TI-datasheet-verified 0.7-1.2 mA dual-package draw.
- See `docs/subsystems/power.md`'s revision history for the full writeup.

## 2026-09-10 — RS485 and RS232 subsystems complete
- **RS485 (isolated):** Mornsun TD321S485H-A transceiver module, copying Mornsun's own
  Fig. 2 harsh-environment reference circuit exactly (GDT + series R + TVS + common-mode
  choke + external 4.7kΩ bias). Phoenix Contact MC 1,5/3-ST-3,5 connector. Schematic
  captured in `hardware/kicad/ioboard/ioboard/rs485.kicad_sch`.
- **RS232:** TI MAX3232EIPWR front end (switched from an initially-misidentified
  "MAX3232EI" part number, not a real orderable SKU), no added protection network (the
  receiver's own ±25V-safe-unpowered rating plus reference-design evidence supported
  skipping one), reusing RS485's connector family. Schematic captured in
  `hardware/kicad/ioboard/ioboard/rs232.kicad_sch`.
- ERC policy formalized for both and going forward: deferred to a single project-wide pass
  once every subsystem is built, rather than per-subsystem before each merge — matching
  status-indication's approach, superseding the earlier per-subsystem policy.
- See `docs/subsystems/rs485.md` and `docs/subsystems/rs232.md` for full writeups.

## 2026-09-13 — Ethernet and WiFi subsystems complete
- **Ethernet:** WIZnet W5500 SPI controller, Würth 7499010441 magjack — exact part number
  and internally-terminated construction confirmed directly from its own datasheet (no
  external Bob-Smith network needed). Schematic captured in
  `hardware/kicad/lteboard/lteboard/ethernet.kicad_sch`. One label typo found (C7,
  `1nF/2kW` should read `1nF/2kV`) — fixed 2026-09-23, see below.
- **WiFi:** small scope — the ESP32-S3-WROOM-1U's radio is already fixed at the module;
  this subsystem was just the external antenna path (SMA jack, coax pigtail, gain-limited
  2dBi antenna to stay under the module's 2.33dBi certified-antenna ceiling), added
  directly to `core-compute.kicad_sch`.
- See `docs/subsystems/ethernet.md` and `docs/subsystems/wifi.md` for full writeups.

## 2026-09-19 — LTE subsystem complete; both boards merged into one KiCad project
- **LTE:** Quectel EG915U-EU, the largest/most complex subsystem — own rail (`VBAT_LTE`,
  retapped from ~3.3V to ~3.82V for real margin against the TX transient, see `power.md`),
  own UART through a TXB0102 level shifter, SIM interface, PWRKEY/RESET power-control
  circuit, own antenna path. Schematic captured in
  `hardware/kicad/lteboard/lteboard/lte.kicad_sch`.
- All 11 subsystems now schematic-complete. `ioboard/` and `lteboard/` merged into one
  active project, `hardware/kicad/ioboard+lteboard/`, so roadmap steps 6 (fine-grained pin
  assignment) and 7 (board-to-board wiring) could be done with both boards visible at
  once. `ioboard/`/`lteboard/` frozen as historical record from this date. Full detail:
  `docs/board-merge.md`.
- See `docs/subsystems/lte.md` for the full writeup.

## 2026-09-22/23 — Roadmap steps 6 and 7 closed; project-wide ERC clean; firmware starting
- **Step 6 (fine-grained pin assignment):** all 28 cross-subsystem signals given real
  GPIOs on `core-compute.kicad_sch` — I2C, Ethernet SPI, LTE UART+control, RS232/RS485
  UARTs, 8 digital inputs, 4 relay outputs. Full table in `docs/architecture.md`. A
  pre-existing defect was caught and fixed in the same pass: USB-C D+/D- were wired to the
  wrong GPIOs (ordinary pins instead of the module's actual native-USB pins), meaning USB
  data would never have worked as originally built. Five DI signals landed on GPIO3/39/
  42/46/47 — checked against Espressif's official ESP32-S3 datasheet for strapping/JTAG
  concerns; accepted as safe (two are real strapping pins but safe for this use, three
  were incorrectly flagged as risky in earlier project notes and are actually plain
  GPIOs). Analog output's DAC-vs-PWM question, open since early planning, was confirmed
  already decided in practice: MCP4725 I2C DAC, not PWM+filter.
- **Step 7 (board-to-board wiring):** two connector pairs added (`J_PWR` 2x5, `J_SIG`
  2x12, Samtec TSW/SSW 2.54mm) carrying `3V3_LOGIC`/`VBAT_LTE`/`GND_LOGIC`/`EARTH` and 18
  of 24 signal pins (6 spare, reserved). Full pinout in `docs/architecture.md`.
- **Final project-wide ERC pass:** found and fixed real defects across several sheets —
  two SnapEDA-imported power-module symbols (PS1/RK-0515S, U13/R1SX-3.33.3-R) had their
  return-side output pin mistyped, reading as a driven-output conflict; five isolated
  power/ground nets needed `PWR_FLAG`s their symbol-level connectivity couldn't establish
  across sheets; the LTE modem's VDD_EXT/USIM1_VDD pins were mistyped power-input instead
  of power-output; three genuinely-floating Ethernet PMODE pins got pull-up resistors;
  several genuinely-unused pins (ADS1115, core-compute) got No-Connect flags instead of
  being left ambiguous. ERC confirmed clean 2026-09-23.
- `firmware/platformio.ini` corrected to declare the real ESP32-S3-WROOM-1U-N16R8 module
  (16MB flash, 8MB octal PSRAM) instead of a generic N8 devkit profile.
- Full reasoning trail for all of the above: `CLAUDE.md`'s open items and each affected
  subsystem doc's revision history.
- **Firmware development starts from here.**

## 2026-09-23/24 — Firmware F1-F4 written, all modules compile/gcc-verified

- Full firmware implementation written against the real, merged schematic's pin
  assignments: protocol/logic layer (Modbus RTU/TCP, MQTT payloads, DI/AI/relay
  register mapping), all 10 hardware drivers, and the industrial-grade layer
  (commissioning portal, MQTT resilience + TLS, local rule engine, OTA with
  rollback, NTP, event logging, WireGuard VPN, an application-layer outbound
  allowlist, LTE registration resilience, brownout safe-state handling).
- System integration (F4): FreeRTOS task scheduler split (dedicated Modbus RTU
  polling task + cooperative `main.cpp` loop for everything else), task watchdog,
  WireGuard config storage/wiring, a from-scratch OTA update-trigger flow with
  application-level ECDSA signature verification (mbedtls, after two "obvious"
  ESP-IDF/arduino-esp32 signing mechanisms were researched and ruled out as
  actually broken or inapplicable under `framework = arduino`), and LTE backhaul
  via arduino-esp32's built-in PPP library as a real third connectivity tier
  (`Ethernet -> LTE -> WiFi`, Ozcan's explicit priority call).
- Verification at this stage was write + compile/gcc-verify only — real hardware
  didn't exist yet, and Ozcan's own call (2026-09-24) was to defer the actual
  `pio run` build/link pass until the whole of F4 was finished, then do it once,
  together, against the complete integrated firmware rather than piecemeal.
- Full module-by-module detail: `docs/roadmap.md`'s "Firmware roadmap" section
  (F1-F4).

## 2026-09-25 — First real `pio run`/`pio test` build verification — F4 closed

- Ran the real build on Ozcan's machine (WSL, real `pio` binary) for the first
  time against the complete F1-F4 firmware above. Took 4 iterations to reach a
  clean build/link — a duplicate `libsodium` install colliding at the SCons
  level, a missing project-wide include path for `pin_map.h`, three stray
  `void`-to-`bool` checks in `main.cpp`'s boot sequence, and a nested-vs-top-level
  `MqttOutbox` class mismatch left over from an earlier library split — none of
  them catchable by gcc/g++ stub-compiling alone, all specific to the real
  ESP32-S3 build path.
- `pio run -e esp32-s3-devkitc-1` now succeeds end to end: links `firmware.elf`,
  builds `firmware.bin`/`firmware.factory.bin` (RAM 21.8%, Flash 32.7% against the
  build's reported budget).
- `pio test -e native` ran for the first time against the real PlatformIO/Unity
  test runner — **132 of 132 test cases passed** across all 15 native-testable
  modules.
- This is the first real, non-gcc-stub verification of the whole codebase.
  Hardware still isn't required for any of it — Rev-A prototype PCB (roadmap step
  8) remains the next physical milestone, and the only thing gating F5
  (functional hardware bring-up).
- Full detail: `docs/roadmap.md`'s F4.1 section.

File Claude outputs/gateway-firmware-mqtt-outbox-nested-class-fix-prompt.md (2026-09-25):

# Fix: `pio run -e esp32-s3-devkitc-1` fails at link with undefined references to `MqttClientWrapper::MqttOutbox::*`

## Ground rules — read before touching anything

- Touch only `firmware/lib/mqtt_client_wrapper/mqtt_client_wrapper.h`, and only the two exact edits specified below (moving one line). Do not touch `firmware/lib/mqtt_client_wrapper/mqtt_client_wrapper.cpp`, `firmware/lib/mqtt_outbox/mqtt_outbox.h`, `firmware/lib/mqtt_outbox/mqtt_outbox.cpp`, or `firmware/test/test_mqtt_outbox/test_mqtt_outbox.cpp` — all four were read and confirmed correct as-is; this is not a bug in any of them.
- Never write the device's real commercial name into any file, comment, or commit message. Refer to it only as "a commercial industrial IoT gateway reference device" if it needs mentioning at all.
- You cannot compile or run `pio`. Do not claim anything is "tested," "verified," "working," or "fixed." State exactly what you changed. A human will run `pio run -e esp32-s3-devkitc-1` afterward to confirm.
- If `mqtt_client_wrapper.h` doesn't look the way it's described below, stop and report the discrepancy instead of improvising.

## Background (context only, don't act on this part)

`pio run -e esp32-s3-devkitc-1` now compiles the entire codebase cleanly and reaches the linking stage for the first time, then fails with:

```
ld: .../mqtt_client_wrapper.cpp.o: undefined reference to `MqttClientWrapper::MqttOutbox::enqueue(char const*, char const*)'
ld: .../mqtt_client_wrapper.cpp.o: undefined reference to `MqttClientWrapper::MqttOutbox::getItem(int)'
ld: .../mqtt_client_wrapper.cpp.o: undefined reference to `MqttClientWrapper::MqttOutbox::compact()'
ld: .../mqtt_client_wrapper.cpp.o: undefined reference to `MqttClientWrapper::MqttOutbox::MqttOutbox()'
collect2: error: ld returned 1 exit status
```

This was root-caused by reading all four relevant files directly (not guessed from the error text alone):

`firmware/lib/mqtt_outbox/mqtt_outbox.h` declares `MqttOutbox` as an ordinary, self-contained, **top-level** class (own `#pragma once`, no enclosing class). `firmware/lib/mqtt_outbox/mqtt_outbox.cpp` implements its four methods the same way, as plain top-level definitions (`MqttOutbox::enqueue(...)`, etc.) — these compile to symbols like `MqttOutbox::enqueue(...)`, with no enclosing class in the mangled name. `firmware/test/test_mqtt_outbox/test_mqtt_outbox.cpp` also uses it this way, as a plain top-level class — which is why the native unit tests never caught this bug: they exercise `MqttOutbox` directly and never touch `mqtt_client_wrapper.h` at all.

The bug is in `firmware/lib/mqtt_client_wrapper/mqtt_client_wrapper.h`. Its `private:` section currently contains this line:

```cpp
private:
    #include "mqtt_outbox.h"
    PubSubClient client_;
    const char *client_id_;
    MqttOutbox outbox_;
```

`#include "mqtt_outbox.h"` sits *inside the body of `class MqttClientWrapper`*. The preprocessor pastes `mqtt_outbox.h`'s full text — including `class MqttOutbox { ... };` — directly into that spot, which makes the compiler define `MqttOutbox` as a **class nested inside `MqttClientWrapper`**, i.e. `MqttClientWrapper::MqttOutbox`, only in this one file. Every reference to `MqttOutbox` inside `mqtt_client_wrapper.h`/`.cpp` (the `outbox_` member, `MqttOutbox::CAPACITY`, `outbox_.enqueue(...)`, etc.) therefore resolves to the nested type `MqttClientWrapper::MqttOutbox`, and the compiler emits calls to `MqttClientWrapper::MqttOutbox::enqueue(...)` and friends. But the only compiled implementation of those methods, in `mqtt_outbox.cpp`, is the plain top-level `MqttOutbox::enqueue(...)` — a different, unrelated symbol. Two different C++ types end up sharing one name depending on which file the header text landed in, and the linker can't match the nested-type calls to the top-level-type definitions.

This is leftover from the project's earlier split of `mqtt_outbox` out of `mqtt_client_wrapper` (done specifically so native tests wouldn't need to fake `PubSubClient`): the class was evidently written inline as a nested class first, then extracted into its own file — but the `#include` was left positioned inside the class body instead of being moved up to the top of the file with the other includes. Real hardware builds are the first thing that actually links `mqtt_client_wrapper.cpp` against `mqtt_outbox.cpp`, which is why this only surfaces now.

## The fix — one line moved, in `firmware/lib/mqtt_client_wrapper/mqtt_client_wrapper.h`

### Edit 1: add the include to the top of the file, with the other includes

Find:

```cpp
#pragma once
#include <stdint.h>
#include <functional>
#include <PubSubClient.h>
#include <Client.h>
```

Replace with:

```cpp
#pragma once
#include <stdint.h>
#include <functional>
#include <PubSubClient.h>
#include <Client.h>
#include "mqtt_outbox.h"
```

### Edit 2: remove the include from inside the class body

Find:

```cpp
private:
    #include "mqtt_outbox.h"
    PubSubClient client_;
    const char *client_id_;
    MqttOutbox outbox_;
```

Replace with:

```cpp
private:
    PubSubClient client_;
    const char *client_id_;
    MqttOutbox outbox_;
```

Nothing else in the `private:` section (the backoff fields, `subscribed_topic_`, `message_callback_`, `flushOutbox()`, `tryReconnect()`) changes — only the one `#include` line moves. After this change, `MqttOutbox` is the same top-level class everywhere it's used — inside `mqtt_client_wrapper.h`/`.cpp`, in `mqtt_outbox.cpp`, and in the native test — matching the mangled symbols the linker is looking for.

Do not change anything else in this file, and do not touch `mqtt_client_wrapper.cpp`, `mqtt_outbox.h`, `mqtt_outbox.cpp`, or the test file — all four are correct as they are; only the include's position in the header was wrong.

## After the change

Confirm the one line you moved (removed from inside the `private:` block, added to the top-of-file include list) and show both resulting snippets. Don't run or claim to have run `pio`. A human will run `pio run -e esp32-s3-devkitc-1` afterward. If this is right, linking should succeed and produce `firmware.elf`/the final flashable image — but that hasn't been confirmed by an actual run yet, so don't assume it's done until that comes back clean.

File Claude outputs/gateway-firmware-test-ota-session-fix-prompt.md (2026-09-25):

# Fix: `test_ota_session` fails under `pio test -e native`

## Ground rules — read before touching anything

- Touch only the exact files listed below. Everything else in the repo — all other library code, all other tests, `docs/`, `platformio.ini`'s existing content — is already correct and hand-verified. Do not rename, delete, or rewrite the content of anything not explicitly named here.
- Never write the device's real commercial name into any file, comment, or commit message. Refer to it only as "a commercial industrial IoT gateway reference device" if it needs mentioning at all.
- You cannot compile or run `pio`. Do not claim anything is "tested," "verified," "working," or "passing." State exactly what you changed. A human will run `pio test -e native` afterward to confirm.
- If any file/path below doesn't match what's described, stop and report the discrepancy instead of improvising.

## Background (context only, don't act on this part)

`test_ota_session` fails to build under `pio test -e native` with two errors:

```
lib/image_verify/image_verify.h:4:10: fatal error: mbedtls/sha256.h: No such file or directory
lib/ota_session/ota_session.h:7:10: fatal error: NetworkClientSecure.h: No such file or directory
```

Both come from PlatformIO's Library Dependency Finder pulling in the *entire* `lib/ota_session/` folder (and, transitively, `lib/image_verify/`) as soon as `test/test_ota_session/test_ota_session.cpp` references `ota_session.h` — even though that test only actually exercises one small pure function, `isOtaVersionAcceptable()`. Everything else in `ota_session.cpp` (`runOtaSession()`) does real HTTPS I/O and flash writes and is explicitly documented in its own header comment as "deliberately NOT unit-testable... reviewed by hand" — it was never meant to be pulled into the native test build at all.

Unlike the previous fakes this project has written for other tests, faking `NetworkClientSecure`, `HTTPClient`, and real SHA-256/ECDSA crypto (`mbedtls`) well enough to actually exercise `runOtaSession()` would be a large, risky undertaking for something nothing currently tests. The correct fix here is not a fake — it's the same kind of physical split already done for `mqtt_outbox` (which was pulled out of `mqtt_client_wrapper` for the identical reason: a small, dependency-free piece stuck inside a folder that also needs a heavy third-party API). `isOtaVersionAcceptable()` has zero dependency on HTTPClient/NetworkClientSecure/mbedtls — it's a two-line `uint32_t` comparison — so pulling it into its own tiny library removes the need to fake any of those three APIs at all.

Confirmed before writing this prompt: `isOtaVersionAcceptable()` is called from exactly one place in the whole repo (`runOtaSession()`, inside `ota_session.cpp` itself) besides the test. `src/main.cpp` never calls it directly — it only calls `runOtaSession()`, which will still work unchanged after this split.

## Step 1 — create the new library

Create `firmware/lib/ota_version_check/ota_version_check.h`:

```cpp
#pragma once
#include <stdint.h>

// Pulled out of ota_session.h/.cpp (2026-09) so the native test build for
// this one pure comparison doesn't need to fake NetworkClientSecure,
// HTTPClient, or mbedtls just to reach it - those three are only needed by
// runOtaSession() itself, which does real HTTPS I/O and flash writes and is
// documented (ota_session.cpp's own header comment) as reviewed by hand,
// not natively unit-tested. This function has zero dependency on any of
// that, so splitting it into its own library is the same fix already
// applied to mqtt_outbox (pulled out of mqtt_client_wrapper for the
// identical reason).

// True if `declared_version` (from an incoming OTA trigger command) is
// strictly newer than `current_version` (the device's own running
// firmware version) - i.e. whether this OTA should proceed at all.
bool isOtaVersionAcceptable(uint32_t declared_version, uint32_t current_version);
```

Create `firmware/lib/ota_version_check/ota_version_check.cpp`:

```cpp
#include "ota_version_check.h"

bool isOtaVersionAcceptable(uint32_t declared_version, uint32_t current_version) {
    return declared_version > current_version;
}
```

## Step 2 — remove it from `ota_session`, wire up the new dependency

In `firmware/lib/ota_session/ota_session.h`:
- Remove this line (the declaration now lives in the new header):
  ```cpp
  bool isOtaVersionAcceptable(uint32_t declared_version, uint32_t current_version);
  ```
- Add `#include "ota_version_check.h"` near the top, alongside the existing includes (`"ota_trigger.h"`, `"device_config.h"`, etc.), so anything that includes `ota_session.h` still transitively sees the declaration.

In `firmware/lib/ota_session/ota_session.cpp`:
- Add `#include "ota_version_check.h"` near the top, alongside its existing includes.
- Remove the function body (do not change anything else in this file):
  ```cpp
  bool isOtaVersionAcceptable(uint32_t declared_version, uint32_t current_version) {
      return declared_version > current_version;
  }
  ```
- Leave the call site at line 43 (`if (!isOtaVersionAcceptable(cmd.version, current_version)) {`) exactly as it is — it will now resolve against the new header's declaration instead.

## Step 3 — point the test at the new, small header

In `firmware/test/test_ota_session/test_ota_session.cpp`, change:
```cpp
#include "ota_session.h"
```
to:
```cpp
#include "ota_version_check.h"
```
Nothing else in this file needs to change — it only ever called `isOtaVersionAcceptable()`.

## Step 4 — delete the now-unnecessary stub

Delete `firmware/test/test_ota_session/NetworkClientSecure.h`. It was a placeholder stub (`class NetworkClientSecure {};`) added only so `ota_session.h`'s declarations could parse for this test — after step 3, this test no longer includes `ota_session.h` at all, so the stub has nothing left to support.

## After all four steps

List every file you created, edited, or deleted, with a one-line note per file of what changed. Don't run or claim to have run `pio test` — say plainly that this needs a real `pio test -e native` run to confirm. Do not touch `platformio.ini` — this fix needs no configuration change, only the file moves/edits above.

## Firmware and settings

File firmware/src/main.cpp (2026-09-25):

#include <Arduino.h>
#include <Wire.h>
#include <NetworkClientSecure.h>
#include <WiFiClient.h>
#include <string.h> // memcpy - used by the OTA MQTT message callback
                     // below; not otherwise pulled in explicitly
                     // anywhere in this file before now

#include "pin_map.h"

// --- Local I/O (F2) ---
#include "di_driver.h"
#include "relay_driver.h"
#include "ads1115_adc.h"
#include "mcp4725_dac.h"
#include "status_leds.h"

// --- Connectivity (F2) ---
#include "wifi_link.h"
#include "ethernet_link.h"
#include "lte_modem.h"
#include "lte_ppp.h"
#include "rs485_serial.h"

// --- Protocol/state (F1) ---
#include "io_state.h"
#include "mqtt_payload.h"

// --- Industrial layer (F3) ---
#include "device_config.h"
#include "commissioning_portal.h"
#include "mqtt_tls_config.h"
#include "mqtt_client_wrapper.h"
#include "rule_engine.h"
#include "event_log.h"
#include "ntp_time.h"
#include "ota_update.h"
#include "power_safety.h"
#include "reset_reason.h"
#include "net_allowlist.h"

// --- System integration (F4) ---
#include "system_watchdog.h"
#include "modbus_master.h"
#include "wireguard_link.h"
#include "ota_trigger.h"
#include "ota_session.h"

// ============================================================================
// F4: system integration. Ties every module above together into one boot
// sequence + one running system, on the architecture agreed for this
// project (docs/roadmap.md's Firmware roadmap, F4 entry):
//
//   - Modbus master polling -> its OWN FreeRTOS task (ModbusMasterTask),
//     because its frame timing can't tolerate being stalled by a slow TLS
//     handshake or OTA flash write happening elsewhere.
//   - Everything else -> this file's loop(), cooperative/poll()-driven,
//     the same pattern most of these modules were already written in.
//   - SystemWatchdog is fed from both - either task hanging reboots the
//     device (docs/roadmap.md's F4 entry has the full reasoning).
//
// WireGuard (wireguard_link.h) is now wired: DeviceConfig
// (device_config.h) has a real NVS-backed storage path
// (setWireguard()/getWireguard*()/hasWireguardConfig(), added
// 2026-09-24) and commissioning_portal's form collects the fields.
// It's started in setup() AFTER NTP sync, not just after the network
// comes up - ESPHome's own WireGuard component documents the tunnel
// as requiring a synchronized system clock, and this project follows
// that rather than guessing it doesn't matter. If NTP sync fails,
// WireGuard is deliberately skipped this boot (logged, not silently
// retried in loop() yet) rather than started against a clock that may
// be wrong.
//
// OTA's update-trigger flow is now wired too: this device subscribes
// to "<device_id>/cmd/ota" and, on a message that parses as a valid
// ota_trigger.h command, downloads/verifies/installs it via
// ota_session.h's runOtaSession() - see that file's own header comment
// for the full flow (allowlist gate on a PRE-CONFIGURED OTA host, not
// the trigger's own untrusted url field; HTTPS download; SHA-256 +
// ECDSA-P256 signature check against a key compiled into firmware
// (image_verify.h/ota_signing_key.h) BEFORE the new image is ever
// marked bootable). Parsing happens inside the MQTT callback itself
// (fast, pure, no I/O - ota_trigger_parse() never blocks); the actual
// download+flash-write is deferred to loop() via g_ota_pending, since
// that part can legitimately take tens of seconds and has no business
// running inside a PubSubClient callback. ota_update.h's own boot-time
// rollback confirmation (safety-critical, independent of how an update
// gets triggered) was already wired before this and is unchanged.
//
// LTE is now a real backhaul tier, not just status monitoring:
// lib/lte_ppp (arduino-esp32's built-in PPP library, wrapping ESP-IDF's
// esp_modem component) gives the modem an actual PPP/PDP bridge, the
// missing piece this comment used to flag here. lib/lte_modem was
// trimmed down to power/reset GPIO control only (its old AT+CSQ/
// AT+CREG-polling transport moved out - see that header's own note);
// lte_at_parse.h/.c was deleted as dead code once nothing called
// sendAt() anymore (confirmed via repo-wide grep before deleting - no
// other dependents). See lib/lte_ppp/lte_ppp.h for the full mechanism
// (model choice, UART-conflict avoidance with Rs485Serial, the
// deliberate choice to leave PWRKEY/RESET owned solely by lte_modem)
// and docs/roadmap.md's F4 entry for what was researched/verified
// before writing any of it.
//
// Network priority: Ethernet, then LTE, then WiFi as a last resort.
// NOT this file's own assumption - Ozcan was asked explicitly (two
// separate questions, 2026-09-24) once LTE actually existed to
// reconsider the order against, rather than this being decided
// unilaterally:
//   1. Order: chose Ethernet -> LTE -> WiFi over keeping WiFi second.
//      The real reference device's documented pattern is wired-primary
//      with automatic CELLULAR failover, not WiFi, so LTE moved ahead
//      to match that. WiFi stays as a tier (not dropped entirely, which
//      would've matched the reference device even more closely) because
//      it's genuinely useful for this project's own bench/dev work
//      without Ethernet or a live SIM - a need the commercial reference
//      device's architecture doesn't have to account for.
//   2. Timing: chose to KEEP connectNetwork() boot-time-only rather than
//      add live failover monitoring now. connectNetwork() still runs
//      once, in setup() - there's no "a backhaul dropped mid-operation,
//      switch automatically" monitoring in loop() for ANY of the three
//      tiers (not a gap LTE introduces - Ethernet/WiFi already had none).
//      The real reference device's "automatic" cellular failover implies
//      live monitoring; this build's boot-time-only fallback is a real,
//      explicitly-scoped fidelity gap against that, not a hidden one -
//      live monitoring was deliberately left as a separate, distinctly-
//      larger follow-up (periodic health checks, switch-on-drop,
//      fail-back-on-recovery logic), not folded into this pass.
// ============================================================================

// ---- Module instances (file-scope, single instance each - matches
// this project's existing main.cpp precedent) ----

DeviceConfig g_config;
CommissioningPortal g_portal;

DigitalInputs g_di;
RelayOutputs g_relays;
AdsAnalogInput g_ai;
McpAnalogOutput g_ao; // L9 (2026-09-24): initialized and begin()-checked below, but
                       // nothing currently calls set()/write() on it - no consumer
                       // wired up yet. Left initialized rather than removed since the
                       // hardware channel exists on the board; flagging so this doesn't
                       // read as "finished and in use" until something actually drives it.
StatusLeds g_leds;
io_state_t g_io_state;

WifiLink g_wifi;
EthernetLink g_eth;
LteModem g_lte;
LtePpp g_lte_ppp;

NetworkClientSecure g_mqtt_tls_client;
NetworkClientSecure g_ota_https_client; // OTA downloads get their OWN
    // NetworkClientSecure, deliberately separate from g_mqtt_tls_client
    // above - that one's underlying TCP connection is MQTT's own
    // persistent session; running an unrelated HTTPS GET through it
    // (ota_session.h) would disrupt it, not just borrow it
WiFiClient g_mqtt_plain_client;
MqttTlsConfig g_mqtt_tls_config;
MqttClientWrapper *g_mqtt = nullptr; // constructed in setup() once the
                                      // transport (TLS vs plain) and
                                      // broker/client-id strings from
                                      // g_config are known

NtpTime g_ntp;
EventLog g_log;
PowerSafety g_power_safety;
NetAllowlist g_allowlist;

rule_engine_t g_rules;
OtaUpdate g_ota;

Rs485Serial g_rs485;
ModbusMasterTask g_modbus;
SystemWatchdog g_watchdog;
WireguardLink g_wireguard;

char g_device_id[64] = "gateway";
char g_mqtt_host[128] = "";
uint16_t g_mqtt_port = 1883;
bool g_mqtt_use_tls = false;

// WireGuard config, loaded from DeviceConfig in setup() (before
// connectNetwork(), so g_wg_peer_endpoint is ready in time for the
// allowlist population below) but not actually started until after
// NTP sync succeeds - see this file's header comment for why.
bool g_wg_configured = false;
char g_wg_private_key[64] = "";
char g_wg_peer_public_key[64] = "";
char g_wg_peer_preshared_key[64] = "";
char g_wg_local_address[32] = "";
char g_wg_local_netmask[32] = "";
char g_wg_peer_endpoint[128] = "";
uint16_t g_wg_peer_port = 0;
uint16_t g_wg_keepalive = 0;

// OTA trigger staging - set (synchronously, from inside the MQTT
// message callback) once a "<device_id>/cmd/ota" message parses as a
// valid command; cleared and acted on from loop() (see this file's
// header comment for why the actual download is deferred there rather
// than run inside the callback).
OtaTriggerCommand g_pending_ota_cmd;
bool g_ota_pending = false;
char g_ota_raw_payload[800]; // must hold up to
                              // MqttClientWrapper::MQTT_RX_BUFFER_SIZE
                              // (700) bytes plus a null terminator,
                              // with headroom

unsigned long g_last_publish_ms = 0;
const unsigned long PUBLISH_INTERVAL_MS = 5000;

// BUG FIX (2026-09-24, L8): StatusLed::HEARTBEAT existed in
// status_leds.h's enum from the start but nothing in loop() ever
// called g_leds.set(StatusLed::HEARTBEAT, ...) - the LED (or its
// software slot, on hardware where it's not physically wired) just
// sat unused. A simple 1Hz toggle (500ms on, 500ms off) is the
// standard "firmware is alive and loop() hasn't hung" indicator this
// LED exists for, same idiom as g_last_publish_ms/PUBLISH_INTERVAL_MS
// just above.
unsigned long g_last_heartbeat_toggle_ms = 0;
bool g_heartbeat_led_state = false;
const unsigned long HEARTBEAT_BLINK_INTERVAL_MS = 500;

// ---- Helpers ----

static void connectNetwork() {
    // Ethernet -> LTE -> WiFi. Reordered 2026-09-24 (Ozcan's call,
    // asked explicitly rather than decided unilaterally - see
    // docs/roadmap.md's F4 entry) once LTE existed to reconsider
    // against: the real reference device's documented pattern is
    // wired-primary with automatic CELLULAR failover, not WiFi, so LTE
    // moved ahead of WiFi to match that priority. WiFi stays as a
    // last-resort tier rather than being dropped entirely - useful for
    // bench/dev work without Ethernet or a live SIM, which the
    // reference device's own architecture doesn't need to account for
    // but this project's development workflow does.
    //
    // Ethernet: short bounded wait, not indefinite - a device with no
    // cable connected should fall through to the next tier rather than
    // hang here forever.
    g_eth.begin();
    unsigned long start = millis();
    while (!g_eth.isConnected() && (millis() - start) < 5000) {
        delay(50);
        g_watchdog.feed();
    }
    if (g_eth.isConnected()) {
        g_log.info(0, "net", "ethernet up");
        return;
    }

    // LTE - second tier, only attempted if an APN is configured
    // (DeviceConfig::hasLteApn(), commissioning_portal's "lte_apn"
    // field - an unconfigured APN means this device has no SIM/LTE
    // hardware fitted, or the installer simply hasn't set it up yet;
    // either way, attempting PPP.begin() against that is pointless).
    // PRECONDITION: LteModem::begin()+powerOn() must already have run
    // (setup() does this immediately before calling connectNetwork(),
    // not after - see this file's header comment on why that ordering
    // matters). Same bounded-wait-plus-watchdog-feed shape as Ethernet
    // above, split into two waits (attach, then data mode) because
    // lte_ppp.h's connection sequence has two distinct stages to wait
    // through - see that header for why.
    if (g_config.hasLteApn()) {
        char apn[64] = "";
        char sim_pin[16] = "";
        g_config.getLteApn(apn, sizeof(apn));
        g_config.getLteSimPin(sim_pin, sizeof(sim_pin));

        if (!g_lte_ppp.begin(apn, sim_pin[0] != '\0' ? sim_pin : nullptr)) {
            g_log.warn(0, "net", "lte ppp begin failed");
        } else {
            start = millis();
            while (!g_lte_ppp.isAttached() && (millis() - start) < 20000) {
                delay(50);
                g_watchdog.feed();
            }
            if (!g_lte_ppp.isAttached()) {
                g_log.warn(0, "net", "lte network registration timed out");
            } else if (!g_lte_ppp.switchToDataMode()) {
                g_log.warn(0, "net", "lte switch to data mode failed");
            } else {
                start = millis();
                while (!g_lte_ppp.isConnected() && (millis() - start) < 20000) {
                    delay(50);
                    g_watchdog.feed();
                }
                if (g_lte_ppp.isConnected()) {
                    g_log.info(0, "net", "lte up");
                    return;
                }
                g_log.warn(0, "net", "lte data connection timed out");
            }
        }
    } else {
        g_log.warn(0, "net", "no lte apn configured - skipping to wifi");
    }

    // WiFi - third/last-resort tier.
    if (g_config.hasWifiCredentials()) {
        char ssid[64], pass[64];
        g_config.getWifiSsid(ssid, sizeof(ssid));
        g_config.getWifiPassword(pass, sizeof(pass));
        g_wifi.begin(ssid, pass);
        start = millis();
        while (!g_wifi.isConnected() && (millis() - start) < 15000) {
            delay(50);
            g_watchdog.feed();
        }
        if (g_wifi.isConnected()) {
            g_log.info(0, "net", "wifi up");
            return;
        }
        g_log.warn(0, "net", "wifi connect timed out");
    } else {
        g_log.warn(0, "net", "no ethernet, lte, or wifi backhaul available");
    }
}

static bool networkIsUp() {
    return g_eth.isConnected() || g_wifi.isConnected() || g_lte_ppp.isConnected();
}

static void publishState() {
    if (g_mqtt == nullptr || !g_mqtt->isConnected()) return;

    mqtt_gateway_state_t mqtt_state;
    io_state_to_mqtt_state(&g_io_state, g_ntp.isSynced() ? g_ntp.nowUnix() : 0, &mqtt_state);

    char payload[256];
    int len = mqtt_payload_build_json(&mqtt_state, payload, sizeof(payload));
    if (len <= 0) return;

    char topic[96];
    snprintf(topic, sizeof(topic), "%s/state", g_device_id);
    g_mqtt->publish(topic, payload);
}

static void readLocalInputs() {
    bool di[DigitalInputs::CHANNEL_COUNT];
    g_di.readAll(di);
    for (int i = 0; i < DigitalInputs::CHANNEL_COUNT; i++) {
        io_state_set_di(&g_io_state, i, di[i] ? 1 : 0);
    }

    for (int i = 0; i < AdsAnalogInput::CHANNEL_COUNT; i++) {
        int16_t raw;
        if (g_ai.readChannel(i, &raw)) {
            io_state_set_ai(&g_io_state, i, (uint16_t)raw);
        }
    }
}

static void applyRelayCommands(const int commands[4], const int applied[4]) {
    for (int i = 0; i < 4; i++) {
        if (applied[i]) {
            g_relays.setChannel(i, commands[i] != 0);
            io_state_set_relay(&g_io_state, i, commands[i] != 0 ? 1 : 0);
        }
    }
}

// ---- Arduino entry points ----
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
void loop() {
    readLocalInputs();

    int relay_commands[4];
    int relay_applied[4];
    rule_engine_evaluate(&g_rules, &g_io_state, relay_commands, relay_applied);
    applyRelayCommands(relay_commands, relay_applied);

    if (g_mqtt != nullptr) {
        g_mqtt->loop();
    }

    unsigned long now = millis();
    if ((long)(now - (g_last_publish_ms + PUBLISH_INTERVAL_MS)) >= 0) {
        publishState();
        g_last_publish_ms = now;
    }

    // No periodic LTE poll()/reconnect-recovery loop here, by design -
    // matches this project's existing fidelity level for Ethernet/WiFi
    // too: connectNetwork() runs once, at boot, in setup(); none of the
    // three backhauls gets live reconnect monitoring from loop() yet.
    // PPP.connected() (unlike the old AT+CREG polling this replaced) is
    // a direct read of PPPClass's own already-event-backed state, not
    // an AT round-trip, so no interval throttle is needed here either -
    // matches how WIFI/ETH below are read every loop() pass.

    g_leds.set(StatusLed::WIFI, g_wifi.isConnected());
    g_leds.set(StatusLed::ETH, g_eth.isConnected());
    g_leds.set(StatusLed::LTE, g_lte_ppp.isConnected());
    g_leds.set(StatusLed::PWR_OK, true);
    g_leds.set(StatusLed::FAULT, g_mqtt_host[0] != '\0' && (g_mqtt == nullptr || !g_mqtt->isConnected()));

    // BUG FIX (2026-09-24, L8): see g_last_heartbeat_toggle_ms's
    // declaration above - this is the actual toggle, same
    // now-vs-last-timestamp idiom as the publishState() throttle a
    // few lines up, just with a much shorter interval.
    if ((long)(now - (g_last_heartbeat_toggle_ms + HEARTBEAT_BLINK_INTERVAL_MS)) >= 0) {
        g_heartbeat_led_state = !g_heartbeat_led_state;
        g_leds.set(StatusLed::HEARTBEAT, g_heartbeat_led_state);
        g_last_heartbeat_toggle_ms = now;
    }

    if (g_ota_pending) {
        g_ota_pending = false;
        // Real HTTPS download + flash write - can legitimately take
        // tens of seconds. Feeds the watchdog itself throughout (see
        // ota_session.h's own header comment) - nothing extra needed
        // here for that, same as connectNetwork()'s and the
        // commissioning portal's own long-running loops elsewhere in
        // this file.
        bool ota_ok = runOtaSession(g_pending_ota_cmd, g_config, g_ota_https_client,
                                     g_allowlist, g_watchdog, g_log);
        if (ota_ok) {
            g_log.info(0, "ota", "update committed - rebooting to apply");
            delay(200); // let the log line actually get written before reboot
            ESP.restart();
            return; // unreachable, but explicit rather than relying on
                    // ESP.restart() never returning - same style as
                    // the commissioning-portal path above
        }
        // Failure: runOtaSession() already logged why. Current
        // firmware just keeps running - no crash/reboot needed, the
        // inactive OTA slot simply gets overwritten by the next
        // attempt.
    }

    g_watchdog.feed();
    delay(10);
}

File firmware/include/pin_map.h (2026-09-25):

#pragma once
// Single source of truth for GPIO/bus assignment on core-compute.kicad_sch.
// Mirrors docs/architecture.md's "Core-compute pin assignment" table
// (verified 2026-09-23) - if that table changes, update here too, and
// vice versa. Do not duplicate these numbers elsewhere in firmware.

// --- Shared I2C bus (ADS1115 ADC, MCP4725 DAC, PCA9535PW expander) ---
#define PIN_I2C_SDA        8
#define PIN_I2C_SCL        9

// I2C addresses (confirmed against docs/subsystems/analog-io.md and
// status-indication.md - address-pin strapping on the real schematic,
// not assumed).
#define I2C_ADDR_ADS1115   0x48  // ADDR -> GND
#define I2C_ADDR_MCP4725   0x60  // A0 -> GND
#define I2C_ADDR_PCA9535   0x20  // A0/A1/A2 -> GND_LOGIC

// --- Ethernet (WIZnet W5500, SPI) ---
#define PIN_ETH_CS         10
#define PIN_ETH_MOSI       11
#define PIN_ETH_SCLK       12
#define PIN_ETH_MISO       13
#define PIN_ETH_INT        14

// --- LTE modem (Quectel EG915U-EU, UART + control lines) ---
#define PIN_LTE_TXD        17  // MCU -> modem
#define PIN_LTE_RXD        18  // modem -> MCU
#define PIN_LTE_PWRKEY     15
#define PIN_LTE_RESET      16

// --- Relay outputs (4x, NPN transistor driver stage) ---
#define PIN_RELAY1         7
#define PIN_RELAY2         38
#define PIN_RELAY3         43  // shares module's default UART0 TX - fine, UART0 unused
#define PIN_RELAY4         44  // shares module's default UART0 RX - fine, UART0 unused

// --- RS232 (MAX3232EIPWR) ---
#define PIN_RS232_TXD      5
#define PIN_RS232_RXD      6

// --- RS485 (isolated transceiver) ---
#define PIN_RS485_TXD      1
#define PIN_RS485_RXD      2

// --- Digital inputs (8x, opto-isolated, active-low - see di_driver.h) ---
#define PIN_DI1            40
#define PIN_DI2            41
#define PIN_DI3            48
#define PIN_DI4            3   // strapping pin (JTAG src select) - safe, see architecture.md
#define PIN_DI5            39
#define PIN_DI6            42
#define PIN_DI7            46  // strapping pin (boot mode) - safe in normal operation
#define PIN_DI8            47

// Note: analog input (ADS1115) and analog output (MCP4725) have no
// dedicated MCU GPIO - both ride the shared I2C bus above (see
// architecture.md: "analog_io only exposes I2C pins today").

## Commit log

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2026-08-30 Power subsystem: resolve unverified-item review, add W5500 commissioning test item
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2026-08-30 Power subsystem: step 5 results (protection design + sequencing, corrects 2 teardown part misreads)
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2026-08-30 Power subsystem: correct step 5 surge protection - single TVS insufficient, adopt two-stage coordinated clamp
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2026-08-30 Power subsystem: apply approved fixes (Zener clamp, inrush flag) + final recheck of steps 1-6
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2026-08-31 power: replace two-stage SMBJ36A surge clamp with single TI TVS3300 (Flat-Clamp)
    Found TI's Flat-Clamp TVS family while sourcing the surge-stage app note. Checked
    every standoff option (TVS4000 at 40V standoff still clamps at 50.3V, above the
    MagI3C 42V limit); TVS3300 (33V standoff, 40V max clamp) is the only member that
    actually stays under 42V. Replaces the previously-approved but still-unfinalized
    two-stage design (SMBJ36A + TBD ferrite bead + TBD secondary TVS), removing two
    open part-number gaps from the step-8 simulation backlog. Sourcing checked:
    active production, in stock at DigiKey/Mouser, both shipping to Turkey.
2026-08-31 power: correct 3.3V-ANALOG-ISO module part number (R1SX-3305 -> R1SX-3.33.3-R)
    R1SX-3305 is 3.3V-in/5V-out per Recom's naming scheme, not a match for a rail
    named 3.3V-ANALOG-ISO. This was flagged as a provisional/open item when first
    specced (step 4); resolved now while wiring the rail in schematic capture.
    Correct part: R1SX-3.33.3-R, same package/pinout family, 1kVDC isolation.
    [ioboard.kicad_pcb, ioboard.kicad_sch]
2026-08-31 gitignore: exclude KiCad lock/autosave marker files
    Untrack #auto_saved_files# and ~ioboard.kicad_sch.lck, which got swept into
    the previous commit by mistake (a plain 'git commit -m' with no pathspec
    picked up everything already staged in the index, not just the two docs
    files I'd just added). These are transient KiCad session markers, not real
    project content -- added explicit .gitignore patterns so this doesn't
    recur.
2026-09-03 power: step 8 inrush-current simulation, resolved (no NTC needed)
    Simulated in ngspice (not hand-waved): source stepped to 30V through F1's
    cold resistance (0.12 ohm, datasheet Rmin), Q1's RDS(on) (3.5 mohm), and
    the input capacitor bank (8x4.7uF), against a near-zero source impedance
    worst case. Peak inrush 161A, tau ~6.9us -- well within Q1's 400A/100us
    pulsed rating (~2.5x margin) and far too brief to meaningfully heat the
    PTC fuse's thermal mass. No NTC thermistor needed. Closes the last open
    item from the power subsystem's own plan; also crossed off two other
    open items resolved during step 7 (feedback dividers) and the LM74610-Q1
    switch (Toshiba part sourcing caveat, now moot).
    Co-Aut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
2026-09-03 power: schematic capture complete (protection chain, 4 rails, isolated analog, hierarchical/global labels)
    Commits the finished power.kicad_sch: J1/F1/Q1/U1/U2 protection chain,
    four regulated DC-DC modules (U3-U6) with correct feedback networks,
    TVS3300 surge clamp, R1SX-3.33.3-R isolated analog supply. GND_LOGIC
    exposed as a global label; the four rail outputs + GND_ANALOG_ISO
    exposed as hierarchical sheet pins on the parent ioboard.kicad_sch.
    ERC clean apart from expected 'not connected to anything' warnings on
    labels with no consumer yet (no other subsystem sheet exists).
    Also fixes .gitignore: '#auto_saved_files#' was being silently treated
    as a comment line (leading '#'), not a patter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
    [ioboard.kicad_sch, power.kicad_sch]
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2026-09-03 power: document the inrush-sim cross-check evidence (not just the result)
    Adds the two independent hand-calculation cross-checks (decay time
    constant and peak current via Ohm's law) that were given verbally but
    not yet written into the record -- this is what actually establishes
    the simulation is trustworthy, not just that it executed without error.
    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
2026-09-03 power: further schematic refinements (C1 value, EN wiring, and other fixes)
    Continued hand-editing in KiCad after the last commit -- captures the
    current state of power.kicad_sch and ioboard.kicad_sch.
    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
    [ioboard.kicad_sch, power.kicad_sch]
2026-09-03 power: steps 9-13 (margin verification, sequencing/brown-out, acceptance criteria, BOM, sign-off)
    Closes out the power subsystem's own plan in full. Step 10's brown-out
    check is real analysis, not paperwork: worst-case LTE-burst-induced rail
    sag (~0.52V, from the board's own low series resistance) checked against
    the MagI3C modules' UVLO threshold (3.3V max) and the 10V minimum design
    input -- ~3x margin, no sequencing dependency found between rails. One
    new commissioning item added for real-supply verification at Rev-A,
    consistent with the project's established pattern. Consolidated BOM and
    concrete acceptance criteria included.
    Claud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
2026-09-03 docs: rewrite for clarity and tone across the repo
    Consolidates the power subsystem doc's inline dated 'Correction' sections
    into a single current-state writeup plus a revision-history table at the
    end, trims repeated self-narration and confidence hedging throughout, and
    tightens README/architecture/roadmap/KiCad-README wording. No technical
    content changes -- part numbers, values, and conclusions are unchanged.
    Also updates R1SX-3.33.3-R's reference designator to U6 (was P51) and
    marks the operating temperature range (-20C/+60C) as confirmed.
    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
2026-09-03 hardware: add power subsystem BOM as a CSV
    hardware/bom/ had only a placeholder -- the BOM existed as a markdown
    table inside power.md, not as something orderable/importable. Adds a
    real CSV with ref, part, role, MPN, manufacturer, and distributor link
    per line.
    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
    [power_bom.csv]
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2026-09-04 core-compute: schematic capture complete, plan closed out
    lteboard KiCad project created with the ESP32-S3-WROOM-1U minimum
    system: power/decoupling, EN reset RC, GPIO0 boot circuit with manual
    reset/boot buttons, native USB (D+/D-, CC1/CC2 termination, series
    resistors), all against GND_LOGIC/3V3_LOGIC. VBUS deliberately left
    unconnected -- USB stays data-only, avoiding an unarbitrated second
    power path alongside the field-power rail. Module and USB connector
    (Molex 216989-0001) both matched to real sourced parts. Three items
    deferred to Rev-A bring-up as commissioning tests, consistent with the
    power subsystem's pattern.
    Also carries a small leftover fix from the power subsystem: U6's
    ref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
    [core-compute.kicad_sch, lteboard.kicad_pcb, lteboard.kicad_sch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]
2026-09-04 docs: add core-compute sources to datasheets README + BOM CSV
    Same gap as last time on power -- sources existed inline in
    core-compute.md but hadn't been added to the shared datasheets index
    or given a real BOM file. Adds the Espressif schematic checklist page,
    esptool boot-mode docs, and Molex connector to datasheets/README.md,
    plus hardware/bom/core_compute_bom.csv matching the power subsystem's
    BOM format.
    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
    [core_compute_bom.csv]
2026-09-04 core-compute: source SW1/SW2 to a real part number
    Buttons have real footprint/mechanical variety like the USB connector
    did, so leaving them as "generic" in the BOM was inconsistent with how
    the power subsystem handles connectors and modules. Sourced to
    E-Switch TL1150AF070Q (SPST-NO momentary tactile, through-hole,
    confirmed in stock at DigiKey) and added its datasheet entry.
    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
    [core_compute_bom.csv]
2026-09-04 hardware: commit the actual core-compute schematic content
    The tracked file was still the bare KiCad template (8 lines, no
    components) -- the real wiring only existed in KiCad's autosave
    because it was never explicitly saved (Ctrl+S) before the earlier
    sign-off commit. Recovered and saved in KiCad; this commits the real
    3444-line sheet: U1 (ESP32-S3-WROOM-1), J1 (USB-C receptacle),
    C1-C3, R1-R6, SW1-SW2, matching docs/subsystems/core-compute.md
    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
    [core-compute.kicad_sch]
2026-09-04 docs: full repo audit — fix stale status, wrong filename, missing build-log entries
    - roadmap.md: mark core compute DONE (was already merged/signed off but
    unmarked in the ordered list)
    - README.md: status section still said core compute was next; it's done,
    digital inputs is next
    - core-compute.md: two references to the schematic as core_compute.kicad_sch
    (underscore) corrected to the real filename core-compute.kicad_sch (hyphen)
    - build-log.md: hadn't been touched since project init; added entries for
    the power and core-compute subsystem completions, including the
    autosave/save gap caught this session
    - kicad/README.md: updated from future tense to reflect that both
    power.kic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
2026-09-04 hardware: fix U1 footprint to the -1U (external antenna) variant
    U1 was assigned RF_Module:ESP32-S3-WROOM-1 (built-in PCB antenna),
    contradicting the documented decision in core-compute.md to use the
    -1U module (external U.FL antenna). Corrected to
    PCM_Espressif:ESP32-S3-WROOM-1U, sourced from Espressif's own KiCad
    library. Value field also updated to read ESP32-S3-WROOM-1U.
    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
    [core-compute.kicad_sch]
2026-09-04 digital-inputs: build plan + step 1 requirements
    8-channel opto-isolated digital input subsystem, IOBOARD. Plan follows
    the same shape as power/core-compute. Step 1 locks real numbers:
    - LTV-247 specs cross-checked against DigiKey, LCSC, and the official
    Lite-On family datasheet (an initial bad datasheet pull claimed
    1-channel/SIP-4, contradicted by two independent sources and caught
    before it reached any design decision)
    - Current-limiting resistor sized across the full 10-30V input range
    (2.4k, 1W, ~4.3x margin under LED max at 30V) with the low-end
    current shortfall vs. the datasheet's 5mA CTR test point documented
    and tracked as a Rev-A commissioning item rather than glossed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
2026-09-05 digital-inputs: schematic capture complete, plan closed out
    All 8 channels wired across two LTV-247 ICs (U7 A-D, U8 A-D), each
    identical: field input -> series R (2.4k) -> LED -> reverse-protection
    diode (1N4148) -> GND_FIELD_DI, phototransistor -> pull-up (10k) to
    3V3_LOGIC + filter cap (100nF) to GND_LOGIC. Field connector J2
    (Phoenix Contact MC 1,5/9-ST-3,5, same family as the power input
    connector) terminates all 8 channels plus the shared common return.
    Also establishes a clearer project-wide label-scoping convention,
    worked out this session: local labels for anything that never leaves
    one sheet, hierarchical labels + an explicit wire on the parent sheet
    for anything shared between a s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
    [digital_inputs.kicad_sch, ioboard.kicad_sch]
2026-09-05 digital-inputs: close remaining documentation gaps
    Full audit before merge, per request:
    - Added hardware/bom/digital_inputs_bom.csv — this was missing entirely;
    power and core-compute both have a dedicated BOM CSV alongside their
    markdown BOM table, digital-inputs didn't. Caught a real CSV-quoting
    bug while writing it: J2's part name contains commas
    ("Phoenix Contact MC 1,5/9-ST-3,5") and needs quoting, same issue
    already solved once for J1 in power_bom.csv - fixed and verified by
    parsing the file back with Python's csv module before committing.
    - roadmap.md: marked digital inputs DONE (was already complete but
    unmarked, same gap as core-compute had)
    - README.md: status sect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
    [digital_inputs_bom.csv]
2026-09-05 relay-outputs: build plan + driver stage and connector locked
    Panasonic ALDP105 relay re-verified against Panasonic's own product page
    (coil 5V/125ohm/40mA, contacts 5A/277VAC SPST-NO). Driver stage designed
    around a generic MMBT3904 NPN transistor (Nexperia datasheet): 510ohm base
    resistor sized for ~3.8x saturation margin using the conservative hFE_min,
    10k base pull-down for a defined-off boot state, 1N4148 flyback diode
    reusing the part already qualified in digital-inputs.
    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
    [digital_inputs.kicad_sch, ioboard.kicad_sch, relay_outputs.kicad_sch]
2026-09-06 relay-outputs: schematic capture complete, plan closed out
    All 4 channels wired: K1-K4 (Panasonic ALDP105) driven by Q1-Q4 (Nexperia
    MMBT3904) through R26-R33 (510ohm base / 10k pull-down pairs) and D9-D12
    (1N4148 flyback), contacts broken out independently to J3 (Phoenix Contact
    MC 1,5/8-ST-3,5, 8 positions). Added C21/C22 (10uF/100nF bulk+bypass) at
    the 5V_RELAY entry point for EMI/noise reasons -- documented as design
    decision 5, with corrected reasoning (coil inductance already rate-limits
    the current step, so this isn't about regulator transient response the
    way core-compute's WiFi-burst caps were).
    Root sheet now wires relay_outputs' 5V_RELAY hierarchical pin to power's
    output, verifi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
    [digital_inputs.kicad_sch, ioboard.kicad_sch, relay_outputs.kicad_sch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]
2026-09-07 analog-io: Step 1 locked - front end, isolation crossing, output stage
    2 AI + 1 AO, 0-10V/4-20mA per-channel stuffing option, isolation extended
    to the output. Real parts selected with datasheet-verified math: ADS1115,
    ISO1540 (not ISO1541 - needs bidirectional SCL), MCP4725, LM2904 (x2
    instances), SMBJ15CA input protection. Caught LM2904's single-supply
    input common-mode ceiling (~V+ minus 1.5-2V) before it became a wiring
    bug - input divider/burden values sized to respect it with margin.
    Found a real gap versus the existing power budget: no rail exceeds 5V,
    but a true 0-10V output needs headroom above that. Flagged a new
    isolated ~15V rail requirement (Recom R05P215S off the existing
    5V-R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
2026-09-07 analog-io: Step 3 connector locked
    Phoenix Contact MC 1,5/4-ST-3,5 (same family as J1/J2/J3): 4 positions,
    AI1/AI2/AO each with a signal pin, sharing one common GND_ANALOG_ISO
    return rather than a per-channel return - unlike relay-outputs' fully
    independent contacts, the analog channels already share one isolated
    ground plane by design, so a shared return adds no isolation/noise
    tradeoff, just fewer pins.
    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
2026-09-07 analog-io: schematic capture complete, Step 6 verification started
    Step 5: analog_io.kicad_sch built and verified pin-by-pin - ADS1115 ADC,
    ISO1540 I2C isolator, MCP4725 DAC, 2x LM2904 physical packages (input
    buffers + output gain stage), SMBJ15CA TVS protection per channel,
    stuffing-option dividers, output feedback network, and the J4 field
    connector. Root-sheet integration confirmed on ioboard.kicad_sch.
    Two real issues caught and fixed during capture: an output-stage feedback
    network wired to break the loop (R_f tied to GND instead of the -/R_in
    node), and ambiguous resistor reference designators across the two input
    channels.
    Step 6: schematic-level verification checks done (address c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
    [analog_io.kicad_sch, digital_inputs.kicad_sch, ioboard.kicad_sch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]
2026-09-07 analog-io: ERC clean, Steps 6-9 closed, subsystem complete
    KiCad ERC run on analog_io.kicad_sch (plus the directly-tied root-sheet
    pin) to a fully-explained clean state: 15 findings reviewed and excluded
    with a written, per-violation comment (cross-sheet power-driver false
    positives, documented spare/deferred headroom, deferred GPIO assignment,
    the deferred 15V_ANALOG_ISO rail) -- nothing silently suppressed.
    Two real, pre-existing bugs outside this sheet were caught and fixed
    along the way, both recorded in power.md's own revision history:
    - Duplicate reference collision: power.kicad_sch's reverse-polarity FET
    was also Q1, colliding with relay_outputs.kicad_sch's Q1-Q4. Renamed
    to Q5 (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
    [analog_io.kicad_sch, analog_io_bom.csv, digital_inputs.kicad_sch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]
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2026-09-07 status-indication: fix GND_LOGIC scope, add sheet + PCA9535PW component placement
    - core-compute.kicad_sch: converted 5 local GND_LOGIC labels to global_label,
    matching the project convention (global labels reserved for GND_LOGIC only).
    Local scope would have left the new status-indication sheet's GND_LOGIC
    electrically isolated from the MCU's ground - a real bug caught before wiring.
    - lteboard.kicad_sch / lteboard.kicad_pro: added the new status_indication
    hierarchical sheet as LTEBOARD's second child sheet.
    - status_indication.kicad_sch: new sheet, components placed (PCA9535PW I2C GPIO
    expander, 6x status LED, 6x 680R LED resistor, 2x 4.7k I2C pull-up, 1x 10k INT
    pull-up, 1x 1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
    [core-compute.kicad_sch, lteboard.kicad_sch, status_indication.kicad_sch]
2026-09-07 status-indication: complete schematic capture, cross-sheet wiring, docs, and BOM
    - status_indication.kicad_sch: full wiring completed (address straps, power/ground,
    I2C pull-ups, INT pull-up, decoupling, 6 LED channels). Caught and fixed two real bugs
    via full programmatic connectivity verification (every pin/net reconstructed from the
    actual file, not just visual inspection): all 6 LEDs were initially wired with reversed
    polarity (would never have lit), and a new hierarchical 3V3_LOGIC label was placed
    floating (same name, no wire, so not actually part of the net). 10 spare GPIOs marked
    with No-Connect flags.
    - core-compute.kicad_sch: converted 5 local GND_LOGIC labels to global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
    [core-compute.kicad_sch, lteboard.kicad_sch, status_indication.kicad_sch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]
2026-09-08 power: add isolated 15V rail (U7, RK-0515S) for analog output gain stage
    Solves the 15V problem flagged during analog-io's design: U13's output gain
    amplifier needed an isolated 15V supply, and 15V_ANALOG_ISO had already been
    placed as a hierarchical label on its V+ pin with nothing driving it.
    - Added U7 (Recom RK-0515S, isolated DC-DC, 4.5-5.5V in / 15V out / 66mA,
    3kVDC isolation) to power.kicad_sch. Verified wiring: +VIN->5V_RELAY,
    -VIN->GND_LOGIC, +VOUT->new hierarchical label 15V_ANALOG_ISO,
    -VOUT->GND_ANALOG_ISO. Confirmed -VIN and -VOUT resolve to two distinct
    nets (isolation preserved), via a from-scratch KiCad connectivity script
    (S-expression parser + coordinate-transfo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
    [ioboard.kicad_sch, power.kicad_sch, power_bom.csv]
2026-09-08 power: add status-indication's LED current to the 3.3V-LOGIC budget
    Closes a loose end from status-indication's build: the 6 status LEDs'
    ~11.5 mA worst-case current (all on simultaneously, (3.3V - ~2V generic LED
    Vf)/680R per channel) was flagged for power.md at the time but never
    actually added. Negligible against existing margin (~650mA load vs.
    850mA-1A sizing) - no module or sizing change needed, just closing the
    documentation gap. Updated roadmap.md's status-indication note to match.
    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
2026-09-10 Project-wide documentation consistency pass
    Corrects stale status lines (digital-inputs, relay-outputs, analog-io said less-complete than they were), closes two real cross-file gaps that were flagged but never applied (status-LED current budget in power.md, and analog-io's 15V rail part number - power.md actually used RK-0515S, not the R05P215S candidate analog-io.md still described), and syncs roadmap.md/README.md/CLAUDE.md's subsystem status against each subsystem's own doc. No schematic or design content changed.
    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
2026-09-10 Lock RS232 front end, protection, and connector decisions
    Front end: MAX3232EI, one channel used (T1/R1), 0.1uF charge-pump caps
    per the 3.0-3.6V table (matches 3V3_LOGIC). Protection: none added,
    beyond the transceiver's own on-chip ESD and +/-25V-safe-unpowered
    receiver rating - reasoned out in rs232.md decision 3, including the
    narrow residual miswiring risk that's flagged rather than silently
    accepted. Connector: reuses RS485's Phoenix Contact MC 1,5/3-ST-3,5
    (TXD/RXD/GND), resolving the DB9-vs-terminal-block question from
    reference-hardware evidence. Also fixes a stale README.md claim that
    RS232 was isolated (it isn't - power.md's own isolation table already
    said so).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
2026-09-10 Recover rs485.kicad_sch and its root-sheet integration
    Both the rs485 sheet block in ioboard.kicad_sch and the rs485.kicad_sch
    file itself had disappeared from the working tree sometime between
    today's 09:00 and 10:52 KiCad auto-backups (isolated removal - diffing
    the two backups showed nothing else changed). Recovered by extracting
    both files from ioboard-backups/ioboard-2026-09-10_090053.zip, verified
    byte-for-byte against that backup and structurally intact (balanced
    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
    [ioboard.kicad_sch, rs485.kicad_sch]
2026-09-10 a problem about rs485 solved
    [rs232.kicad_sch]
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2026-09-13 Complete Ethernet subsystem: schematic capture done, termination network confirmed via direct datasheet read
    [ethernet.kicad_sch, lteboard.kicad_sch, status_indication.kicad_sch]
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2026-09-13 Complete WiFi subsystem: antenna path (J2 SMA jack, EARTH-bonded shield, RF pin fed by pigtail)
    [core-compute.kicad_sch, ethernet.kicad_sch, wifi_bom.csv]
2026-09-19 Complete LTE subsystem: schematic capture, master-sheet integration, and the VBAT_LTE rail fix
    - lte.kicad_sch: modem (EG915UEUAC-N05-SNNSA), TXB0102 UART level shifter, pre-biased
    transistor PWRKEY/RESET_N drive (Q4/Q5), SIM interface + ESD protection (D1, now with
    all 4 channels wired including the SIM VDD line), antenna matching network, VBAT
    decoupling. Two schematic-level gaps found while verifying the master-sheet integration
    (D1's unwired 4th ESD channel, two missing No-Connect flags on U4) are fixed and
    re-verified against a fresh netlist reconstruction.
    - lteboard.kicad_sch: LTE sheet symbol + its 6 hierarchical pins added and checked
    pin-for-pin against lte.kicad_sch's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
    [ioboard.kicad_sch, lte.kicad_sch, lte_bom.csv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]
2026-09-19 Step 6: pin assignment and wiring on ioboard+lteboard
    - core-compute: fix USB D+/D- to native GPIO19/GPIO20 (was on GPIO13/14)
    - analog_io: expose ISO1540 logic-side I2C as hierarchical labels (bidirectional)
    - core-compute: add 14 hierarchical labels for ethernet/lte/rs485/rs232 pin assignment
    - root sheet: wire all 14 signals to their subsystems, confirm I2C 3-way merge
    (analog_io + core-compute + status_indication)
    - root sheet: VBAT_LTE tied power<->lte (casual, ahead of the formal
    board-to-board connector decision, which stays a step 7 item; 3V3_LOGIC
    intentionally left split for the same reason)
    [analog_io.kicad_sch, core-compute.kicad_sch, ioboard+lteboard.kicad_sch]
2026-09-20 added missing hierarchical labels for core-compute, digitil_inputs and relay_output
    [core-compute.kicad_sch, digital_inputs.kicad_sch, ioboard+lteboard.kicad_sch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]
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2026-09-23 docs: bring rs485.md current — resolve carried-forward items, GPIO assignment, ERC clean
    Claude-Session: https://claude.ai/code/session_01XQWHeQbZ2xcFXMmipeoLGC
2026-09-25 Firmware F1-F4 complete, first real pio run/pio test pass; docs synced
    Full firmware implementation (protocol/logic, drivers, industrial layer,
    system integration) committed for the first time. Fixed 4 real build
    issues found by the first actual pio run (duplicate libsodium install,
    missing include path, 3 bad bool checks in main.cpp, a nested-class
    mismatch in mqtt_client_wrapper). Build now links cleanly and all 132
    native tests pass. Updated roadmap.md, build-log.md, README.md, and
    subsystems/lte.md to match; removed two stale duplicate docs; added
    managed_components and sdkconfig to gitignore.
    [partitions_16mb_ota.csv]
2026-09-25 docs: confirm ARDUINO_USB_CDC_ON_BOOT=1 is correct, not a guess
    Checked against the real board manifest and Arduino core source -
    neither sets this macro, so the true default is 0 (UART0). This
    board's USB-C connector is wired to native USB, so the override is
    required. Verification only, no code changes.
